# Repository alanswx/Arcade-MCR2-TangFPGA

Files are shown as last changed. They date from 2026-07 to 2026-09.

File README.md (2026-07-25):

# Bally Midway MCR2 Arcade Core for Gowin Tang FPGAs

Standalone port of the Bally Midway MCR arcade families for Sipeed Tang
FPGA boards — no MiSTer/HPS required. **MCR-2** (Tron, Domino Man,
Satan's Hollow, Wacko, Kozmik Kroozr, Two Tigers), **MCR-3/91490**
(Tapper — hardware-verified — plus Timber and Discs of Tron), and
**MCR-1** (Kick, Kickman, Solar Fox; builds, unverified). The flagship
target is the **Tang Console 60K**: each family's games in one bitstream,
selected at runtime from an on-screen menu, ROMs loaded from a single
microSD card shared by every family (pack format v2). The roadmap toward
the full-series multi-core jukebox is at the top of TODO.md.

| Board | Status |
|---|---|
| **Tang Console 60K** (GW5AT-60) | MCR-2: all six games + OSD menu. MCR-3: Tapper working (SDRAM sprites), Timber/DoT staged. 720p HDMI with audio (DDR3 framebuffer); analog RGB at 31/15 kHz for real cabinets; USB gamepad; SD ROM loading; <10 s watchdog-guarded cold boot |
| Tang Primer 25K (GW5A-25) | Domino Man over HDMI (single game per build, BSRAM-limited) |
| Tang Console 138K (GW5AST-138) | Stale — needs the 60K backport |

New here? Read [handoff_v7_jukebox.md](handoff_v7_jukebox.md) for the
current platform state and runway.

Deeper docs: build gotchas and architecture notes in [CLAUDE.md](CLAUDE.md),
open issues in [TODO.md](TODO.md), bench hookup in
[docs/bench_wiring.md](docs/bench_wiring.md), cabinet shield spec in
[docs/universal_mcr_shield_spec.md](docs/universal_mcr_shield_spec.md),
porting plan for the other MCR generations in
[docs/mcr_core_roadmap.md](docs/mcr_core_roadmap.md).

---

## 1. Generate the ROM hex tables

ROM zips (MAME sets) go in `roms/` — they are **not** in the repo. Then,
from the repo root:

```sh
python3 tools/merge_roms.py tron     # or domino / shollow / wacko / kroozr / twotiger
```

This writes the `rom_*.hex` tables the build bakes into BSRAM and sets the
board's `game_config.vh`. On the 60K the baked game only decides **what
boots with no SD card** — every game is reachable at runtime from the OSD.

## 2. Build

Headless (recommended; macOS paths shown — see CLAUDE.md for why the IDE
flow needs extra care):

```sh
GWLIB=/Applications/GowinIDE.app/Contents/Resources/Gowin_EDA/IDE/lib
GW=/Applications/GowinIDE.app/Contents/Resources/Gowin_EDA/IDE/bin/gw_sh
cd mcr2_console60k
DYLD_LIBRARY_PATH="$GWLIB" DYLD_FRAMEWORK_PATH="$GWLIB" "$GW" build.tcl
```

The bitstream lands at `mcr2_console60k/impl/pnr/mcr2_console60k.fs`.
Prebuilt images for all six games are kept in `bitstreams/`.

IDE builds work too (open `mcr2_console60k/mcr2_console60k.gprj`, Run All)
but several project settings must be exactly right — read the Gotchas
table in CLAUDE.md first; in particular **Place & Route → Place Option
must be 2** or HDMI silently dies.

## 3. Flash the board

With [openFPGALoader](https://github.com/trabucayre/openFPGALoader)
(`brew install openfpgaloader`), board connected over USB-C:

```sh
# quick test - loads SRAM, lost at power-off
openFPGALoader -b tangconsole bitstreams/console60k_tron.fs

# make it the POWER-ON default - writes the SPI flash
openFPGALoader -b tangconsole -f bitstreams/console60k_tron.fs
```

The `-f` form replaces whatever was in flash (e.g. NESTang) — reflash that
the same way if you want it back. The Gowin Programmer GUI works as well
(External Flash Mode → exFlash Erase, Program).

## 4. Make the SD card (all six games, switchable from the menu)

The ROM pack lives in **raw sectors starting at sector 2048** (1 MiB in) —
no filesystem involved, and it coexists with a normally-formatted card
(standard SD formatting starts the first partition at 4 MiB+; existing
files are untouched).

```sh
python3 tools/make_rompack.py                 # builds mcr_rompack.img from roms/
sudo python3 tools/write_rompack.py           # lists candidate cards
sudo python3 tools/write_rompack.py disk4     # writes + verifies (macOS)
```

`write_rompack.py` refuses to touch anything that is not a removable disk,
refuses cards whose partitions would overlap the pack, and verifies the
header after writing. On Linux/Windows use the `dd`/Win32DiskImager recipe
that `make_rompack.py` prints.

Put the card in the **console's** microSD slot. Every game you select in
the OSD is saved to the card (a reserved sector below the pack), and the
next power-on boots straight back into it - so a cabinet owner picks a
game once and it sticks. With no card (or a blank prefs sector) the
baked-in game boots.

## 5. Play

- **USB gamepad** in the left USB-A port: D-pad = joystick, A = Button 1,
  Start = Start 1, Select = Coin 1 (B/X/Y vary per game — see the input
  maps in `mcr2_console60k_top.sv`).
- **Select+Start opens the game-select menu** on every video output:
  Up/Down move, A loads the highlighted game from the SD card, B exits.
  The screen freezing (HDMI) or dropping sync (analog) for ~1 s after
  pressing A is the ROM reload, not a crash.
- Board keys: AA13 = reset, AB13 = Coin 1.
- HDMI is always live at 720p. Analog RGB comes out of the J10 header
  (31 kHz VGA, or jumper J10-37 to GND for native 15 kHz arcade timing) —
  wiring recipes in [docs/bench_wiring.md](docs/bench_wiring.md).
- A UART status beacon prints on the USB-C serial port (115200 8N1) for
  case-closed debugging — field decoding in docs/bench_wiring.md.

## 6. Cabinet integration

The goal is a drop-in board for real MCR cabinets: analog 15 kHz RGB,
original harness connectors, physical DIPs for game options. For anyone
building the PCB: the **frozen 40-pin header sheet is
[docs/shield_j10_pinout.md](docs/shield_j10_pinout.md)** — one header
carries video, audio and all controls (inputs via a 74HC165 chain that
covers every game, outputs via 74HC595). The consolidated electrical spec
is [docs/universal_mcr_shield_spec.md](docs/universal_mcr_shield_spec.md);
per-game harness pinouts are in
[docs/mcr_game_input_matrix.md](docs/mcr_game_input_matrix.md).

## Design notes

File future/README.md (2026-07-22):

# future/ — parked cores (not in any build)

Vendored-and-adapted cores that are **out of scope for the current board
revision** and deliberately excluded from the build/OSD roster. They stay
here, ready, until a board revision that supports what they need.

## mcr3mono.vhd — MCR3Mono (Rampage, Sarge, Max RPM, Power Drive, Star Guards)

**Parked for a future board revision** (2026-07). The core is vendored and
platform-adapted (dprams + hcnt_out; see the git history and
`docs/mcr_core_roadmap.md` Phase E), but the MCR3Mono *board* is a different
target from the SSIO-family shield rev A:

- **Different cabinet connectors.** The mono board routes its SSIO input
  ports to different physical connectors than the SSIO board (mono:
  IP0/IP1→J2, IP2→J3, IP4→J4), so it needs its own connector set — the
  rev-A shield targets the SSIO-family connectors only.
- **3 players.** Rampage is 3-player (P1/P2/P3 sticks + buttons), beyond the
  1–2 player layout the current shield/board is scoped for.
- **Analog controls.** Max RPM uses potentiometer wheels/pedals via an
  ADC0844 — needs the (populate-optional) ADC block, which is itself a
  later shield addition.

To bring it back: move `mcr3mono.vhd` to `src/rtl/`, vendor its sound stack
(`cpu09l_128a.vhd` = Turbo Cheap Squeak's 6809, `turbo_cheap_squeak.vhd`,
`sounds_good.vhd` = FX68K, `pia6821.vhd`, FX68K — all verified Gowin-clean
in `refs/Arcade-MCR3Mono_MiSTer/`), and build the mono board per Phase E.
Once Turbo Cheap Squeak exists, `demoderb` (4-player Demolition Derby) also
becomes reachable on the existing MCR-2 core.

Not parked here: MCR3Scroll (Spy Hunter / Crater / Turbo Tag) stays in the
active roster — it uses the SSIO-family connectors, and Spy Hunter's ADC is
the same populate-optional block.

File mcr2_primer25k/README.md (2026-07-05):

# Midway MCR2 Arcade Core for Sipeed Tang Primer 25K

This repository contains the standalone, hardcoded port of Bally Midway's MCR2 arcade core (supporting games like *Satan's Hollow*, *Tron*, etc.) for the **Sipeed Tang Primer 25K (Gowin GW5A-LV25MG)** development board.

Version 1 hardcodes **Satan's Hollow** directly into the internal block RAM (BSRAM) of the FPGA, allowing it to boot instantly upon power-up without needing external SDRAM or MicroSD configuration.

---

## 1. Project Features
* **Standalone Execution:** Runs entirely on the GW5A-25's internal Block RAM (BSRAM) and Distributed RAM (SSRAM/LUTs).
* **Concurrent Video Output:** Generates upscaled DVI/HDMI (480p @ 60Hz) for desk debugging and raw 15kHz digital RGBS + CSync for mounting inside an original arcade cabinet.
* **PWM Stereo Audio:** Delta-Sigma DACs modulate 16-bit sound samples to 1-bit high-frequency PWM outputs.

---

## 2. Compilation Instructions

1. Launch the **Gowin IDE** on your PC.
2. Select **Open Project** and select `mcr2_primer25k.gprj`.
3. Verify that all source files under `src/` are listed and enabled.
4. Click **Run All** in the IDE tool bar. This executes Synthesis, Mapping, and Place & Route to output `mcr2_primer25k.fs` under the `impl/pnr/` directory.
5. Alternatively, via command line using the Gowin EDA shell (`gw_sh`):
   ```bash
   # Set library path (macOS only)
   export DYLD_LIBRARY_PATH=/Applications/GowinIDE.app/Contents/Resources/Gowin_EDA/IDE/lib
   # Run compile script
   /Applications/GowinIDE.app/Contents/Resources/Gowin_EDA/IDE/bin/gw_sh build.tcl
   ```
6. Open **Gowin Programmer**, connect the board's JTAG, scan, and program the `.fs` bitstream file to the FPGA.

---

## 3. Hardware Wiring Guide

All cabinet interfaces are mapped to the **PMOD 1** header and the **40-pin SDRAM connector** on the Tang Primer 25K Dock baseboard. 

### A. PMOD 1 Header: Cabinet Controls (Buttons/Joystick)
Wired inputs have internal **Pull-Ups enabled** on the FPGA. Wire arcade button switches to bridge these pins directly to the board's **Ground (GND)** when pressed:

| PMOD 1 Pin | FPGA Pin | Signal Name | Cabinet Button Function |
| :--- | :--- | :--- | :--- |
| **Pin 1** | A11 | `btn_shield` | P1 Shield Button / Button 2 |
| **Pin 2** | E11 | `btn_fire` | P1 Fire Button / Button 1 |
| **Pin 3** | K11 | `btn_right` | P1 Joystick Right |
| **Pin 4** | L5 | `btn_left` | P1 Joystick Left |
| **Pin 7** | A10 | `btn_tilt` | Cabinet Tilt Switch |
| **Pin 8** | E10 | `btn_service`| Cabinet Service Switch |
| **Pin 9** | L11 | `btn_coin` | Coin 1 Switch |
| **Pin 10**| K5 | `btn_start` | P1 Start Button |
| **GND** | GND | Ground | Connect to the common chain of all buttons |
| **VCC** | 3.3V | VCC | (Do not connect for button switches) |

---

### B. 40-Pin Header: Cabinet Video (RGBS) & Audio
Raw 15kHz digital video outputs, syncs, and PWM audio are routed to the 40-pin header (which is unused since SDRAM is disabled):

| 40-Pin Header Pin | FPGA Pin | Signal Name | Function |
| :--- | :--- | :--- | :--- |
| **Pin 15** | K2 | `cab_r[0]` | Red Digital LSB (Bit 0) |
| **Pin 16** | K1 | `cab_r[1]` | Red Digital Middle (Bit 1) |
| **Pin 17** | L1 | `cab_r[2]` | Red Digital MSB (Bit 2) |
| **Pin 18** | L2 | `cab_g[0]` | Green Digital LSB (Bit 0) |
| **Pin 19** | K4 | `cab_g[1]` | Green Digital Middle (Bit 1) |
| **Pin 20** | J4 | `cab_g[2]` | Green Digital MSB (Bit 2) |
| **Pin 21** | G1 | `cab_b[0]` | Blue Digital LSB (Bit 0) |
| **Pin 22** | G2 | `cab_b[1]` | Blue Digital Middle (Bit 1) |
| **Pin 23** | E1 | `cab_b[2]` | Blue Digital MSB (Bit 2) |
| **Pin 24** | A1 | `cab_hs` | Horizontal Sync |
| **Pin 25** | F2 | `cab_vs` | Vertical Sync |
| **Pin 26** | F1 | `cab_csync` | Composite Sync (CSync) |
| **Pin 28** | B2 | `audio_l` | Left Audio PWM Output |
| **Pin 29** | C2 | `audio_r` | Right Audio PWM Output |
| **GND** | GND | Ground | Common Ground |

---

## 4. Connecting to an Analog Arcade Monitor

Arcade CRT monitors (like Wells Gardner or Electrohome) expect **analog RGB** signals ($0\text{V} - 0.7\text{V}$) terminated into $75\ \Omega$ load, and composite sync.

### Resistor Ladder DAC (R2R) Diagram
Build three identical weighted-resistor networks (one for Red, one for Green, one for Blue) to scale the digital 3-bit outputs to analog levels:

```text
                 Resistors
FPGA Pin (MSB)   [Bit 2] ---[ 1k Ohm ]---+
FPGA Pin         [Bit 1] ---[ 2k Ohm ]---+----> Analog Color Output (to CRT)
FPGA Pin (LSB)   [Bit 0] ---[ 4k Ohm ]---+
```

*For absolute accuracy, use $1.0\text{k}\ \Omega$, $2.0\text{k}\ \Omega$, and $3.9\text{k}\ \Omega$ (or $4.02\text{k}\ \Omega$) metal film resistors.*

### Composite Sync (CSync) Wiring
Arcade monitors expect a composite sync signal. The core produces digital `cab_csync` (3.3V).
* Route the `cab_csync` pin (Pin 26) through a **$100\ \Omega$ to $330\ \Omega$ resistor** directly to the composite sync pin of your chassis. This limits the current and matches standard TTL sync inputs.

---

## 5. Connecting Audio
The `audio_l` and `audio_r` signals are 1-bit high-frequency PWM outputs. 
* To feed an audio amplifier, connect the pin through a simple low-pass RC filter to extract the analog waveform:

```text
FPGA Audio Pin -----[ 270 Ohm ]---+-----> Analog Out (to Amp)
                                  |
                                 === 100nF Capacitor
                                  |
                                 GND
```

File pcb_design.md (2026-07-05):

# Universal MCR Daughterboard PCB Design Specification

This document details the physical layout, component placement, and schematic netlist for the **Universal Bally Midway MCR Cabinet Interface Shield** designed to host the **Tang Console 60K/138K**. It includes an ASCII floorplan and a **KiCad Python Script** to programmatically generate the board layout.

---

## 1. PCB Floorplan (ASCII Layout Sketch)

The PCB is designed as a compact carrier shield (approx. **95mm x 85mm**) that sits directly underneath the Tang Console board, exposing the original cabinet connectors along the top and bottom edges.

KiCad Layout Render

```text
+-----------------------------------------------------------------------------------+
|  [J2: P1 Ctrl]     [J3: Coin/Start]      [Video Output]       [Power Input +12V]  |
|  (Molex 15-pin)      (Molex 5-pin)        (Molex 9-pin)         (Screw Terminal)  |
|                                                                                   |
|    +---------------------------------------------------------+   +------------+   |
|    |               Tang Console 60K/138K Socket              |   | 5V Buck    |   |
|    |               (Exposes 2x20 Pin Header 1)               |   | Regulator  |   |
|    +---------------------------------------------------------+   +------------+   |
|                                                                                   |
|  [Optocouplers]                                                  [Audio Amp]      |
|  (TLP281-4)                                                      (LM386 + Caps)   |
|                                                                                   |
|    +---------------------------------------------------------+   [Audio Out]      |
|    |               Tang Console 60K/138K Socket              |   (Screw Term)     |
|    |               (Exposes 2x20 Pin Header 2)               |                    |
|    +---------------------------------------------------------+                    |
|                                                                  [DAC Resistors]  |
|                                                                  (R2R Networks)   |
|  [J5: P2 / Trackball]                 [J4: Opt X / Spinner]                       |
|  (Molex 19-pin)                         (Molex 10-pin)                            |
|                                                                                   |
|                     [SW1: Game Sel]      [SW2: Options]                           |
|                     (8-Position DIP)     (8-Position DIP)                         |
+-----------------------------------------------------------------------------------+
```

---

## 2. Schematic Netlist Configuration

The daughterboard connects the Tang Console 2x20 headers directly to the cabinet connectors and onboard modules:

### Power Distribution Nets
*   `+12V_CAB` $\rightarrow$ Screw Terminal Pin 1 $\rightarrow$ Audio Amp VCC, Buck Regulator Input.
*   `GND` $\rightarrow$ Common ground across all connectors, switches, and regulators.
*   `+5V_REG` $\rightarrow$ Buck Regulator Output $\rightarrow$ Tang Console 5V input pins (Header 1).
*   `+3.3V_FPGA` $\rightarrow$ Tang Console 3.3V output pins (Header 2) $\rightarrow$ DIP Switch pull-ups, optocoupler output pull-ups.

### Video DAC Nets
*   `cab_r[2:0]` $\rightarrow$ R2R Resistor Network $\rightarrow$ `MCR_RED` $\rightarrow$ `Video-1`
*   `cab_g[2:0]` $\rightarrow$ R2R Resistor Network $\rightarrow$ `MCR_GREEN` $\rightarrow$ `Video-3`
*   `cab_b[2:0]` $\rightarrow$ R2R Resistor Network $\rightarrow$ `MCR_BLUE` $\rightarrow$ `Video-5`
*   `cab_hs` $\rightarrow$ NPN Transistor Buffer $\rightarrow$ `MCR_HSYNC` $\rightarrow$ `Video-8`
*   `cab_vs` $\rightarrow$ NPN Transistor Buffer $\rightarrow$ `MCR_VSYNC` $\rightarrow$ `Video-9`
*   `Video GND` $\rightarrow$ Connected directly to `GND` $\rightarrow$ `Video-2, Video-4, Video-6`

---

## 3. KiCad PCB Python Generation Script

To programmatically build this board, open KiCad's **PCB Editor**, open the **Scripting Console** (`Tools -> Scripting Console`), copy the Python script below, and run it. It will automatically initialize the board, draw the edge cuts, and place the critical connector headers at their exact coordinates.

```python
import pcbnew
from pcbnew import wxPoint, wxSize, EDA_IU_TO_MM

def generate_mcr_shield():
    # Initialize a new board project
    board = pcbnew.GetBoard()
    if not board:
        board = pcbnew.BOARD()
        pcbnew.SetActiveBoard(board)

    # Clean existing items
    board.DeleteAll()

    # Define board dimensions: 120mm x 100mm (values in micrometers)
    width = 120.0
    height = 100.0
    margin = 5.0

    # Draw PCB Edge Outline on the Edge.Cuts layer
    edge_layer = board.GetLayerID("Edge.Cuts")
    
    # Coordinates in nanometers (1mm = 1,000,000 nm)
    x_min, y_min = int(margin * 1000000), int(margin * 1000000)
    x_max, y_max = int((width + margin) * 1000000), int((height + margin) * 1000000)

    corners = [
        wxPoint(x_min, y_min),
        wxPoint(x_max, y_min),
        wxPoint(x_max, y_max),
        wxPoint(x_min, y_max)
    ]

    for i in range(4):
        p1 = corners[i]
        p2 = corners[(i + 1) % 4]
        seg = pcbnew.PCB_SHAPE(board)
        seg.SetShape(pcbnew.SHAPE_T_SEGMENT)
        seg.SetStart(p1)
        seg.SetEnd(p2)
        seg.SetLayer(edge_layer)
        board.Add(seg)

    print("PCB Edge Outline drawn successfully!")

    # Helper function to place standard connectors/pin headers
    def place_connector(reference, value, footprint_name, x_mm, y_mm, rotation_deg=0):
        # Load standard KiCad connector footprints
        footprint = pcbnew.FootprintLoad(board.GetProject(), footprint_name)
        if not footprint:
            # Fallback to standard library connector if custom not loaded
            footprint = pcbnew.FootprintLoad("", "Connector_PinHeader_2.54mm:PinHeader_1x02_P2.54mm_Vertical")
        
        if footprint:
            footprint.SetReference(reference)
            footprint.SetValue(value)
            
            # Position (convert mm to nanometers)
            pos = wxPoint(int(x_mm * 1000000), int(y_mm * 1000000))
            footprint.SetPosition(pos)
            footprint.SetOrientation(rotation_deg * 10) # KiCad expects 10th of a degree
            
            board.Add(footprint)
            print(f"Placed {reference} ({value}) at X={x_mm}mm, Y={y_mm}mm")

    # --- Place Connectors and Headers ---
    # 1. Tang Console Host Sockets (2x20 Pin Headers spaced 50mm apart)
    place_connector("JP1", "Tang_2x20_H1", "Connector_PinHeader_2.54mm:PinHeader_2x20_P2.54mm_Vertical", 65.0, 45.0)
    place_connector("JP2", "Tang_2x20_H2", "Connector_PinHeader_2.54mm:PinHeader_2x20_P2.54mm_Vertical", 65.0, 65.0)

    # 2. MCR Top Connectors (Controls, Coin, Video, Power)
    place_connector("J2", "MCR_P1_Controls", "Connector_PinHeader_2.54mm:PinHeader_1x15_P2.54mm_Vertical", 20.0, 12.0)
    place_connector("J3", "MCR_System_Coin", "Connector_PinHeader_2.54mm:PinHeader_1x05_P2.54mm_Vertical", 55.0, 12.0)
    place_connector("J_VID", "MCR_Video_Out", "Connector_PinHeader_2.54mm:PinHeader_1x09_P2.54mm_Vertical", 85.0, 12.0)
    place_connector("P_IN", "Power_+12V_GND", "Connector_PinHeader_2.54mm:PinHeader_1x02_P2.54mm_Vertical", 115.0, 12.0)

    # 3. MCR Bottom Connectors (P2 Controls, Spinners, DIP Switches)
    place_connector("J5", "MCR_P2_Controls", "Connector_PinHeader_2.54mm:PinHeader_1x19_P2.54mm_Vertical", 25.0, 93.0)
    place_connector("J4", "MCR_Opt_X_Dial", "Connector_PinHeader_2.54mm:PinHeader_1x10_P2.54mm_Vertical", 75.0, 93.0)
    
    # 4. DIP Switch Blocks
    place_connector("SW1", "Game_Selector", "Button_Switch_THT:SW_DIP_SPSTx08_Slide_9.78x22.5mm_W7.62mm_P2.54mm", 100.0, 93.0)
    place_connector("SW2", "Cabinet_Options", "Button_Switch_THT:SW_DIP_SPSTx08_Slide_9.78x22.5mm_W7.62mm_P2.54mm", 115.0, 93.0)

    # Refresh KiCad canvas view
    pcbnew.Refresh()

# Execute script
generate_mcr_shield()
```

---

## 4. Power Supply & Level-Shifting Specification

Arcade cabinets are electrically noisy environments. Proper power isolation and input level-shifting are critical to ensure that the delicate FPGA logic is not damaged and does not suffer from glitches.

### A. Power Supplies Required
Original MCR cabinets deliver:
1.  **+5V DC (Logic):** Used to power TTL ICs on the original boards.
2.  **+12V DC (Audio):** Used to run the audio power amplifiers.
3.  **-5V DC (Bias):** Used only by legacy dynamic RAMs (4116 DRAM). 
    *   *Our core runs 100% on-chip static BRAM, so **we do not need the -5V rail at all**.*

**How we power the FPGA:**
*   We route the cabinet's **+12V DC rail** to an onboard **step-down Buck Regulator module** (e.g. LM2596 or similar buck converter) on our shield. The regulator outputs a rock-solid, filtered **+5.0V DC** (1.5A rating) which is routed directly to the Tang Console's 5V input pin.
*   This isolates the FPGA from noise on the cabinet's main +5V logic lines and prevents brownouts when solenoids or coin door lights trigger.

### B. Input Level-Shifting (Cabinet Controls)
*   **The Hazard:** Standard arcade cabinet switches can pick up high-voltage static shocks (ESD) or line noise from the CRT monitor. Since the Gowin FPGA GPIOs are **strictly 3.3V tolerant**, connecting long wire loops directly to the pins will eventually destroy the FPGA.
*   **The Solution (Optocouplers):** We place **TLP281-4 (or EL817-4) quad optocouplers** on all cabinet input lines (joysticks, buttons, coins).
    *   The cabinet loop runs at +5V/12V through the optocoupler's input LED.
    *   When a switch is closed, it triggers the internal LED.
    *   The output photo-transistor bridges the FPGA GPIO directly to `GND` (pulled up to `+3.3V` internally).
    *   This provides **100% electrical isolation** between the cabinet and the FPGA.

### C. Output Level-Shifting (Video Sync)
*   **Sync Signals:** Arcade CRT monitors expect **5V TTL composite sync** signals. The FPGA outputs 3.3V. While some monitors may work, it is best practice to place a buffer IC (like a **74LVC244** or **74HCT244**) powered by +5V to step up the 3.3V HSync, VSync, and CSync signals to solid 5V TTL levels before routing them to the video connector.
*   **RGB Colors:** The R2R resistor network naturally performs the level-shifting from 3.3V digital logic to the analog 0.7V peak-to-peak expected by the CRT monitor. **No active buffer or level shifter is needed for RGB signals.**

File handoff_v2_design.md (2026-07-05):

# MCR2 Port V2 Handoff & PCB Design Specification

This document details the architectural path to upgrade the core to **Version 2 (SDRAM support)** and outlines the electrical/physical requirements to design a custom **Universal Bally Midway MCR Cabinet Interface Shield (Option A)** that plugs into the Tang Primer 25K Dock.

---

## 1. SDRAM Integration & Core Changes (V2)

In Version 1, the playfield background tile ROMs were disabled to free up Block RAM (BSRAM) blocks for the active RAM caches and line buffers. In Version 2, we will add the external SDRAM controller to store all ROM assets, freeing up internal BSRAM and enabling playfield graphics and cabinet artwork overlays.

```mermaid
graph TD
    Flash[SPI Flash / SD Card] -->|Boot Loader| SDRAM_Ctrl[SDRAM Controller]
    SDRAM_Ctrl <--> SDRAM[External SDRAM Module]
    Z80_Main[Z80 CPU Main] -->|Instruction Fetch| SDRAM_Ctrl
    Z80_Snd[Z80 CPU Sound] -->|Instruction Fetch| SDRAM_Ctrl
    Gfx_Gen[Graphics Generator] -->|Tile Read| SDRAM_Ctrl
```

### Key Changes Required in RTL
1. **Porting the SDRAM Controller:**
   * Copy the SDRAM controller from the Nestang project ([sdram.sv](file:///Users/alans/Documents/development/TangPrimer-25K-example/nestang_primer-25K/src/rtl/sdram.sv)). The Primer 25K SDRAM module is a standard SDR-SDRAM (typically 64Mbit or 128Mbit with a 16-bit wide data bus).
2. **Boot ROM Loader:**
   * Implement a boot loader state machine in the top wrapper (`mcr2_primer25k_top.sv`). 
   * On reset, this loader reads the game ROM binaries from the SPI Flash (at a offset like `0x100000`) or from a MicroSD card via SPI, and streams them into the SDRAM.
   * Once loading is done, the Z80 reset line is released and the game runs.
3. **Memory Bus Arbitration:**
   * Since the main CPU, sound CPU, sprite generator, and background generator all need to read from SDRAM, you must implement a simple round-robin arbiter inside the controller. The controller runs at **100MHz+**, giving enough bandwidth to multiplex requests from all four subsystems.
4. **Restoring Graphics in `mcr2.vhd`:**
   * Re-enable the instantiations of `bg_graphics_1` and `bg_graphics_2` and change their generic memory type to point to SDRAM read requests instead of internal `dpram` instances.

---

## 2. Universal MCR Cabinet Interface Shield PCB Design

Rather than translating signals to a modern standard like JAMMA, the shield can expose the **original Bally Midway MCR header connectors (J2, J3, J4, J5, and Video)**. 

This creates a **direct drop-in replacement** for the original bulky Bally Midway CPU board. You can unplug the original board from the cabinet, and plug the Tang Primer 25K + Dock + Shield assembly directly into the cabinet's original wire harness.

### Why No DIP Switches Are Needed:
As documented in the `Ultimate MCR Master Pinout Matrix`, the physical connectors and pinout routing are standard across all MCR-1, MCR-2, and MCR-3 games. 
* A physical pin like **J2-1** is routed to standard player controls in all cabinets, but its function changes depending on the game (e.g. Up in *Tron*, Left in *Satan's Hollow*, Machine Gun in *Spy Hunter*).
* Because all J2/J3/J4/J5 pins are routed to static, dedicated FPGA GPIO inputs, **no physical DIP switches or rewiring is needed on the PCB**. The mapping of inputs to gameplay functions is handled **entirely in the SystemVerilog wrapper** of each specific game core!

```
                    +------------------------------------+
                    |        Tang Primer 25K Dock        |
                    +---[PMOD 1]------------[40-Pin]-----+
                              |                |
                       Parallel GPIOs     Parallel GPIOs
                              |                |
                    +------------------------------------+
                    |       Universal MCR Shield PCB     |
                    +--[J2]----[J3]----[J4]----[J5]--[V]-+
```

### A. Power Delivery
The original MCR cabinet harness provides **+12V** (for audio amps) and **+5V** (for logic).
* Place a **5V step-down buck converter** on the shield to feed clean +5V into the Dock's power inputs.
* Route the +12V rail directly to the onboard audio amplifier.

### B. Input Protection & Level Shifting
Arcade cabinet buttons are connected to long wire harnesses that act as antennas for ESD and electromagnetic noise.
* Use **opto-isolators** (e.g., TLP281-4) or logic buffers (e.g., 74LVC244) to isolate cabinet inputs from the FPGA.
* Use external 4.7kΩ pull-up resistors to 5V on the cabinet side of the buffers to keep inputs stable.

```
 Cabinet Switch (GND) ---> [ 4.7k Pull-up to 5V ] ---> [ Optocoupler / Buffer ] ---> FPGA Pin (3.3V)
```

### C. Analog Video DAC (RGB + Sync)
Midway MCR games output video at a 15kHz horizontal sync rate. The daughterboard must convert the 3-bit digital color lines (`cab_r/g/b`) to standard analog $1\text{V}_{\text{p-p}}$ video.
* **Resistor Ladder DAC (R2R):** Use standard 1% resistors to build an R2R ladder DAC for the red, green, and blue outputs.
* **Sync Buffers:** Convert the digital Sync outputs (`cab_hs` and `cab_vs` or `cab_csync`) from 3.3V to 5V TTL levels using a simple NPN transistor driver (like the BC847) before sending them to the original MCR Video connector.

```
 cab_r[2] (MSB) ---> [ 510 Ohm ] ---+
                                    |---> Analog Red (75 Ohm load on monitor)
 cab_r[1]       ---> [  1k Ohm  ] ---+
 cab_r[0] (LSB) ---> [  2k Ohm  ] ---+
```

### D. Audio Circuit
* Route the `audio_l` and `audio_r` pins through a dual-stage RC low-pass filter (cutoff frequency around 15kHz) to smooth the digital PWM into analog audio.
* Feed the analog audio into an audio amplifier chip (e.g., **LM386** or **TDA2003**) powered by the +12V rail, and connect the output to the mono speaker terminals.

---

## 3. Recommended Pinout Mapping (Dock to MCR Connectors)

Below is the pin mapping showing how the FPGA's expansion ports should route to the standard MCR J2, J3, J4, and J5 headers.

### J2 Connector (Player 1 Controls)
| Pin | Standard MCR Function | Dock Pin |
| :--- | :--- | :--- |
| **J2-1** | P1 Up / P1 Left / Weapon 1 | PMOD 1.4 (L5) |
| **J2-2** | P1 Down / P1 Right / Weapon 2 | PMOD 1.10 (K5) |
| **J2-3** | P1 Left / Utility Button | PMOD 1.3 (K11) |
| **J2-4** | P1 Right / Utility Button | PMOD 1.9 (L11) |
| **J2-5** | P1 Button 1 (Fire / Serve / Kick) | PMOD 1.2 (E11) |
| **J2-6** | P1 Button 2 (Shield / Catch / Deflect) | PMOD 1.1 (A11) |
| **J2-13**| Ground | PMOD 1.5 (GND) |

### J3 Connector (System & Coins)
| Pin | Standard MCR Function | Dock Pin |
| :--- | :--- | :--- |
| **J3-1** | Coin 1 | PMOD 1.9 (L11) *shared/dual-mapped* |
| **J3-2** | Coin 2 | PMOD 1.8 (E10) |
| **J3-3** | Start 1 | PMOD 1.10 (K5) *shared/dual-mapped* |
| **J3-4** | Start 2 | PMOD 1.7 (A10) |
| **J3-5** | Tilt Switch | PMOD 1.7 (A10) *shared/dual-mapped* |

### J4 Connector (Opt X / Spinner / Steering Dial)
These pins handle the 8-bit parallel dial/spinner outputs (like Tron's spinner wheel or Spy Hunter's steering):
| Pin | Standard MCR Function | Dock Pin |
| :--- | :--- | :--- |
| **J4-1** | Data Bit 0 (Opt X) | 40-Pin 5 (H4) |
| **J4-2** | Data Bit 1 (Opt X) | 40-Pin 6 (G4) |
| **J4-3** | Data Bit 2 (Opt X) | 40-Pin 7 (J2) |
| **J4-4** | Data Bit 3 (Opt X) | 40-Pin 8 (J8) |
| **J4-5** | Data Bit 4 (Opt X) | 40-Pin 9 (J1) |
| **J4-6** | Data Bit 5 (Opt X) | 40-Pin 10 (D1) |
| **J4-7** | Data Bit 6 (Opt X) | 40-Pin 11 (L9) |
| **J4-9** | Data Bit 7 (Opt X) | 40-Pin 12 (K8) |
| **J4-10**| Ground | 40-Pin 2 (GND) |

### J5 Connector (Opt Y / Trackball / Player 2 Controls)
| Pin | Standard MCR Function | Dock Pin |
| :--- | :--- | :--- |
| **J5-1** to **J5-6** | Player 2 Mux / Trackball Y (D0 - D5) | 40-Pin 13 to 18 |
| **J5-15** | P2 Up / Trackball Y D6 | 40-Pin 19 |
| **J5-16** | P2 Down / Trackball Y D7 | 40-Pin 20 |
| **J5-17** | P2 Left | 40-Pin 21 |
| **J5-18** | P2 Right | 40-Pin 22 |
| **J5-19** | P2 Button 1 | 40-Pin 23 |

### Video Connector (MCR Standard)
| Pin | MCR Video Function | Dock / DAC Signal |
| :--- | :--- | :--- |
| **Video-1** | Red | Analog Red (from DAC on K2, K1, L1) |
| **Video-2** | Video GND | Video Ground |
| **Video-3** | Green | Analog Green (from DAC on L2, K4, J4) |
| **Video-4** | Video GND | Video Ground |
| **Video-5** | Blue | Analog Blue (from DAC on G1, G2, E1) |
| **Video-6** | Video GND | Video Ground |
| **Video-8** | H-Sync (-) | Sync Buffer (from F1 / A1) |
| **Video-9** | V-Sync (-) | Sync Buffer (from F2) |

---

## 4. Pinout Mapping for Tang Console 60K & 138K (2x20 Header Shield)

Because the **Tang Console 60K & 138K** cores fit entirely inside the FPGA's internal BRAM, you have **92 free GPIO pins** on the board's two 2x20-pin expansion headers. This allows for a completely parallel shield design with zero multiplexing or serial converters.

Below is the pin mapping between the original Bally Midway MCR harness and the 2x20 GPIO Header pins as defined in `mcr2_console60k.cst` and `mcr2_console138k.cst`:

### Cabinet Controls (J2 & J3)
| MCR Pin | Signal | 2x20 Header Pin Name | FPGA Pin |
| :--- | :--- | :--- | :--- |
| **J2-1** | P1 Up / Left | `btn_left` | A10 |
| **J2-2** | P1 Down / Right | `btn_right` | A11 |
| **J2-3** | P1 Left / Utility | `btn_fire` | B10 |
| **J2-4** | P1 Right / Utility | `btn_shield` | B11 |
| **J2-5** | P1 Button 1 (Fire) | `btn_start` | C10 |
| **J2-6** | P1 Button 2 (Shield) | `btn_coin` | C11 |
| **J3-1** | Coin 1 | `btn_service` | D10 |
| **J3-3** | Start 1 | `btn_tilt` | D11 |

### Cabinet Video (RGBS) & Audio Outputs
| MCR Pin | Signal | 2x20 Header Pin Name | FPGA Pin |
| :--- | :--- | :--- | :--- |
| **Video-1** | Analog Red | `cab_r[0]` (LSB) | F10 |
| | | `cab_r[1]` | F11 |
| | | `cab_r[2]` (MSB) | G10 |
| **Video-3** | Analog Green | `cab_g[0]` (LSB) | H10 |
| | | `cab_g[1]` | H11 |
| | | `cab_g[2]` (MSB) | J10 |
| **Video-5** | Analog Blue | `cab_b[0]` (LSB) | K10 |
| | | `cab_b[1]` | K11 |
| | | `cab_b[2]` (MSB) | L10 |
| **Video-8** | H-Sync (-) | `cab_hs` | M10 |
| **Video-9** | V-Sync (-) | `cab_vs` | M11 |
| | CSync (-) | `cab_csync` | N10 |
| | Audio Left PWM | `audio_l` | P10 |
| | Audio Right PWM | `audio_r` | P11 |

*Note: You can easily update these constraints in your target project's `.cst` file to match whatever layout you choose for your custom KiCad or Altium PCB Shield.*

---

## 5. DIP-Switch ROM Selection & Game Lists (Multi-Game Cabinet)

Instead of compiling an on-screen game loader, we can place a hardware **DIP Switch Block** on our custom Shield PCB to select which game boots from the MicroSD card. At power-on, the bootloader reads the states of these switches and writes the corresponding ROM assets into BRAM/DRAM, creating an authentic, menu-free arcade experience.

### A. Bally Midway MCR Game Lists

The Bally Midway MCR family is split into five hardware categories:

1. **MCR-1 (3 Games):**
   * *Kick / Kick-Man*
   * *Solar Fox*
2. **MCR-2 (6 Games):**
   * *Satan's Hollow*
   * *Tron*
   * *Kozmik Krooz'r*
   * *Wacko*
   * *Domino Man*
   * *Two Tigers*
3. **MCR-3 (4 Games):**
   * *Tapper*
   * *Discs of Tron*
   * *Journey*
   * *Timber*
4. **MCR-Scroll (3 Games):**
   * *Spy Hunter*
   * *Crater Raider*
   * *Turbo Tag*
5. **MCR-Monoboard (6 Games):**
   * *Demolition Derby*
   * *Rampage*
   * *Sarge*
   * *Power Drive*
   * *Max RPM*
   * *Star Guards*

*   **Total Unified Library:** **22 Games**

---

### B. Bit Requirements for DIP Switch Selection

To select a game from these lists, we need the following number of binary inputs:

*   **MCR-2 Only Multi-Game:** **3 Bits** ($2^3 = 8$ configurations, covers all 6 MCR-2 titles).
*   **MCR-3 Only Multi-Game:** **2 Bits** ($2^2 = 4$ configurations, covers all 4 MCR-3 titles).
*   **Fully Unified MCR Cabinet:** **5 Bits** ($2^5 = 32$ configurations, covers all 22 MCR games in the library).

### C. Recommended Hardware Design

We recommend placing an **8-position DIP Switch Block** on the custom Shield PCB. 
*   **Switch 1–5:** Game Selector (5 bits, representing binary values `0` to `31` for the 22 games).
*   **Switch 6–8:** System Config (e.g. Free Play force, Test Mode force, Cabinet CRT aspect/doubler bypass).

```text
               +5V / +3.3V
                 |
               [ 10k Pull-up Array ]
                 |
  FPGA GPIOs ----+-------+-------+-------+
                 |       |       |       |
               [SW1]   [SW2]   [SW3]   [SW4]  (DIP Switch Block)
                 |       |       |       |
                GND     GND     GND     GND
```
*   **Pins needed:** Since the **Tang Console 60K/138K** has 92 free GPIOs, allocating **8 dedicated pins** directly to these switches is trivial and leaves the board with massive IO capacity.

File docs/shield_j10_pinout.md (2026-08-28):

# Shield ↔ Tang Console 60K: the J10 40-pin header (rev A freeze)

**This is the authoritative pin sheet for the shield PCB.** It supersedes
the draft net plan in `universal_mcr_shield_spec.md` §4b (which spread
video onto the PMOD sockets); the shield now connects to **J10 only** —
video, audio and all controls on one 40-pin header, both PMOD sockets left
free. Electrical details (input-conditioning pads, DAC, buck) stay in the
spec §3; the cabinet-side connectors, pitches and chip wiring are in
**`docs/shield_wiring.md`**.

Ground rules:

- **Interface style (settled): the cabinet harness plugs into the shield.**
  The shield presents the original MCR mating connectors; the operator plugs
  the existing harness in and selects the game in the OSD — the FPGA maps
  every pin to its in-game function, so nothing is rewired. This is NOT a
  mechanical board-swap. **Rev A targets the SSIO-family connectors** (most
  games); MCR3Mono is a later variant. Full rationale + the connector
  target in `universal_mcr_shield_spec.md` §0.
- **Every J10 signal is 3.3 V LVCMOS (banks 6/7/8). Nothing is 5 V
  tolerant.** Cabinet-side 5 V never reaches a header pin: inputs land on
  the shield's **74AHC165s** (5.5 V-tolerant inputs — §2), never on the
  FPGA directly; sync/video leave through buffers/ladders.
- Pins marked **live** are driven by the bitstreams shipping today —
  video/audio works on the board the day it is soldered, with no gateware
  change. Pins marked **reserved** are allocated here and safe to route
  now; the expander RTL that drives them is a small, planned change
  (`TODO.md`). Until then they are high-Z from the FPGA.
- J10 is the 2×20, 2.54 mm header **nearest the PMOD sockets** (the other
  2×20, J9, is the SDRAM slot — the shield must leave it unobstructed).
  Odd/even pins face each other; anchor orientation electrically at
  **pin 11 = +5 V / pin 12 = GND**. Header is net-for-net identical on
  dock rev A (32001A) and rev C (32001C); ball map from the rev C SOM
  sheets (spec §4a/§6.2).

## 1. The 40 pins

| Pin | Ball | Net | Dir (FPGA) | Status | Function |
|---:|---|---|---|---|---|
| 1 | R19 | `AUD_PWM_L2` | out | **as built** | **Prototype board (2026-08-27) puts a second PWM audio pair here** (Discs of Tron Environmental has four independently driven speakers: front L/R on `AUD_PWM_L1/R1`, rear L/R on this pair, all line level to the cabinet's external amplifier PCB). Was `VID_R0`, which the DAC never used. RTL still drives `vga_r[0]` on this ball — harmless into the RC filter, but the bit must be retired and a second audio pair (or silence) driven before it is useful |
| 2 | P19 | `VID_R1` | out | live | red bit 1 → 2 kΩ |
| 3 | U21 | `VID_R2` | out | live | red bit 2 → 1 kΩ |
| 4 | T21 | `VID_R3` | out | live | red bit 3 (MSB) → 510 Ω |
| 5 | R17 | `AUD_PWM_R2` | out | **as built** | second PWM audio pair, right (see pin 1). Was `VID_B0` |
| 6 | P16 | `VID_B1` | out | live | blue bit 1 → 2 kΩ |
| 7 | T18 | `VID_B2` | out | live | blue bit 2 → 1 kΩ |
| 8 | R18 | `VID_B3` | out | live | blue bit 3 (MSB) → 510 Ω |
| 9 | W17 | `SERVICE_N` | in | reserved | cabinet service button (opens the OSD); shield pull-up to 3V3. **Moved here from pin 33 on 2026-08-23** when the prototype board took pin 33 for the '595 SRCLR - see `pcb_review_2026-08-22.md` |
| 10 | V17 | `SPARE1` | — | spare | CSI_B config pin — needs the `-use_sspi_as_gpio` build option (already set) |
| 11 | — | **+5 V** | — | power | **The shield FEEDS the console here** (decided 2026-08-23, `shield_power_decision.md`): shield R-78B5.0 → D4 1N5822 Schottky → pin 11, 1.0 mm trace. Nothing else may back-feed this rail |
| 12 | — | **GND** | — | power | star ground for the shield |
| 13 | W22 | `VID_G0` | out | live | green bit 0 (copy of bit 3) |
| 14 | W21 | `VID_G1` | out | live | green bit 1 → 2 kΩ |
| 15 | P17 | `VID_G2` | out | live | green bit 2 → 1 kΩ |
| 16 | N17 | `VID_G3` | out | live | green bit 3 (MSB) → 510 Ω |
| 17 | N14 | `VID_HS` | out | live | HSync, negative; carries **CSYNC** when strap pin 39 = GND |
| 18 | N13 | `VID_VS` | out | live | VSync, negative |
| 19 | V20 | `ADC_SDA` | inout | as built | ADS7830 I²C data (needs an I²C master in RTL; no pull-up on the board — use the FPGA's) |
| 20 | U20 | `ADC_SCL` | out | as built | ADS7830 I²C clock |
| 21 | Y22 | `LED_CALIB` | out | live | status LED: DDR3 trained (steady on = good) |
| 22 | Y21 | `LED_PIX` | out | live | status LED: pixel-clock heartbeat ~1 Hz |
| 23 | AB22 | `LED_27M` | out | live | status LED: 27 MHz heartbeat ~0.8 Hz |
| 24 | AB21 | `LED_DDR_RST` | out | live | status LED: DDR reset (steady OFF = good) |
| 25 | AA21 | `IN_CLK` | out | reserved | 74HC165 chain shift clock (≤2 MHz) |
| 26 | AA20 | `IN_LOAD_N` | out | reserved | 74HC165 SH/LD̄ — low pulse snapshots all inputs atomically |
| 27 | AB20 | `IN_DATA` | in | reserved | serial data from U7.QH (CSO_B config pin — option already set) |
| 28 | AA19 | `OUT_CLK` | out | reserved | 74HC595 chain shift clock (RDWR_B config pin — option already set) |
| 29 | AA18 | `ADC_A1` | out | as built | ADS7830 address bit 1. Dock caveat retired 2026-08-23: EXID0/1 pulls R30/R32 are DNP on sheet 8, so this is plain I/O |
| 30 | AB18 | `ADC_A0` | out | as built | ADS7830 address bit 0 |
| 31 | Y19 | `OUT_DATA` | out | reserved | serial data to U8.SER |
| 32 | Y18 | `OUT_LATCH` | out | reserved | 74HC595 RCLK — output register update |
| 33 | T20 | `OUT_CLEAR_N` | out | reserved | 74HC595 SRCLR̄ on U8/U9. **As built on the prototype board.** Was `SERVICE_N`; that moved to pin 9. Note this is an FPGA OUTPUT - drive it high in normal operation, and do not leave it floating or the output chain clears |
| 34 | N15 | `OUT_EN_N` | out | reserved | 74HC595 OE̅. **Shield MUST pull up to 3V3** so meters/lamps stay off until the RTL drives it low |
| 35 | U18 | `AUD_PWM_L` | out | live | PWM audio left → 2-stage RC → J3 (`AUD_PWM_L1` on the board) at line level; the cabinet's external dual-amplifier PCB does the rest (Mitch, 2026-08-28) |
| 36 | U17 | `AUD_PWM_R` | out | live | PWM audio right (`AUD_PWM_R1` on the board; mono cabinets: use L only) |
| 37 | R16 | `MODE15_N` | in | live | **strap: GND = native 15 kHz** (cabinet), open = 31 kHz. Internal pull-up; solder-jumper on shield, closed by default |
| 38 | P15 | `SPARE6` | — | spare | |
| 39 | R14 | `SYNC_CSYNC_N` | in | live | strap: GND = composite sync on `VID_HS`; open = separate H/V (**default — real MCR monitors take separate H/V on Video-8/9**) |
| 40 | P14 | `SYNC_VSOFF_N` | in | live | strap: GND = hold VS inactive (single-sync RGBS); open = normal |

Sanity check for layout review: 20 live signals + 3 straps + 8 reserved +
7 spare + 2 power = 40 exactly; every ball above matches spec §4a's
schematic-verified table, and every **live** pin matches what the current
bitstreams already drive (`bench_wiring.md`).

## 2. Power domains and level shifting (read this first)

**All logic on the shield runs at 3.3 V — the 74HC165s, the 74HC595s,
everything that touches a J10 pin. There are no level-shifter ICs
anywhere.** The board has exactly three voltage domains, and every
crossing between them is done by a part that is there for another reason
anyway:

| Domain | What lives in it | Crossing to/from |
|---|---|---|
| **3.3 V logic** (shield LDO from the buck's 5 V — J10 has no 3V3 pin) | shift registers, pull-ups, everything wired to J10 | is the FPGA's native level: direct connection |
| **5 V / cabinet harness** | switch loops (pulled to 5 V via 4.7 kΩ, switched to cabinet GND), monitor sync inputs | **inputs: the 74AHC165s themselves.** AHC inputs are rated to 5.5 V *independent of VCC*, so a 3.3 V-powered '165 legally takes the 5 V harness levels straight in — the shift register IS the level shifter. Each line gets a passive conditioning pad (below), nothing active. **sync out:** 74HCT244 powered at 5 V (its TTL thresholds accept 3.3 V swings — that is why HCT here) or a BC847 stage. **RGB out:** passive R2R ladder, no logic. |
| **12 V loads** | coin meters, lamps | ULN2803 Darlington array (3.3 V logic input is sufficient drive; built-in flyback diodes) |

Part-selection rules that follow:
- Input chain: **74AHC165** (TI SN74AHC165 / Nexperia 74AHC165) at
  VCC = 3.3 V. The load-bearing datasheet line is *"recommended input
  voltage up to 5.5 V regardless of VCC"* — verify it in the exact
  vendor/package chosen at order time. Thresholds at 3.3 V: VIH ≈ 2.3 V
  (5 V idle line: fine), VIL ≈ 1.0 V (closed switch: fine).
- **Plain 74HC165 will NOT work here** (inputs limited to VCC + 0.5 V —
  5 V in on a 3.3 V part is out of spec); 74HCT/74LS are 5 V-supply
  parts. The output '595 sees only 3.3 V signals, so 74HC595 or
  74AHC595 both work.
- The one deliberate HCT part is the 5 V sync buffer, chosen *because*
  of its TTL thresholds. The chain runs at 2 MHz — decades below any of
  these parts' limits.

**Why no optocouplers?** The earlier spec draft used TLP281-4s "for
isolation", but the shield's buck is non-isolated — cabinet ground and
logic ground are already common through the power path, so the optos
never provided galvanic isolation, only over-voltage protection. The
conditioning pad below provides that protection passively. (If a truly
isolated build is ever wanted, it needs an isolated supply first; the
opto variant is preserved in the spec's git history.)

## 3. Input chain — every switch in the cabinet on 3 pins

Seven 74HC165s daisy-chained, read through 3 header pins. `IN_LOAD_N`
snapshots **all 56 bits in the same instant**, which is what makes the
8-bit parallel spinner/trackball buses safe to serialize — no tearing, by
construction. A full scan at 2 MHz takes ~30 µs; the games poll their
inputs once per frame (16.7 ms), so the chain is ~500× faster than
anything the software can observe.

### 3a. Chain control lines ↔ J10 (bussed to all seven '165s)

| Signal | 74HC165 pin(s) | J10 pin | FPGA ball | Direction |
|---|---|---|---|---|
| `IN_CLK` | pin 2 (CP) on U1…U7 | 25 | AA21 | FPGA → chain |
| `IN_LOAD_N` | pin 1 (PL̄) on U1…U7 | 26 | AA20 | FPGA → chain |
| `IN_DATA` | pin 9 (QH) of **U7 only** | 27 | AB20 | chain → FPGA |
| cascade | U1.9 → U2.10, U2.9 → U3.10, … U6.9 → U7.10 | — | — | on-shield |
| tie-offs | pin 15 (CE̅) → GND, pin 10 (SER) of **U1** → GND, pin 7 (Q̄H) n/c, pin 16 → 3V3, pin 8 → GND | — | — | all devices |

Serial arrival order (RTL contract, not a PCB concern): after the load
pulse, bits arrive **U7 first, input H first** — U7.H, U7.G … U7.A, U6.H
… down to U1.A last.

### 3b. '165 inputs ↔ conditioning ↔ MCR harness, device by device

> **This section is the MCR-2 wiring example, and the J-labels below use the
> normalized *cabinet-function* numbering** (J2=P1, J3=coins, J4=Opt X,
> J5=Opt Y) from the master matrix — **not** the physical board connectors.
> The real connectors, their **pitch** (only J1 power is .156"; J2–J6 are
> .100" MTA) and the actual board numbering (J4=IP0+IP1, J5=IP2, J6=IP4) are
> in **`docs/shield_wiring.md`** — use that for footprints. For a board meant
> to run the whole family (3-player Rampage, the mono/scroll connector
> remapping), allocate the chain by SSIO input port — see §6(a). The
> electrical pad and control lines below are unchanged either way.

'165 input pins: A=11, B=12, C=13, D=14, E=3, F=4, G=5, H=6. Each
harness line gets the same passive pad — this is the whole input stage:

    harness pin ──┬── 4.7 kΩ pull-up to +5 V (shield rail)
                  └── 1 kΩ series ──┬── 74AHC165 input
                                    ├── 10 nF to GND (RC ≈ 10 µs — the
                                    │   same line filtering the SSIO had)
                                    └── BAT54S clamp to +5 V / GND
                                        (survives a 12 V miswire: the
                                        fault drops across the 1 kΩ)

Idle = 5 V = high, pressed = low — the same polarity the original SSIO
saw, read by a 3.3 V part with 5.5 V-tolerant inputs. All eight bits of a
dial bus share identical pads, so RC skew between bits is nil and the
atomic '165 load strobe samples a coherent word.

**U1 — player 1 + coins**

| '165 input | pin | MCR harness | Function |
|---|---|---|---|
| A | 11 | J2-1 | P1 Up |
| B | 12 | J2-2 | P1 Down |
| C | 13 | J2-3 | P1 Left |
| D | 14 | J2-4 | P1 Right |
| E | 3 | J2-5 | P1 Button 1 |
| F | 4 | J2-6 | P1 Button 2 |
| G | 5 | J3-1 | Coin 1 |
| H | 6 | J3-2 | Coin 2 |

**U2 — system + P2 switches**

| '165 input | pin | MCR harness | Function |
|---|---|---|---|
| A | 11 | J3-3 | Start 1 |
| B | 12 | J3-4 | Start 2 |
| C | 13 | J3-5 | Tilt |
| D | 14 | J5-17 | P2 Left |
| E | 3 | J5-18 | P2 Right |
| F | 4 | J5-19 | P2 Button 1 (Tron cocktail fire — the FPGA also ORs this with SW1-8, spec §7a; no special wiring) |
| G | 5 | spare pad | tie the '165 input high via its pull-up |
| H | 6 | spare pad | " |

**U3 — Opt X: the 8-bit dial/spinner/trackball-X bus**

| '165 input | pin | MCR harness | Function |
|---|---|---|---|
| A | 11 | J4-1 | Opt X D0 |
| B | 12 | J4-2 | Opt X D1 |
| C | 13 | J4-3 | Opt X D2 |
| D | 14 | J4-4 | Opt X D3 |
| E | 3 | J4-5 | Opt X D4 |
| F | 4 | J4-6 | Opt X D5 |
| G | 5 | J4-7 | Opt X D6 |
| H | 6 | J4-9 | Opt X D7 (J4-8 is the connector key, J4-10 is GND) |

Used by: Tron aim dial, Kick spinner, Kroozr dial, Wacko trackball X,
DoT rotary, Spy Hunter steering (roadmap).

**U4 — Opt Y / P2 stick**

| '165 input | pin | MCR harness | Function |
|---|---|---|---|
| A | 11 | J5-1 | Opt Y D0 |
| B | 12 | J5-2 | Opt Y D1 |
| C | 13 | J5-3 | Opt Y D2 |
| D | 14 | J5-4 | Opt Y D3 |
| E | 3 | J5-5 | Opt Y D4 |
| F | 4 | J5-6 | Opt Y D5 |
| G | 5 | J5-15 | Opt Y D6 / P2 Up |
| H | 6 | J5-16 | Opt Y D7 / P2 Down |

Used by: Wacko trackball Y; P2 stick for Tapper/Timber (roadmap) and
cocktail play.

**U5 — J6 / SSIO IP4 aux port** (J6 pin IDs provisional — the matrix PDF
has no J6 sheet, cross-check a cabinet manual before crimping, `TODO.md`)

| '165 input | pin | MCR harness | Function |
|---|---|---|---|
| A…H | 11,12,13,14,3,4,5,6 | J6-1…J6-8 | IP4 D0…D7: Kroozr stick Y (**needed even upright**), Two Tigers P2 dial, Wacko cocktail aim, DoT aux (roadmap) |

**U6 / U7 — the DIP banks** (on-shield switches: no conditioning pads
needed, and their pull-ups go to 3V3, not 5 V — mixed levels are fine on
5.5 V-tolerant inputs)

| Device | '165 input A…H | Connects to | Function |
|---|---|---|---|
| U6 | pins 11,12,13,14,3,4,5,6 | SW1 positions 1…8, switch→GND, 4.7 kΩ pull-up to 3V3 | game option DIPs = the core's IP3 verbatim (spec §7a); closed = 0 |
| U7 | pins 11,12,13,14,3,4,5,6 | SW2 positions 1…8, same wiring | system DIPs: menu enable, video mode, … (spec §7a) |

## 4. Output chain — meters and lamps (2× 74HC595 = 16 bits)

**Populate two 74HC595s (U8, U9) from the start.** The original single '595
was sized for MCR-2 (2 coin meters + 2 start lamps); vendoring the MCR-3
family showed 8 bits is short: the **MCR3Mono board drives two SSIO output
ports, `output_5` and `output_6` (16 bits)**, and Spy Hunter adds a lamp
panel (`show_lamps`). Two '595s cover it on the same 4 pins (they daisy-
chain, `U8.QH' → U9.SER`); add a third later at zero pin cost. Outputs feed
ULN2803s (cabinet 12 V loads, flyback diodes in the ULN):

| Device.bit | Typical load | Notes |
|---|---|---|
| U8.QA/QB | Coin meter 1 / 2 | all games |
| U8.QC/QD | Start 1 / 2 lamp | |
| U8.QE–QH | player-3 start lamp, game lamps | Rampage is **3-player** |
| U9.QA–QH | `output_6` / Spy Hunter lamp panel | mono + scroll games |

The FPGA maps SSIO `output_4/5/6` (per game) onto these bits; wire the
cabinet's real loads to whichever bits a given game drives.

### Journey cassette / MP3 module &mdash; RESERVE ONE OUTPUT (2026-07-30)

Journey's music came from an **endless-loop cassette** gated by SSIO output
port 4 bit 0 (`set_custom_output(4, 0x01)`; MAME starts the sample looping once
and thereafter only pauses/resumes it, so position is preserved &mdash; see
`docs/mcr_game_input_matrix.md`). The gateware already produces this as
`journey_tape_run` in `mcr123s_console60k_top.sv`; **it is not yet assigned a
physical pin.**

Two ways to spend it, both already provided for:

| Option | Cost | Notes |
|---|---|---|
| **A bit on the output '595 chain** | zero extra header pins | The natural home &mdash; a deck motor relay is exactly the 12 V ULN2803 load this chain exists for. Use a spare U9 bit. |
| **A dedicated J10 pin** | one pin | Needed only if an MP3 module wants **UART** rather than a level. See below. |

**If we drive an MP3 module** (DY-SV5W or similar) the module needs a *serial*
command stream, not a level, because it must be told "loop this one track" and
then play/pause. That is **one dedicated output pin** (UART TX, 9600 8N1) plus
ground; we never read back, so no RX. The DY-SV5W's logic is **3.3 V even
though it runs off 5 V** (its BUSY pin is specified as 3.3 V), so it connects
directly with no level shifter. Frames are fixed byte strings:

```
boot:  AA 13 01 14 D2    volume 20/30
       AA 18 01 01 C4    loop mode 01 = "play the current song all the time"
       AA 07 02 00 01 B4 select 00001.mp3
run:   AA 02 00 AC       Play    (tape bit rises)
stop:  AA 03 00 AD       Pause   (tape bit falls)
```

**Not yet decided which module**, so no pin is committed. Whichever it is,
budget **one output pin** (or one '595 bit if a bare level turns out to be
enough), and keep it away from the config-critical balls.

`OUT_EN_N` (pin 34) **must have a pull-up on the shield**: it holds every
output off from power-on until the gateware takes control — no coin-meter
clicks or lamp flashes during the ~1 s of FPGA configuration.

## 5. Video, audio, straps (live today)

- **DAC:** 3-bit R2R per gun — MSB 510 Ω, 1 kΩ, 2 kΩ (bench-proven values,
  `bench_wiring.md`) summed into the monitor's 75 Ω ≈ 1 Vp-p. Bit 0 of
  each gun is just an MSB copy for 4-bit Pmods — leave it unconnected or
  pad for a future 4th resistor.
- **Sync:** `VID_HS`/`VID_VS` are 3.3 V, negative-going. Buffer to 5 V TTL
  for the cabinet (BC847 stage or 74HCT244 at 5 V, spec §3). Real MCR
  monitors want **separate H and V** (Video conn pins 8/9) — leave the
  pin-39/40 straps open; they exist for OSSC/RetroTink-style RGBS gear.
- **15 kHz:** close the pin-37 solder jumper for a cabinet build. Open =
  31 kHz for bench VGA monitors. HDMI works in both modes regardless.
- **Audio:** PWM out; RC low-pass (~15 kHz corner) → LM386 on the 12 V
  rail → speaker (spec §3). Mono cabinets use `AUD_PWM_L`.
- **Status LEDs (pins 21–24):** route to 4 small LEDs via 1 kΩ. They are
  the case-closed diagnostics: calib steady + pix/27M blinking + ddr_rst
  off = video pipeline healthy.

## 6. Coverage across the WHOLE MCR family (reviewed after vendoring)

The header, pin budget, AHC-direct input stage and (now-16-bit) output
chain all hold up for every MCR family. But vendoring MCR-3/Scroll/Mono
surfaced three things the original MCR-2-era allocation missed — none break
the header, all are allocation/labeling fixes:

**(a) Allocate the input chain by SSIO input PORT, not by MCR-2 function.**
The cores read five bytes `input_0..input_4` (IP0–IP4) and each game maps
its own controls into them. Crucially, **different boards route the same IP
port to different cabinet connectors** — the SSIO board puts IP0/IP1 on J4,
IP2 on J5, IP4 on J6; the MCR3Mono board puts IP0/IP1 on J2, IP2 on J3,
IP4 on J4 (verified in MAME `mcr3.cpp`). So a universal shield should give
each IP port its **own '165 with a clean 8 bits**, wired from whatever
control that cabinet uses, and let the FPGA do the per-game mapping:

| '165 | Byte | Wire from the cabinet's… |
|---|---|---|
| U1 | IP0 | coins, starts, tilt, service, P1 button(s) |
| U2 | IP1 | P1 stick **or** the 8-bit dial/spinner (dial games) |
| U3 | IP2 | P2 stick / trackball-Y / gas pedal (per game) |
| U4 | IP4 | aux: **P3 stick (Rampage)**, P2 dial, Kroozr stick-Y, DoT aux |
| U6/U7 | IP3 | SW1 (game DIPs) / SW2 (system DIPs) |

This is simpler than the old 7-device hybrid (which split P1 across U1 and
coins, and left P2 one bit short) and it covers everything below. The §3b
tables above are the **MCR-2 wiring example**; re-label the screw terminals
by IP port for a universal build.

**(b) 3-player and multi-analog games are real.** Concretely:

| Game(s) | The demand | Covered by |
|---|---|---|
| Domino/Tron/Shollow/Wacko/Kroozr/2Tigers (MCR-2) | 1–2 players, dials, cocktail | U1–U4 (shipping) |
| Kick / Solar Fox (MCR-1) | spinner / stick | U2 |
| Tapper, Timber (MCR-3) | 2 players, 2-way sticks + buttons | U1–U3 |
| **Rampage (Mono)** | **3 players** (3× 8-way + 2 buttons) | IP1/IP2/IP4 = U2/U3/U4 |
| **Spy Hunter (Scroll)** | steering **+** gas (2 analog axes, muxed by an SSIO output bit) + 5 buttons + gear | both on the IP2 byte, alternated by `output_4`; buttons on IP0/IP1; lamps on the '595 chain |
| **Max RPM (Mono)** | **2 wheels + 2 pedals** (4 axes, muxed) | the IP1 byte, alternated by output bits |

The analog axes arrive as **8-bit digital** on their IP byte (the original
MCR control PCB does the pot→ADC conversion; the game time-multiplexes
several axes onto one byte using an SSIO *output* select bit). So the
shield's digital '165 reads them fine **from a cabinet that has that
control PCB**. A bare-potentiometer hookup would need an ADC the shield
does not provide — worth a silkscreen note, but out of scope for a
harness-in build.

**(c) J9 SDRAM is now mandatory, not optional.** Three of the five families
(all of MCR-3/Scroll/Mono) require the Tang SDRAM module in J9 for the
128–256 KB real-time sprite ROM. "Leave J9 clear" (§ ground rules) is a
hard requirement for a board meant to run the whole family, not just
future-proofing.

Bottom line: **the guide still makes sense — the 40-pin header, the
electrical design, and the chain architecture all scale to the full
family.** The updates are: allocate the input chain by IP port (above),
populate 2× '595 (§4), and treat J9 as reserved-mandatory.

## 7. Bring-up order for the board

1. Populate video DAC + sync buffer + audio + straps + LEDs only. Flash
   any current `bitstreams/console60k_*.fs` → full game on the cabinet
   monitor (15 kHz strap closed), sound, LEDs. No new gateware needed.
2. Populate the input-conditioning pads + '165/'595 chains once the
   expander RTL lands (tracked in TODO.md; pins are frozen here, so no
   board spin).
3. USB pad and HDMI work throughout as the reference path.

## 8. Change control

- This table is the contract: `mcr2_console60k.cst`, the expander RTL, and
  `tools/generate_pcb.py` must follow it. If a pin must move, change THIS
  file first, in the same commit.
- Current CST already matches every **live** pin (they are today's bench
  assignments, deliberately). The **reserved** pins appear in the CST only
  when the expander RTL lands.

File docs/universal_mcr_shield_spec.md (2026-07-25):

# Universal MCR Shield — Consolidated Specification

Single source of truth for the cabinet-interface shield that lets a Tang
Console 60K/138K drop into any original Bally Midway MCR-1/2/3 cabinet as a
CPU-board replacement. Consolidates and supersedes the electrical/pinout
content spread across `handoff_v2_design.md` (§2–3, written for the Primer
25K dock) and `pcb_design.md` (floorplan/KiCad, still authoritative for
layout). Game-function reference: `docs/mcr_game_input_matrix.md`.

## 0. Product decisions (2026-07, settled)

- **Interface style: the cabinet harness plugs into the shield** (settled
  2026-07-22). The shield presents the original MCR cabinet connectors as
  headers; the operator plugs the existing harness in and picks the game in
  the OSD — no rewiring, because the FPGA maps every pin to its in-game
  function per the selected game (the '165 chain delivers raw bits; the core
  interprets them). This is explicitly **NOT** a mechanical board-swap
  (the shield does not plug into the cabinet's original PCB-edge socket in
  place of the game board — that would mean replicating each board's edge
  connector and is out of scope). Consequences for the PCB:
  - Route the actual MCR **mating connectors** in the right positions so an
    original harness seats pin-for-pin.
  - **Rev A targets the SSIO-family connectors** (MCR-1/2 + the SSIO MCR-3
    games: Tapper, Timber, Journey, Discs of Tron, Spy Hunter, Crater) —
    the large majority, and the set documented in the master pinout matrix.
  - **MCR3Mono (Rampage, Sarge, Max RPM, Power Drive, Star Guards) is a
    later variant**: those games are absent from the master pinout matrix
    and the mono board routes IP ports to different connectors (IP0/IP1→J2,
    IP2→J3, IP4→J4, 3 players) — verify against the mono board schematic
    before adding its connectors.
  - Special controls (dials/spinners/wheels/pedals) arrive as **8-bit
    digital** on the Opt X/Opt Y connectors; the shield reads them straight
    from a cabinet that still has its MCR control PCB. A bare-pot hookup
    would need an ADC the shield does not provide (silkscreen note).
- **Dual-use, not cabinet-only.** Keep the HDMI path alongside the analog
  cabinet output: it is the primary debug surface, and retrofit-LCD cabinets
  are a real installed base. Consequence: the DDR3 framebuffer stays, so
  **DDR3 is committed to video** and cannot also serve as the ROM store.
- **ROM storage split (as nand2mario/gbatang does on this exact board):**
  DDR3 → framebuffer; **SDRAM module in the J9 slot → game ROMs** for sets
  too big for BRAM; SD card → ROM files and firmware.
- **Configuration by DIP switches, read through a 74HC165 chain** (3 pins
  for 16 switches). Parallel DIPs do not fit: the shield needs 44 of the 54
  I/O available on J10+PMODs, and spending J9 on switches would forfeit the
  SDRAM slot. See §7.
- **Cabinet default is menu-off**: power on straight into the DIP-selected
  game, no OSD reachable by a customer.

## 1. Design principles

1. **Expose the original MCR connectors** so the cabinet harness plugs
   straight in — no JAMMA adaptation. The real board connectors, their
   pin counts and **pitch** (J1 power = .156" MTA; J2 video, J3 audio,
   J4/J5/J6 inputs = .100" MTA) and per-pin functions are in
   **`docs/shield_wiring.md`** / **`docs/MCR Series Pinouts.html`**. (The
   matrix doc uses a normalized *cabinet-function* J-numbering; the
   physical connectors use the real board numbering — see shield_wiring §1.)
2. **No game-specific wiring.** Connector wiring is identical across all
   MCR games; every game-specific *interpretation* lives in the FPGA top.
   One shield serves every core. (DIP switches select which game/core runs
   — they do not rewire anything.)
3. **Serial cabinet I/O — no opto isolation (revised 2026-07).** Cabinet
   inputs run into 74AHC165 shift registers (3 FPGA pins), outputs via a
   74HC595 chain (4 pins); see `shield_wiring.md`. The 74AHC165's 5.5 V-
   tolerant inputs take the 5 V harness directly, so there is no separate
   level shifter. The earlier plan (parallel, opto-isolated) was dropped:
   the shield's buck is non-isolated, so the optos never bought isolation,
   and parallel I/O would forfeit the J9 SDRAM slot (§2).

## 2. FPGA signal budget

**Revised 2026-07-21: the shield connects to J10 ONLY** — one 40-pin
header for video, audio and all controls; both PMOD sockets stay free.
The definitive pin table is **`shield_j10_pinout.md`**; the budget that
makes it fit:

| Group | J10 pins | Direction | Interface |
|---|---:|---|---|
| Video RGB (4:4:4 driven, 3:3:3 significant) | 12 | out | R2R DAC → 1 Vp-p |
| Video sync HS/VS | 2 | out | NPN/74HCT buffer → 5V TTL |
| Audio PWM L/R | 2 | out | RC filter → LM386 |
| Status LEDs | 4 | out | direct |
| Mode/sync straps | 3 | in | solder jumpers |
| **ALL cabinet inputs + both DIP banks** (J2, J3, J4, J5, J6/IP4, SW1, SW2 = 56 bits) | **3** | in | 7× 74AHC165 chain (5 V-tolerant inputs) |

> **⚠ J2 NAMING CONFLICT (found in EE review 2026-07-24, see `EENotes.md` #2):**
> this spec mixes two connector conventions. On the SSIO-family boards the
> master pinout matrix has **J2 = video out** (§ above and
> `docs/mcr_game_input_matrix.md`); the input tables below inherited the
> MCR3-Mono convention where IP0/IP1 land on J2. Until the refdes/renumber
> pass is done together with the EE (one pass, then frozen — the wiring
> docs cite these names), read the input tables' "J2" as "the P1 input
> connector per that cabinet family", and treat `docs/MCR_Master_Pinouts.pdf`
> as the authority for any physical harness question.
| **All outputs** (coin meters, lamps — mono drives output_5+output_6 = 16 bits) | 4 | out | 2× 74HC595 chain + ULN2803 |
| Service button | 1 | in | direct (opens the OSD) |
| Spares | 7 | — | |
| Power (+5 V out, GND) | 2 | | |
| **Total** | **40** | | |

Serializing the inputs is what makes "every game on one header" possible:
30+ harness lines plus the 8-bit IP4/J6 port plus 16 DIPs would need ~60
parallel pins, forfeiting either video or the J9 SDRAM slot (i.e. the big
MCR-3 titles). The '165 parallel-load strobe snapshots all 56 bits
atomically, so the 8-bit spinner/trackball buses cannot tear, and a full
scan (~30 µs) is ~500× faster than the games' own once-per-frame input
polling. HDMI, USB, SD and DDR3 cost zero shield pins (SOM/dock balls).

## 3. Electrical interface (consolidated)

- **Power:** cabinet +12 V → onboard buck (LM2596/MP1584EN, ≥1.5 A) → 5 V to
  the Console's 5 V input. Do not use the cabinet's +5 V rail (noise/brownout)
  or −5 V rail (not needed — no 4116 DRAMs).
- **Inputs (revised 2026-07-21 — no optos):** harness lines go directly
  into the shield's **74AHC165** shift registers, powered at 3.3 V — AHC
  inputs are rated to 5.5 V independent of VCC, so the '165 itself does
  the 5 V → 3.3 V translation. Per line: 4.7 kΩ pull-up to +5 V, 1 kΩ
  series, 10 nF to GND, BAT54S clamp to +5 V/GND (a 12 V miswire drops
  across the series R). Full pad + rationale in `shield_j10_pinout.md`
  §2/§3b. The earlier TLP281-4 opto plan claimed galvanic isolation the
  non-isolated buck never actually allowed (grounds are common through
  the power path); the pads keep the fault protection at a fraction of
  the parts. Plain 74HC165 is NOT a substitute (inputs limited to
  VCC + 0.5 V).
- **Video RGB:** R2R ladder per gun (510 Ω / 1 kΩ / 2 kΩ for bits 2/1/0)
  into the monitor's 75 Ω load ≈ 1 Vp-p. No active buffer needed.
- **Video sync:** 3.3 V FPGA → BC847 NPN stage (or 74HCT244 powered at 5 V)
  → 5 V TTL negative-going HS/VS on Video-8/9. G07/K4600-style monitors at
  15 kHz; the core must be in `tv15Khz_mode=1` for a real MCR cabinet
  monitor.
- **Audio:** PWM → 2-stage RC low-pass (~15 kHz) → LM386 (12 V rail) → mono
  speaker terminals.

## 4. Dock connector plan (from schematic `Tang_Mega_60K_Console_32001C`, rev 1.3)

The dock's two 2×20 headers are **J9 ("SDRAM0 CONN", near PCIe)** and
**J10 ("SDRAM1 CONN", near the PMODs)** — each carries a full 38-signal
SDRAM-pinout GPIO bus. Architecture decision:

- **J9 — reserved for the Tang SDRAM module** (future frame buffer / ROM
  store; nand2mario cores use these exact pins, `cs_n = F21` on this rev).
- **J10 + PMOD0 + PMOD1 — the shield** (38 + 16 = 54 IOs for ~44 nets).
- USB-A ports remain the controller path; HDMI remains for modern displays.

### 4a. J10 header ↔ FPGA ball map (verified: sheets 4, 6, 8 of rev C PDF)

| J10 pin | Net | Ball | J10 pin | Net | Ball |
|---|---|---|---|---|---|
| 1 | D0 | R19 | 2 | D1 | P19 |
| 3 | D2 | U21 | 4 | D3 | T21 |
| 5 | D4 | R17 | 6 | D5 | P16 |
| 7 | D6 | T18 | 8 | D7 | R18 |
| 9 | D15 | W17 | 10 | D14 | V17 |
| 11 | **+5V** | — | 12 | **GND** | — |
| 13 | D13 | W22 | 14 | D12 | W21 |
| 15 | D11 | P17 | 16 | D10 | N17 |
| 17 | D9 | N14 | 18 | D8 | N13 |
| 19 | A12 | V20 | 20 | CLK | U20 |
| 21 | A9 | Y22 | 22 | A11 | Y21 |
| 23 | A7 | AB22 | 24 | A8 | AB21 |
| 25 | A5 | AA21 | 26 | A6 | AA20 |
| 27 | WE | AB20 | 28 | A4 | AA19 |
| 29 | EXIO0 (=DM0 via 0Ω) | AA18 | 30 | EXIO1 (=DM1 via 0Ω) | AB18 |
| 31 | CAS | Y19 | 32 | RAS | Y18 |
| 33 | CS | T20 | 34 | BA0 | N15 |
| 35 | BA1 | U18 | 36 | A10 | U17 |
| 37 | A0 | R16 | 38 | A1 | P15 |
| 39 | A2 | R14 | 40 | A3 | P14 |

Caveats: **V17 = CSI_B, AB20 = CSO_B/DOUT, AA19 = RDWR_B** are config
dual-purpose pins — synthesis needs the matching `-use_sspi_as_gpio`-family
options (the 25K build.tcl shows the pattern). U20/V20 are GCLK-capable
(bonus, not required). All J10 banks (6/7/8) are 3.3 V.

### 4b. Cabinet pin → J10/PMOD assignment — SUPERSEDED

> **This section is superseded by `shield_j10_pinout.md`** (2026-07-21),
> which puts everything on J10 via input/output shift-register chains and
> keeps the PMODs free. It is retained only as the record of the earlier
> parallel-input plan; do not route from it.

Inputs (all opto-isolated, active low, internal pull-ups):

| Cabinet pin | Function | J10 pin | Ball |
|---|---|---|---|
| J4-1..7,9 | Opt X D0–D7 (dial bus) | 1,2,3,4,5,6,7,8 | R19,P19,U21,T21,R17,P16,T18,R18 |
| J5-1..6 | Opt Y D0–D5 | 18,17,16,15,14,13 | N13,N14,N17,P17,W21,W22 |
| J5-15 | Opt Y D6 / P2 Up | 10 | V17 |
| J5-16 | Opt Y D7 / P2 Down | 9 | W17 |
| J5-17 | P2 Left | 36 | U17 |
| J5-18 | P2 Right | 22 | Y21 |
| J5-19 | P2 Button 1 | 19 | V20 |
| J2-1..6 | P1 Up,Down,Left,Right,B1,B2 | 37,38,39,40,28,25 | R16,P15,R14,P14,AA19,AA21 |
| J3-1..5 | Coin1,Coin2,Start1,Start2,Tilt | 26,23,24,21,34 | AA20,AB22,AB21,Y22,N15 |
| reserved (outputs: coin meters / lamps / J6) | — | 20,27,31,32,33,35,29,30 | U20,AB20,Y19,Y18,T20,U18,AA18,AB18 |

Video/audio on the PMODs (shield covers both sockets):

| Signal | PMOD | Ball |
|---|---|---|
| VID_R[2:0] (R2R) | PMOD0 | V18, V19, G21 |
| VID_G[2:0] (R2R) | PMOD0 | G22, F18, E18 |
| VID_B[2:1] (R2R) | PMOD0 | C22, B22 |
| VID_B[0] (R2R) | PMOD1 | W19 |
| VID_HS / VS / CSYNC (5V TTL buf) | PMOD1 | W20, F19, F20 |
| AUD_PWM_L / R | PMOD1 | E22, D22 |
| spare | PMOD1 | E21, D21 |

**Note:** the current `mcr2_console60k.cst` desk-test assignments (buttons
on PMOD1, provisional cab video) intentionally differ; re-pin to this table
when shield rev A is finalized — cabinet inputs then arrive via the J10
74AHC165 chain and the USB pad, so PMOD desk buttons retire.

+12 V from the cabinet enters the shield at a screw terminal → buck → 5 V.

## 5. RTL requirements per game core

- `tv15Khz_mode = 1` for cabinet use (native 15 kHz RGBS); HDMI path stays
  active concurrently for bring-up.
- Input mapping from nets above into `input_0..input_4` per game, bit
  positions verified against MAME (`mcr.cpp`) — see examples in
  `mcr_game_input_matrix.md`.
- Spinner/trackball (J4/J5 8-bit buses) feed the core's `spinner.sv` /
  analog paths — only needed for dial games (Tron, Kick, Kozmik, Wacko,
  DoT, Spy Hunter).

## 6. Open items

(Also tracked in the repo-root `TODO.md`, alongside the gateware gaps.)

1. **5 V delivery route** — shield buck → console. Preferred: into the
   dock's USB-C power input (goes through the dock's OR-ing/OVP, sheet 3).
   J10 pin 11 exposes a +5 V rail, but whether back-feeding it powers the
   SOM cleanly (it sits behind the OR-ing/OVP/bead chain) is unverified —
   do not use it as an input until traced.
2. **Board revision** — ✅ checked: J10's header pinout is net-for-net
   identical in rev A (32001A, 1.22) and rev C (32001C, 1.3); only the
   footprint differs (TH vs SMD 2×20). Ball map in §4a is from rev C's SOM
   sheets; if a board is identified as rev A, spot-check sheets 4/6 (the
   only known dock-level reroute is SDRAM0_CS: F19 on the old NEO dock →
   F21 now — J9 side, doesn't affect the shield).
3. **J6 / SSIO IP4** and **lamp/coin-meter outputs** — ✅ resolved by the
   chain architecture in `shield_j10_pinout.md`: IP4/J6 is '165 device U5
   (8 bits, zero extra pins) and outputs are a 74HC595+ULN2803 chain,
   extensible per game with no pin cost. J6's *cabinet-side* connector
   wiring still wants a manual cross-check before the harness is crimped.
4. **Board outline/mounting** — `pcb_design.md` + `tools/generate_pcb.py`
   own the physical layout; sync them to §4b (they currently assume generic
   2×20 headers, and J9 must be left clear for the SDRAM module).
5. **138K variant** — same dock; header nets are dock-level, but the
   net→ball map on sheets 4–6 is SOM-specific. Re-extract from the 138K
   SOM schematic before targeting it.

---

## 7. Configuration & game selection (DIP switches)

Two 8-position DIP banks, matching the SW1/SW2 placement already in
`pcb_design.md`. **Revised 2026-07-20:** game *selection* moves to the OSD
(see 7c/7d); the physical DIPs are for what operators have always used DIPs
for — the game's own option switches.

### 7a. Switch map

| Bank | Positions | Function |
|---|---|---|
| SW1 | 1–8 | **GAME DIPS — wired verbatim as the core's IP3 byte** (the original board's B3 bank). Meanings are per game, exactly as the 1982 operator manuals document them: coinage, music, difficulty, cabinet type, coin meters… Ship a printed reference card per game, as operators always had. |
| SW2 | 1 | Menu enable (see 7c) |
| SW2 | 2 | Video: 15 kHz cabinet CRT / 31 kHz |
| SW2 | 3 | 15 kHz sync format: separate H/V (default, = MCR cabinet) / composite |
| SW2 | 4 | Free play (where the game's own DIPs lack it) |
| SW2 | 5 | Service / test |
| SW2 | 6–8 | Reserved |

SW1 = IP3 removes the per-game hardcoded `input_3` constants from the top —
the operator sets the real switches. Two caveats survive from the analysis
below: the cocktail bit lives at a different IP3 position per game (that is
now simply the operator's problem to set per the game's card, as it was in
1982), and **IP3 is not purely DIPs for every game** — Tron's bit 7 is the
cocktail player's fire button. The original hardware wired that harness
line in parallel with DIP position 8 on the same active-low input, and the
manual said "leave SW1-8 OFF". We replicate it exactly: the FPGA ORs the
switch bit with the harness line, no per-game masking — same behaviour,
same operator convention, including the same failure mode if the switch is
left on.

**Cocktail pin impact:** unchanged — cocktail P2 controls for Tron/Domino
arrive on SSIO IP2 = J5 1-8, already allocated in §4b. The outstanding item
is **IP4 / J6**, which §4b does not pin: it carries Wacko's cocktail
joystick, Two Tigers' P2 dial, and Kroozr's analogue-stick Y axis (the last
needed even upright). Allocate from the 8 reserved pins once J6's cabinet
wiring is established.

### 7b. Reading them (74AHC165)

The two DIP banks are simply devices **U6 (SW1) and U7 (SW2) on the
unified input chain** defined in `shield_j10_pinout.md` §3 (IN_CLK /
IN_LOAD_N / IN_DATA on J10 pins 25/26/27) — the same chain that carries
every harness input, so the DIPs cost zero additional pins. Switch to GND
with pull-ups to +3V3; a closed switch reads 0. Because the chain is
scanned continuously, DIP changes could be live — but the cores latch IP3
meaningfully only at boot, so keep the **silkscreen "power-cycle after
changing DIPs"** next to the banks.

### 7c. OSD (game selection & system settings)

Game selection is on-screen, opened with the **cabinet's existing service
button** (present in every MCR harness) or the bench board key. Selection
and system prefs persist to a reserved SD sector; the chosen game reloads
via the existing rom_loader path, no reflash.

**The OSD must be visible on BOTH video outputs.** It composites into the
core's native RGB stream *before* the analog/HDMI split (clk_sys domain, on
the native raster), so the cabinet CRT — the only display in a cabinet —
shows it identically to HDMI. Consequences the implementation must honour:
- **per-game rotation**: vertical games (Tron, Satan's Hollow, Kick…) run
  on physically rotated monitors, so OSD text must render ROT90 for them;
- works on the **15 kHz raster** (240-line fields), not just 31 kHz;
- native resolution and the game palette's 3:3:3 colour — which is
  authentic-looking, not a limitation.

Menu semantics:
- **Menu off (SW2-1, cabinet default):** customers cannot reach the OSD;
  the service button still opens it (operator path, as MCR test switches
  always worked).
- **Menu on:** OSD reachable from the pad (bench/home use).

### 7d. Multiboot layout

Per-core bitstream payload is **2.5 MB** (`impl/pnr/*.bin`; the 20 MB `.fs`
is ASCII, not the flash footprint), so all three family cores fit in <8 MB.
A small selector image boots first, reads the prefs sector from SD (last
selected family/game), and reconfigures to that image's flash address.
`-multi_boot 1` is already set in `build.tcl`. No switches involved.

### 7e. Fallback behaviour (required for shipping)

If the selected family/game has no ROMs available (missing SD card, missing
file, bad checksum): **do not sit on a black screen.** Flash a status code
on an LED and fall back to the menu (or to a built-in test pattern when the
menu is disabled), so a field failure is diagnosable without a laptop.

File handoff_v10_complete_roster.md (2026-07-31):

# Handoff v10 — the complete roster, and what is still missing (2026-07-30)

Start here. Supersedes `handoff_v9_merged_core.md`, which predates MCR-1, the
15-game merge and all hardware verification.

This document exists because "what is left?" had no single answer: `TODO.md` is
136 KB with cocktail mode at line 1819, the per-board READMEs are board-scoped,
and some gaps — Discs of Tron's **speech** most obviously — were not written
down anywhere at all.

---

## Where the platform is

**One bitstream holds every MCR game this board can run: 16 titles, four
families.** `mcr123s_console60k` is flashed as the power-on default.

| Family | OSD idx | Games |
|---|---|---|
| MCR-3 (2) | 0–3 | Tapper, Timber, Discs of Tron, Journey |
| MCR-2 (1) | 4–9 | Satan's Hollow, Tron, Wacko, Kozmik Kroozr, Two Tigers, Domino Man |
| MCR3Scroll (3) | 10–12 | Crater Raider, Spy Hunter, Turbo Tag |
| MCR-1 (0) | 13–15 | Kick, Solar Fox, Kickman |

Budget: **116/118 BSRAM, 75% logic, 0 timing violations**, clk_sys Fmax 43.0 vs
40.0 MHz required. No ROM data in the bitstream — everything streams from the
SD card (licensing).

**Verified on hardware: 7 of 15** — Wacko, Kick, Kickman, Solar Fox, Spy Hunter,
Turbo Tag, Crater Raider. That is all of MCR-1 and all of MCR3Scroll.

Every *mechanism* the merge depends on is proven:

| Mechanism | Blocks it saved | Proven by |
|---|---|---|
| Sprite ROM shared MCR-1 ↔ MCR-2 | 16 | Kick + Wacko |
| CSD 68000 ROM in SDRAM (`cpu2`) | 16 | Spy Hunter sound |
| Sound ROM in SDRAM (`cpu3`) | 8 | Kick, Kickman (SSIO-only) |
| Scratch RAM shared ×4 | 4 | all seven |
| CPU ROM trimmed to 0xE000 | 4 | all seven |
| bg pair shared, MCR-1's 4 KB planes | 4 | Kick |

All three audio configurations work: SSIO-alone, SSIO+CSD, and CSD-alone.

---

## 1. Still to VERIFY (not missing — just unplayed)

**Regression pass on the eight remaining MCR-2/MCR-3 games**: Tapper, Timber,
Discs of Tron, Satan's Hollow, Tron, Kozmik Kroozr, Two Tigers, Domino Man.
They were verified in `mcr23_console60k`, before the shared scratch RAM, the
trimmed CPU ROM and the SDRAM sound ROM existed.

Do it by **switching between families repeatedly**, not by playing each in
isolation: the shared scratch RAM is the only mechanism that can corrupt a
*running* game, and family switching is how you would provoke it.
`SCRATCH_EXTERNAL(0)` on all four cores is the isolation switch (costs 4 blocks
the build does not have, so it is a diagnostic, not a fallback).

---

## 2. MISSING FEATURES — the actual answer to "what is left?"

### 2a. Sound and speech

| Gap | Status |
|---|---|
| **Discs of Tron SPEECH** | **Absent.** DoT's Squawk & Talk board (6809 + TMS5200) was never implemented in the upstream MiSTer core, so there is nothing to port. DoT plays and sounds correct otherwise. Implementing it means writing the board from scratch. |
| **Journey tape music** | **Journey IS in the roster (added 2026-07-30) but plays WITHOUT music.** Its endless-loop cassette is gated by SSIO output 4 bit 0; the gateware exposes `journey_tape_run` but **no pin is assigned** and no player is built. Two ways to finish it, and they are not exclusive: an external MP3 module / real deck driven from that signal (needs one pin — `docs/shield_j10_pinout.md`), or the internal 22.05 kHz WAV in SDRAM (needs `DL_AW` 19→24, the loader watchdog fixed, a wave pack entry, and ~6.5 s of load). |
| Everything else | Working. SSIO, Cheap Squeak Deluxe/FX68K, and the SSIO+CSD mix are all verified. |

### 2b. Games not in the roster

| Game | What it needs | Same board? |
|---|---|---|
| **Demolition Derby** | Turbo Cheap Squeak (6809) vendored; then it drops into the existing MCR-2 core. But it is **4-player**, so it may hit the same connector limit as Rampage. | Probably not |
| **MCR3Mono** (Rampage, Sarge, Max RPM, Power Drive, Star Guards) | A **different board rev** — its IP ports route to different cabinet connectors, plus 3-player wiring and an ADC. Core is vendored and parked in `future/`. | **No** |

### 2c. Cabinet features (all gated on the shield PCB, which is not built)

| Gap | Detail |
|---|---|
| **Cocktail mode** | Unaddressed across every game (`TODO.md` "Cocktail mode"). Four separate problems: no operator control over the upright/cocktail DIP; player-2 inputs tied off; Wacko needs a core port addition for the trackball mux; and screen flip is unverified. |
| **Spy Hunter lamp panel** | `show_lamps` tied to 0. Needs the shield's second 74HC595 — zero extra header pins. |
| **Real wheel / pedal** | Spy Hunter and Turbo Tag use `steering_control.vhd` driven from the d-pad as a stand-in. A real analogue wheel needs the shield's ADC. |
| **Service menu / coin door** | Groundwork only: holding the coin key ~3 s to open a menu is designed, not built. The real cabinet group is Coin 1 + Service/Test, which arrives via the 74HC165 chain. |
| **NVRAM / high scores** | `cmos_ram.vhd` exists and the cores have `dl_nvram` ports, but the merged top ties them **off** — nothing persists but the selected game. |

### 2d. Video

**Seven of the fifteen games are ROT90 cabinets** — Satan's Hollow, Tron, Spy
Hunter, Turbo Tag and all three MCR-1 titles — so on a normal landscape monitor
they render sideways. That is *correct* for a real cabinet and wrong for
everything else, and it is the single biggest product gap.

The fix is scaler rotation: the frame is already in DDR3, so it is a read-address
transform rather than new storage (cost: address arithmetic plus a deeper
prefetch, because transposed reads destroy burst locality — read 8×8 tiles
rather than lines). No scaler here has it yet. See `docs/scaler_options.md`.

Also wanted, in rough value order: interpolation (nearest → sharp-bilinear),
scanlines, integer/pixel-perfect scaling, and aspect/overscan control.

**The scaler decision is now a real trade**: at 116/118 BSRAM there is no room
for `ascal_v`'s +10 blocks. It is 15 games on `ddr3_framebuffer`, or 12 games
with the better scaler — unless `N_DW` is narrowed to 64, which is where the +10
comes from.

### 2e. Known open bugs

| Bug | Status |
|---|---|
| **HDMI dropouts** | Long-standing. The PLL VCO fix (2026-07-28) removed the main cause; the residual is recoverable by re-running DDR3 calibration, so a managed/periodic recalibration is the candidate gateware fix. **Not re-measured on this core.** Measuring needs discipline — record time since configuration and soak for tens of minutes, because a fresh flash hides the entire fault class. |
| **Timber boot-load** | Renders correctly from the OSD but fails when loaded at BOOT (the `use_prefs` path). Instrumented but never read. Not re-checked since the merge. |

---

## 3. Polish / debt

- **Retire the bring-up diagnostics** (owed since v9): the sprite-word audit,
  the liveness counters in beacon E0/E1, the disabled `if (1'b0)` sweeps, the
  SDRAM dump. Keep the stored-ROM audit. Frees logic (75% now) and buys back
  timing margin. Do it *after* the roster is verified — they are the instrument.
- **Control and DIP tuning**: Kick's spinner sensitivity and MCR-1's `input_3`
  are placeholders; MCR3Scroll DIPs are the MRA defaults, not cross-checked
  against MAME per game.
- **Apply the new build options to the other boards.** Every board except
  `mcr123s_console60k` still builds at DEFAULT routing effort — see the build
  options section in CLAUDE.md. They may all have margin sitting unclaimed.
- **`impl/` for the two new boards is not committed** (315 MB). The repo
  convention is to commit it; this was left out deliberately.

---

## 4. What I would do next, in order

1. The eight-game regression pass (§1) — the only thing that could still be a
   real bug rather than a missing feature.
2. HDMI soak on this core (§2e) — wait a good while after any flash first.
3. Retire the diagnostics (§3), reclaiming logic and timing margin.
4. Then pick a direction: **scaler rotation** is the highest-value feature for
   anyone not building a real cabinet; the **shield PCB** is the highest-value
   for anyone who is.

---

## 5. Lessons from this session that outlive it

- **Check the toolchain before blaming the design.** `build.tcl` had only ever
  set `place_option 2`; enabling `route_option 2`, `retiming`, `timing_driven`
  and `correct_hold_violation` took clk_sys TNS from −6.342 ns over 25
  endpoints to −0.059 ns over 1 with **no RTL change**. Two days of RTL surgery
  bought less than four `set_option` lines.
- **LUT RAM is not a free substitute for BSRAM.** Fine for 256-byte line
  buffers; doing it to the 512-byte sprite staging RAMs cost the entire clk_sys
  domain (−536 ns), because a distributed-RAM read is a combinational walk fed
  by a mux, closing on the opposite clock edge.
- **Never budget one BSRAM block per array.** PnR already packs small ones:
  folding four 512-byte RAMs into one returned 2 blocks, not 4. Every estimate
  this project made was optimistic; only PnR is authoritative.
- **Mux depth matters on half-cycle paths.** `a ? : b ? : c ? :` is three
  dependent LUT levels; an array indexed by `run_family[1:0]` is one 4:1 mux.
  Keep `FAM_*` numbered 0..3 so the family code stays usable as an index.
- **Identical structure across cores is the cheapest saving there is.** The
  sprite ROM, bg pair and scratch RAMs were byte-identical in all four cores,
  and only one core runs at a time. Sharing them cost nothing and saved 28
  blocks — more than every clever trick combined.

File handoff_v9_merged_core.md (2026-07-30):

# Handoff v9 — merged MCR-2 + MCR-3 core (2026-07-28)

Start here. Supersedes `handoff_v8_sprite_shift.md` (whose subject is RESOLVED —
see its header). `TODO.md` items 1, 2, 3 and 4a–4c carry the detail; this is the
orientation.

## Where the platform is

**`mcr23_console60k` is the product: nine games in ONE bitstream, flashed as the
power-on default.** All nine verified on hardware. Game selection is from the OSD
and persists across power cycles *and across families*.

| Family | Games (roster index) |
|---|---|
| MCR-3 (fam 2) | Tapper 0, Timber 1, Discs of Tron 2 |
| MCR-2 (fam 1) | Satan's Hollow 3, Tron 4, Wacko 5, Kozmik Kroozr 6, Two Tigers 7, Domino Man 8 |

**No 60K bitstream contains ROM data** — everything streams from the SD card
(licensing). A missing card shows an INSERT CARD screen and hot-inserting one
recovers within seconds with no power cycle.

Budget: **114/118 BSRAM**, ~20k of 60k LUT, TNS 0.000. Four blocks spare — check
the BSRAM count on *every* change.

**`mcr23s_console60k` (2026-07-30) extends this to 12 games / three families —
MCR3Scroll's Crater Raider 9, Spy Hunter 10, Turbo Tag 11 — and BUILDS at
117/118, TNS 0.000.** Untested on hardware; see item 3 below and that board's
README. `mcr23_console60k` remains the product and is untouched.

Single-family boards (`mcr1/mcr2/mcr3_console60k`) all still build and work; the
merged board is additive. The 25K stays deliberately baked (fixed-function).

## What this session did

- **MCR-3 sprite "detached handle" SOLVED** (`2fc948e`). Address came from the
  2-deep sync registers while data was taken live, so byte j landed at byte j−1:
  the whole sprite array stored as `mem[i] = blob[i+1]`. Introduced by `500c74a`.
  Never instance-dependent — handoff v8's premise was wrong.
- **All three MCR-3 titles working**: Timber needed the gfx1 plane order (it is
  PER-CORE, not per-game); Discs of Tron needed sprite BITPLANE padding (its
  64 KB set left two of four planes empty).
- **Everything-from-SD** across all three families, plus the INSERT CARD screen.
- **OSD widened** to 20 scrolling slots (8 visible), sized for the whole series
  incl. MCR3Scroll. Pinned by `sim/osd/tb_osd.sv`.
- **The merge itself**, plus a **stored-ROM audit** instrument (below).
- **HDMI dropouts**: found a gateware lever (below).

## Open issues, in the order I would take them

### 1. Timber boot-load bug — instrument is loaded, answer NOT yet read
Timber renders correctly when chosen from the OSD but fails when loaded at BOOT
(the `use_prefs` path). **This is the immediate next action** and it is one
command; the board is sitting on a frozen Timber right now:

    cd <scratchpad> && timeout 45 python3 lg.py tim.log 40
    # then compare E5/E4/E6/E7 against:
    python3 tools/ckstore.py timber      # cpu=0261 snd=CB8C bg1=773D bg2=5B14

- **any mismatch** → names the corrupted region; it is a storage bug like the
  other three this session
- **all four match** → the ROM data is provably correct and the fault is in the
  core's *use* of it, which retires a whole class of theory

Already ruled out with evidence (do not re-litigate, see TODO item 3): the SD
card, the pack layout, any 2026-07-27 RTL change, the sprite path, and the wedge
watchdog (`kick_n=0`, `hwin=0xFF` — the CPU is alive). It is NOT a crash: the
game animates.

### 2. HDMI dropouts — a gateware fix is now in reach
Measured: 25 min on one configuration → **52% dropout**; reconfiguring WITHOUT
touching thermals → **18%**. A 3× recovery in ~30 s, far too short to cool. So
much of the degradation is recoverable by re-running DDR3 calibration. The old
"board thermal" conclusion was confounded — the overnight-cool-down evidence
also power cycled, which is itself a reconfiguration. Temperature still
contributes (18% ≫ the 0–2% of a cool board). **Next: a managed or periodic DDR3
re-calibration.** A cabinet owner cannot cool the board; gateware can recalibrate.

### 3. Folding in MCR-1, and MCR3Scroll

**DONE for MCR3Scroll, 2026-07-30: `mcr23s_console60k` builds — 12 games,
three families, 117/118 BSRAM, 0 setup/hold violations.** Read
`mcr23s_console60k/README.md`; the measurement trail is `TODO.md` 4a-bis.
Nothing has run on hardware yet. Progression, all PnR:

| Configuration | BSRAM | |
|---|---|---|
| MCR-2+MCR-3 (the shipping core) | 114 | fits |
| + MCR3Scroll, first build | 127 | over by 9 |
| + sprite line buffers → LUT RAM | 125 | over by 7 |
| + sound ROM → SDRAM | **117** | **fits, 1 spare** |

What that revised, from the estimates that used to be in this section:

- **The FX68K costs ZERO BSRAM, not 4.** Two builds differing only in
  `SCROLL_CSD` both land on 127: `uRam`/`nRam` and the 68000 register file map
  to ROM16/SSRAM. The 68000 was never the problem — MCR3Scroll's own
  video/sprite RAMs are.
- **MCR-2 sprites → SDRAM was NOT needed.** The two cheap levers above were
  enough, so the pipeline surgery (MCR-2 has 1 phase of slack, MCR-3 has 8) is
  still un-attempted and still available for MCR-1.
- **Small RAMs do not cost one block each.** Pushing ten 256×8 sprite line
  buffers to LUT RAM gave back **2** blocks, not 10 — PnR already packs them.
  Budget from PnR, never from array counts.
- **Two SDRAM regions are now load-bearing and neither is hardware-verified**:
  the CSD 68000 ROM (32 KB, `cpu2`) and the sound ROM (16 KB, `cpu3`). Both sit
  in the banks 0/1 group, away from the sprite read. The 68000 has a DTACK
  handshake and the sound Z80 runs at 2 MHz — roughly 3× the main Z80's margin,
  which is why item 4c's CPU-ROM-in-SDRAM failed and these are expected to
  work. `SND_IN_SDRAM` reverts the sound one at the cost of 8 blocks.
- `clk_sys` worst-case slack is **0.027 ns** (Fmax 40.086 vs 40.000 MHz) on
  `core_reset_s1 → scroll_core/palette`. It passes, but there is no headroom
  left in that domain — a reset-fanout path, so pipelining `core_reset` into
  each core is the obvious relief if anything else has to go in.
- **Escape hatch, still open**: GW5AST-138 has **298 blocks** vs 118, and 138k
  LUT. All four families fit with ~170 spare, no surgery. `mcr2_console138k/`
  is a stale pre-fix top and CLAUDE.md warns the net→ball map is SOM-specific.
- **MCR-1 is next and now has ~1 block of room**, so it needs real work:
  hoist its bg, and either the CPU-ROM-56K trim (−4) or the MCR-2 sprite move
  (−16). See TODO 4a-bis levers 3 and 4.

### 4. Owed cleanup
TEMPORARY diagnostics are still in the merged core (stored-ROM audit, liveness
counters in beacon E0/E1, the `if (1'b0)`-disabled v6 sweeps). Keep the audit —
retire the rest once Timber closes.

## The instrument that matters: stored-ROM audit

In `mcr23_console60k_top.sv`. After each load it sweeps all four ROM RAMs through
their **port B** (the download port, idle after loading, so the core's port A is
untouched) and checksums what actually LANDED. ~3 ms. Beacon **E5 cpu / E4 snd /
E6 bg1 / E7 bg2**; expected values from `tools/ckstore.py`.

Validated exact on Satan's Hollow (`B23C/BC50/6F34/6030`).

This exists because **three separate bugs this session had the identical shape —
delivered correctly, STORED wrongly** (sprite shift, MCR-2 bg plane 2, Timber
colours) and the older download-*stream* checksums matched through every one of
them. If a game looks wrong, read this audit before theorising.

## Traps that bit repeatedly — read this before editing

1. **Gowin use-before-declaration → silent 1-bit wire.** Cost time ~4 times in
   one session. A multi-bit signal used above its declaration becomes ONE
   floating bit with only a warning. `grep -ci "Undeclared symbol"
   impl/gwsynthesis/*.log` **must be 0** — it is a build-breaker, not a nit.
2. **Stream checksums cannot see storage bugs.** See above.
3. **Resource probes silently prune the thing you are measuring.** A constant
   select (`game_id[3]`, provably 0) deleted a whole core's video path and
   under-reported by 27 blocks; a tied-off `dl_wr` let synthesis prove a
   `LOADABLE` ROM permanently empty and delete 16 more. **Always check the
   probed module's BSRAM against its standalone figure.**
4. **A ROM whose BSRAM count SHRINKS is a disconnected ROM.** The 25K silently
   went 56→51 because bg ports were left unconnected — and the build succeeded.
5. **A power cycle boots SPI FLASH, not what was last JTAG-loaded.** Confused two
   test sessions. Flash lagged 7 commits once and produced "baked Tapper
   graphics" on a card-out test that looked like a bug in new work.
6. **One reading of a time-varying quantity is not evidence.** Dropout rate and
   animate-vs-frozen both fooled me. Use A/B/A. A 20%-vs-2% "regression" in the
   merged core evaporated on the third measurement.
7. **`dpram` modes**: `INIT_FILE` = baked default with a writable port B;
   `LOADABLE(1)` = blank but writable; **neither = port B READ-ONLY**. Dropping a
   bake without adding `LOADABLE` silently kills the download. Pinned by
   `sim/dpram/`.
8. **Connecting `q_b` at all** makes the tool infer write-through and reject with
   `PA2122`. Port B now reads only when not writing.
9. **gfx1 bg plane order is PER-CORE**: MCR-3 wants the ROM MAME loads SECOND,
   MCR-2 the FIRST, **MCR3Scroll the FIRST** (its bg dprams are wired
   uncrossed, unlike `mcr3.vhd`'s — verified by reading the instances, NOT on
   hardware). Verify new games with
   `mame -listxml <game> | grep 'region="gfx1"'`. Wrong order = right shapes,
   wrong colours, bg only.
10. **Mixed-language instantiation on Gowin is case sensitive, and a component
    cannot share a name with its package.** FX68K's upstream binding hits both:
    EX4806 resolves the component to the package `fx68k`, and EX4968 rejects
    `extReset`/`enPhi1`/`iEdb` because VHDL folded them to lower case. The fix
    is a lower-case-port wrapper reached by direct entity instantiation
    (`src/rtl/FX68K/fx68k_lc.sv`) — the same route `mcr2.vhd` already uses for
    `dpram.sv`. Expect this for every future SystemVerilog core.

## Bench state

- Board: merged core in SRAM **with** the stored-ROM audit; **frozen on Timber**
  (prefs select it) — the pending measurement above.
- SPI flash: merged core *without* the audit (`console60k_mcr23_merged.fs`).
  Reflash after any change you want surviving a power cycle.
- SD card: freshly written pack v2, all 12 games, byte-verified. `write_pack_v2.py`
  now verifies the WHOLE image (header-only verification hid a partial write).
- Prefs sector 2047 holds slot + family; both are honoured at boot.

## Things I got wrong, so they are not re-derived

- handoff v8's "instance-dependent" sprite fault: it was deterministic all along.
- "Timber has a stale card" → wrong; I had you rewrite the card twice for nothing.
- "Timber is crashing/frozen" → wrong; it animates. I compared stills without
  checking for motion.
- "The merged core worsens HDMI dropouts" → wrong, A/B/A disproved it.
- "MCR-3+MCR-2 fits with no SDRAM work" → wrong by 8 blocks; the probe caught it.
- "The SDRAM ROM path itself is broken" → wrong; I misattributed Timber's known
  bug. CPU-ROM-in-SDRAM genuinely fails (latency); the sound ROM is unproven.

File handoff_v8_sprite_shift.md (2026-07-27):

# Handoff v8 — MCR-3 Tapper sprite "detached handle" investigation (2026-07-27)

## RESOLVED 2026-07-27 — root cause was a pipeline-depth mismatch in the
## sprite dl→SDRAM write path (`mcr3_console60k_top.sv`), introduced by 500c74a

**The bug was never instance-dependent.** It was present on every load of
every build after 500c74a ("Pack format v2"), including the 2026-07-25
flash build the user saw. The whole "instance dependence" premise below is
wrong; it came from instruments that were structurally blind to the fault
(see "why every check missed it").

**Root cause.** In the port2 sprite write, the address and byte-lane came
from the 2-deep synchronizer (`dl_sp_off_s2`) while the data was taken
LIVE off `dl_data`:

```
if (dl_wr_s1 && !dl_wr_s2 && dl_sp_rng_s2) begin
    p1_a_r  <= {7'b0, dl_sp_off_s2[14:0], dl_sp_off_s2[16]};  // depth 2
    p1_ds_r <= {dl_sp_off_s2[15], ~dl_sp_off_s2[15]};         // depth 2
    p1_d_r  <= {dl_data, dl_data};                            // depth 0  <-- BUG
```

`dl_wr`'s rising edge is detected on the clk_sdram cycle at which `_s2`
still holds the PREVIOUS byte's offset, so byte j's data was written to
byte j−1's address. The entire 128 KB sprite array was stored as
**`mem[i] = blob[i+1]`** — exactly the shape derived from the screen in
"The symptom" below. Before 500c74a (3dbe824, the archived working build)
address AND data both came live off `dl_addr`/`dl_data`, which is why that
archive renders the mug perfectly.

**Fix.** Give `dl_data` the same pipeline depth as the address
(`dl_data_s1/s2`, write `{dl_data_s2, dl_data_s2}`). MCR-1 and MCR-2 are
unaffected — only MCR-3 crosses the dl bus into the SDRAM clock domain.

**Evidence (three independent confirmations of the same +1):**
1. *Hardware histogram.* The audit's nonzero-word counts by `i%4` read
   `{0x1B0A, 0x1AD8, 0x1409, 0x128A}` on 13/13 loads (6 rounds of
   2026-07-26 + a fresh load today). The prediction computed from the ROM
   is `{0x1289, 0x1B0A, 0x1AD8, 0x1409}` — the measured tuple is that one
   **rotated left by one, bit-exact on three of four buckets**. Rotation
   ⇔ `mem[i] = blob[i+1]`. (Item 5 below misreported this as a match; it
   put 0x128A on E0, but the logs have it on E3.)
2. *On screen, live.* A fresh load today shows the artifact plainly —
   detached 8 px slivers beside the patron and the barman, mug interior
   pulling in neighbouring-word pixels (`scratchpad now/f_121.png`,
   zoom `zz_before.png`). No warm board, no power cycle, no OSD reload
   needed.
3. *Simulation.* `scratchpad/dlsync_tb.v` (iverilog) models the loader and
   both wirings: old ⇒ `mem[i] = blob[i+1]` on every byte; new ⇒ clean.

**Why every check in "What is PROVEN" missed it.** Items 1–4 and 6 are all
still true — and all blind to this fault:
- The offline blob decode (1) and MAME (2) examine the *blob*, not the array.
- The RTL sim (3) and the upstream diffs (4) cover the sprite *engine* and
  `sdram_gw`; the fault is upstream of both, in the top's dl plumbing.
- The pattern substitution (6, and the audit's E4 compare) writes its
  synthetic pattern keyed on `dl_sp_off_s2` — the *destination* index. So
  the pattern lands wherever the address says, and reads back perfectly
  aligned no matter how shifted the address is. E4 = 0x0000 was a
  tautology; the per-pixel run-length capture proved word→slot mapping,
  which was never the broken part.
- Only the bucket histogram compares blob content against array position,
  which is why it is the one instrument that caught it. It is kept (now
  E0..E3, all four buckets) as the per-boot canary; the prediction command
  is in the comment at the audit declaration. Tapper expects
  `{0x1266, 0x1B00, 0x1AD1, 0x13E4}` (real ROM, no pattern).

The TEMPORARY pattern substitution and the E4 compare are removed. The
`if (1'b0)`-disabled v6 diagnostics are still in the tree and still owed a
cleanup pass.

Everything below is the pre-resolution investigation, kept for the record.
Its "instance dependence", "leading suspects" and "recommended next steps"
sections are superseded — do not act on them.

---

Start after `handoff_v7_jukebox.md`. This documents the user-reported
"sprites are cut off — look at the beer glass" bug (2026-07-25), what has
been PROVEN, the instruments now in the tree/bitstream, and exactly what
remains. An experiment was still running on the bench when this handoff
was written — see "In flight" at the bottom.

## The symptom, precisely characterized

On the artifact session (flash build of 2026-07-25, bad6bd5-era), sprites
render with their **last-drawn 8px word-slot displaced one slot (8px) to
the right, with a transparent gap where it belongs**:

- sliding empty mug: [glass 16px][8px gap][detached handle 8px]
- patrons: body intact + a detached 8px sliver one slot right of the body
- capture evidence: scratchpad `live_199.png`, zooms `zz_mug199.png`,
  `zz_patron199.png` (scratchpad = the session temp dir; re-derive from
  any capture of an affected boot if lost)

The observable is EXACTLY equivalent to the sprite array reading as
`mem[i] = blob[i+1]` (one 32-bit-word global shift): for the empty-mug
tile (code 23, handle in ROM word 0, drawn UNflipped) a +1 shift renders
[w1 glass][w2 glass][w3 = empty = GAP][next-line w0 = handle]. Same math
reproduces the patron sliver. This artifact is SESSION/INSTANCE-dependent:
every load taken on 2026-07-26/27 is clean (see below).
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

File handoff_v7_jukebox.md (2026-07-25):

# Handoff v7 — the MCR jukebox: MCR-3 working, pack v2, roadmap underway

**Date: 2026-07-25. Supersedes v5/v6 (whose sprite-bug conclusions were
disproved) and updates v4 (platform).** The authoritative work queue is the
ROADMAP at the top of `TODO.md`; this handoff is the narrative state.

## What works, verified on hardware

- **MCR-3 / Tapper on the Tang Console 60K**: full attract + gameplay,
  sprites from the Tang SDRAM module, colors verified against reference
  screenshots (MobyGames) over HDMI capture. In SPI flash as the power-on
  default; archived as
  `bitstreams/console60k_mcr3_tapper_sprites_working.fs`.
- **Cold boot < 10 s** via the HALT wedge-watchdog (the Z80 crashes on
  some cold boots for a still-unidentified power-event-scoped reason
  during its first seconds; the watchdog detects the halted CPU and
  retries the full reset+reload path until the game runs — typically one
  retry).
- **MCR-2 60K** unchanged-working (six games, OSD switching, prefs).

## The two discoveries that unblocked everything

1. **SDRAM pin-clock phase (THE sprite fix).** The Tang SDRAM module
   (Winbond W9825G6KH) is fine. `sdram_gw` forwarded SDRAM_CLK at 0
   degrees; the chip then samples commands at the exact instant they
   change, and that margin drifts with temperature/activity — data
   "decayed" to FF within ~30-100 s of idle no matter what refresh
   scheme ran. Every nand2mario design drives this module's clock pin
   from a ~225-degree-shifted PLL output. Adopting that (one PLLA output,
   `gowin_pll_core80` CLKOUT3 -> `sdram_gw.clk_fwd`) fixed retention
   completely (0 errors at 8+ minutes idle). Retention harnesses to
   re-verify any change: `mcr2_console60k/diag/build_retention.tcl`
   (nand2mario reference controller) and `build_gwret.tcl` (ours).
2. **Tapper bg colors**: the bg ROM planes were swapped in
   `tools/merge_roms.py`. Rule since: **MAME's per-game gfx1 load order
   is the law** (Timber's is opposite Tapper's).
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

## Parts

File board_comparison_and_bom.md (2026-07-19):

# FPGA Board Comparison & Custom Shield BOM

This document provides a cost and feature comparison of the various Sipeed Tang FPGA board options for building the Bally Midway MCR arcade core, followed by a Bill of Materials (BOM) estimate for the custom **Option A Shield** (Universal MCR Cabinet Interface).

---

## 1. FPGA Board & Hardware Setup Comparison

Here is a comparison of the primary hardware architectures we evaluated for running the MCR arcade core, including where the **iCEPi Zero** fits in.

| Specification / Option | Tang Primer 25K (V1 On-Chip) | Tang Primer 25K (V2 SDRAM) | iCEPi Zero (Lattice ECP5) | Tang Console 60K | Tang Console 138K |
| :--- | :--- | :--- | :--- | :--- | :--- |
| **FPGA Chip** | GW5A-LV25 | GW5A-LV25 | Lattice ECP5U-25F | GW5A-LV60 | GW5AST-LV138 |
| **Logic Cells (LUT)** | 23,040 | 23,040 | 24,000 | 60,000 | 138,240 |
| **On-Chip Block RAM** | 126 KB (56 blocks) | 126 KB (56 blocks) | 112 KB | ~320 KB (140+ blocks) | 765 KB (340 blocks) |
| **External Memory** | None | 64Mbit SDRAM Card | **32MB SDRAM** (Onboard) | **512MB DDR3** (On SOM) | **1GB DDR3** (On SOM) |
| **Free GPIO Pins** | **26** (40-Pin) + **8** (PMOD) | **8** (PMOD 1 only) | **28** (40-Pin Header) | **92** (76 GPIO + 16 PMOD) | **92** (76 GPIO + 16 PMOD) |
| **MCR Game Support** | Partial (No Playfield Gfx) | Full MCR-1/2/3 Games | Full MCR-1/2/3 Games | Full MCR-1/2/3 Games | Full MCR-1/2/3 Games |
| **Video & Audio Path** | On-board parallel | HDMI -> VGA/Audio Dongle | GPDI Port / Parallel | Onboard Native HDMI & DAC | Onboard Native HDMI & DAC |
| **Pin Congestion** | Low | High (Pmod sharing) | Low (SDRAM is onboard) | Zero | Zero |
| **Toolchain** | Gowin EDA | Gowin EDA | **Open Source** (yosys/nextpnr) | Gowin EDA | Gowin EDA |
| **Estimated Price (Kit)**| **~$29.00** [1] | **~$39.00** (Kit + SDRAM) [2] | **$79.00** [3] | **$69.00** [4] | **$99.00** [5] |
| **Extra Modules Needed** | PMOD HDMI ($5) | PMOD HDMI ($5) + Dongle ($5) | GPDI-to-HDMI Cable ($5) | None | None |
| **Total Hardware Cost**  | **~$34.00** | **~$49.00** | **$84.00** | **$69.00** | **$99.00** |

### Recommendations:
* **Best Value / Easiest Integration: Tang Console 60K ($69)** [4]
  Because the DDR3 memory is built directly into the System-on-Module (SOM), it does not block the carrier board's pins. With **92 free GPIO pins**, native HDMI, and onboard audio DACs, you do not need shift registers or HDMI converters. It has more than enough on-chip block RAM (320KB) to run any MCR game without memory limits.
* **Cheapest Entry Point: Tang Primer 25K V1 ($34)** [1]
  Great for initial desk testing and cabinet control/audio wiring verification. However, playfield background graphics are disabled to fit the block RAM budget.

---

## 2. Custom Shield Bill of Materials (BOM) Estimate

Below is the estimated Bill of Materials to manufacture and assemble the custom **Option A Interface Shield** (Universal MCR Cabinet Interface).

### Option A.1: Parallel Shield (For Tang Primer 25K V1, or Tang Console 60K/138K)
This PCB is a passive shield that routes video, audio, and inputs in parallel. It is simple, highly reliable, and uses no active serial ICs.

> **Update (2026-07):** the shipping Console 60K design adds **two 74HC165
> shift registers** (~$0.30) for the 16 configuration DIP switches. Cabinet
> I/O stays parallel/opto-isolated; only the DIPs are serial, which keeps the
> J9 SDRAM slot free for the large MCR-3 ROM sets. See
> `docs/universal_mcr_shield_spec.md` §7.

| Item | Component Description | Designator | Qty | Unit Cost | Total Cost | Source Example |
| :--- | :--- | :--- | :--- | :--- | :--- | :--- |
| 1 | **Custom PCB (2-Layer)** | Board | 1 | $2.00 | $2.00 | JLCPCB / PCBWay (qty 5 minimum) |
| 2 | **opto-isolators (4-channel)** | U1, U2, U3 | 3 | $0.40 | $1.20 | TLP281-4 (SMD) |
| 3 | **LM386 Mono Audio Amp** | U4 | 1 | $0.35 | $0.35 | LM386 (DIP or SOIC) |
| 4 | **5V Step-Down Buck Regulator** | VR1 | 1 | $1.20 | $1.20 | LM2596 Module or MP1584EN |
| 5 | **R2R Resistor Arrays (10k/20k)** | RN1, RN2, RN3 | 3 | $0.20 | $0.60 | 9-pin SIP Resistor Network |
| 6 | **Discrete Resistors & Caps** | R1-R20, C1-C10 | 1 | $1.00 | $1.00 | 0805 SMD Resistors/Capacitors |
| 7 | **BC847 NPN Transistor** (Sync) | Q1, Q2 | 2 | $0.05 | $0.10 | BC847 (SOT-23) |
| 8 | **MCR Connector Headers** | J2, J3, J4, J5 | 4 | $0.50 | $2.00 | 2.54mm Pin Headers / Molex KK |
| 9 | **Female Pin Headers (to Dock)** | JP1, JP2 | 2 | $0.40 | $0.80 | 40-Pin and PMOD sockets |
| **Total**| | | | | **~$9.25** | *Excludes shipping (~$15 from China)* |

---

### Option A.2: Serial Shift-Register Shield (For Tang Primer 25K V2 + SDRAM)
If using the SDRAM card on the Tang Primer 25K, you must read the buttons serially due to pin starvation. This shield adds shift registers to read controls over 3 PMOD pins.

| Item | Component Description | Designator | Qty | Unit Cost | Total Cost | Source Example |
| :--- | :--- | :--- | :--- | :--- | :--- | :--- |
| 1 | **Custom PCB (2-Layer)** | Board | 1 | $2.00 | $2.00 | JLCPCB |
| 2 | **74HC165 8-bit Shift Register**| U1, U2 | 2 | $0.15 | $0.30 | 74HC165 (SOIC-16) |
| 3 | **opto-isolators (4-channel)** | U3, U4 | 2 | $0.40 | $0.80 | TLP281-4 |
| 4 | **5V Step-Down Buck Regulator** | VR1 | 1 | $1.20 | $1.20 | MP1584EN Buck Board |
| 5 | **Discrete Resistors & Caps** | R1-R20, C1-C10 | 1 | $1.00 | $1.00 | 0805 SMD |
| 6 | **MCR Connector Headers** | J2, J3, J4, J5 | 4 | $0.50 | $2.00 | 2.54mm Molex KK |
| 7 | **Female Pin Headers (to Dock)** | JP1 | 1 | $0.40 | $0.40 | 12-pin PMOD socket |
| **Total**| | | | | **~$7.70** | *Excludes shipping* |

---

## 3. Reference Pricing & Purchase Links

*   **[1] Tang Primer 25K Dock Kit:** ~$29.00 on the [Sipeed AliExpress Store](https://www.aliexpress.com/item/1005006093452411.html).
*   **[2] Tang SDRAM Expansion Module (64Mbit):** ~$10.00 on the [Sipeed AliExpress Store](https://www.aliexpress.com/item/1005006122648719.html) or Youyeetoo.
*   **[3] iCEPi Zero (Lattice ECP5):** $79.00 retail on [Elecrow Store](https://www.elecrow.com/icepi-zero-fpga-development-board.html) or [Mouser Electronics](https://www.mouser.com/ProductDetail/Crowd-Supply/CS-ICEPIZERO-01). Educational discount price is $65.00 via developer contact on the [iCEPi Zero GitHub Page](https://github.com/cyao7878/icepi-zero).
*   **[4] Tang Console 60K (SOM + Dock Bundle):** ~$69.00 on the [Sipeed AliExpress Store](https://www.aliexpress.com/item/1005007421111111.html).
*   **[5] Tang Console 138K (SOM + Dock Bundle):** ~$99.00 on the [Sipeed AliExpress Store](https://www.aliexpress.com/item/1005007421111111.html).

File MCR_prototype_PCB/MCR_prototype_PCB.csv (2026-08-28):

Id | Designator | Footprint | Quantity | Designation | Supplier and ref
1 | C1, C41, C42, C48, C50, C52, C53, C54, C55, C56, C57, C58, C59, C60, C61, C62, C63, C64, C65 | C_0805_2012Metric | 19 | 0.1 uF
2 | C2, C3, C4, C6, C8, C45, C46, C47 | C_0805_2012Metric | 8 | 0.01 uF
3 | C5, C7 | CP_Radial_D10.0mm_P5.00mm | 2 | 4.7 uF 50V
4 | C9, C10 | CP_Radial_D10.0mm_P5.00mm | 2 | 10 uF 50V
5 | C43, C44 | C_1210_3225Metric | 2 | 22 uF
6 | C49, C51 | CP_Elec_6.3x5.4 | 2 | 100 uF
7 | D1, D2, D3, D35, D36, D37, D38 | LED_0805_2012Metric_Pad1.15x1.40mm_HandSolder | 7 | LED
8 | D4 | D_DO-201AD_P15.24mm_Horizontal | 1 | 1N5822
9 | J0 | PinSocket_2x20_P2.54mm_Vertical | 1 | Conn_02x20_Odd_Even
10 | J1 | PinHeader_1x20_P2.54mm_Horizontal | 1 | Conn_01x20_Pin
11 | J1-VGAOut1 | DSUB-15-HD_Socket_Horizontal_P2.29x1.90mm_EdgePinOffset3.03mm_Housed_MountingHolesOffset4.94mm | 1 | DE15_Socket_HighDensity
12 | J2_RGBS_Out1, J3 | PinHeader_1x09_P2.54mm_Horizontal | 2 | Conn_01x09_Pin
13 | J3_DOT1 | PinHeader_1x10_P2.54mm_Horizontal_mirrored | 1 | Conn_01x10_Pin
14 | J4 | PinHeader_1x19_P2.54mm_Horizontal | 1 | Conn_01x19_Pin
15 | J5 | PinHeader_1x23_P2.54mm_Horizontal | 1 | Conn_01x23_Pin
16 | J6 | PinHeader_1x10_P2.54mm_Horizontal | 1 | Conn_01x10_Pin
17 | JP1 | PinHeader_1x02_P2.54mm_Vertical | 1 | 15 kHz Select
18 | JP2 | PinHeader_1x02_P2.54mm_Vertical | 1 | Composite Sync Select
19 | JP3 | PinHeader_1x02_P2.54mm_Vertical | 1 | Vertical Sync Inactive select
20 | L1, L2 | L_Bourns_SRR1260 | 2 | 3.3 uH
21 | R1, R2, R3, R4, R5, R10, R11, R12, R13, R22, R23, R95, R98, R101 | R_0805_2012Metric | 14 | 1k
22 | R6 | R_0805_2012Metric_Pad1.20x1.40mm_HandSolder | 1 | 2k ohm
23 | R7 | R_0805_2012Metric_Pad1.20x1.40mm_HandSolder | 1 | 510 ohm
24 | R8 | R_0805_2012Metric_Pad1.20x1.40mm_HandSolder | 1 | 220 ohm
25 | R9 | R_0805_2012Metric_Pad1.20x1.40mm_HandSolder | 1 | 1k
26 | R14, R15, R16, R17, R19, R20, R21 | R_0805_2012Metric | 7 | 75
27 | R18 | C_0805_2012Metric | 1 | 75
28 | R92, R93 | R_0805_2012Metric | 2 | 100
29 | R94, R97, R100 | R_0805_2012Metric | 3 | 510
30 | R96, R99, R102 | R_0805_2012Metric | 3 | 2k
31 | R103, R104 | R_0805_2012Metric | 2 | 10k
32 | RN1, RN2, RN3, RN4, RN5, RN6 | R_Array_SIP9 | 6 | 4.7k ohm
33 | RN7, RN8, RN9, RN10, RN11, RN12, RN13, RN14 | R_Array_Convex_4x0603 | 8 | 1K Ohm
34 | SW1, SW2 | SW_DIP_SPSTx08_Slide_9.78x22.5mm_W7.62mm_P2.54mm | 2 | SW_DIP_x08
35 | SW3 | SW_SPST_PTS645Sx43SMTR92 | 1 | Service
36 | TP1 | TestPoint_Loop_D1.80mm_Drill1.0mm_Beaded | 1 | +12V Input
37 | TP2 | TestPoint_Loop_D1.80mm_Drill1.0mm_Beaded | 1 | +3.3V Power
38 | TP3 | TestPoint_Loop_D1.80mm_Drill1.0mm_Beaded | 1 | +5V Power
39 | TP4 | TestPoint_Loop_D1.80mm_Drill1.0mm_Beaded | 1 | Gnd
40 | TP5 | TestPoint_Loop_D1.80mm_Drill1.0mm_Beaded | 1 | In_Clk
41 | TP6 | TestPoint_Loop_D1.80mm_Drill1.0mm_Beaded | 1 | IN_LOAD_N
42 | TP7 | TestPoint_Loop_D1.80mm_Drill1.0mm_Beaded | 1 | VID_HS
43 | TP8 | TestPoint_Loop_D1.80mm_Drill1.0mm_Beaded | 1 | VID_VS
44 | TP9 | TestPoint_Loop_D1.80mm_Drill1.0mm_Beaded | 1 | GND
45 | U1, U2, U3, U4, U6, U7 | SOIC-16_3.9x9.9mm_P1.27mm | 6 | 74AHC165
46 | U5, U15, U16, U17, U18, U19, U22, U23 | SOT-23-6 | 8 | SRV05-4
47 | U8, U9 | SOIC-16_3.9x9.9mm_P1.27mm | 2 | 74HC595
48 | U10, U11 | SOIC-18W_7.5x11.6mm_P1.27mm | 2 | ULN2803CDWR
49 | U12, U13 | TSSOP-14_4.4x5mm_P0.65mm | 2 | THS7374
50 | U14 | TSSOP-16_4.4x5mm_P0.65mm | 1 | ADS7830
51 | U24 | Converter_DCDC_RECOM_R-78B-2.0_THT | 1 | R-78B5.0-2.0
52 | U25 | Converter_DCDC_RECOM_R-78B-2.0_THT | 1 | R-78B3.3-2.0

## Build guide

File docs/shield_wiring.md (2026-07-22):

# MCR shield — connector footprints & chip wiring

Build companion to `shield_j10_pinout.md` (the FPGA-side header) and
`universal_mcr_shield_spec.md` (electrical spec). This is the **cabinet
side**: which physical connectors the harness plugs into, and how the
input/output/analog chips wire between those connectors and the J10 header.

Interface style is settled (spec §0): the **cabinet harness plugs into the
shield**; the FPGA maps every pin per game, so nothing is rewired. Rev A
targets the **SSIO-family connectors** (MCR-1/2 + SSIO MCR-3).

Connector types, pin counts and **pitch** are from **`docs/MCR Series
Pinouts.html`** (John Sanford's archived MCR reference) — the real board
connectors. Per-pin/per-game signal meaning is in that file and
`docs/mcr_game_input_matrix.md`. Still confirm the exact housing/keying
against a physical harness before ordering.

---

## 1. Cabinet connectors (what the harness plugs into)

Authoritative source: **`docs/MCR Series Pinouts.html`** (John Sanford's MCR
pinout reference, archived) — the real board-connector table. **These are
the actual MCR connectors and this is the real J-numbering** (it matches
MAME's `ssio:IP*` J-comments). It supersedes the normalized numbering in the
"Master Pinout Matrix" PDF (whose J2/J3/J4/J5 are *cabinet-function*
labels, not the physical connectors) — for footprints, use THIS table.

**Only the power connector is .156"; every signal connector is .100" MTA:**

| Ref | Board | Pins | Pitch | Carries |
|---|---|---:|---|---|
| **J1** | CPU | 20 | **.156" MTA** | **Power in**: +5 V ×4, GND ×4, +12 V, V.BATT, RESET, audio GND, key |
| **J2** | CPU | 9 | **.100" MTA** | **Video**: Red, G, B (+ Video GND ×3), key, HSync(−), VSync(−) |
| **J3** | — | 9/10 | **.100" MTA** | **Audio** out + a volume-control pot |
| **J4** | SSIO | 19 | **.100" MTA** | **IP0** (Coin1/2, 1P/2P Start, button, Tilt, Service, Test, GND) + **IP1** (D0–D7 game inputs, key) |
| **J5** | SSIO | 23 | **.100" MTA** | **IP2** (P2 controls / trackball-Y / more inputs) |
| **J6** | SSIO | 10 | **.100" MTA** | **IP4** (aux: P3 stick, second dial, etc.) |

**MTA = the AMP/TE MTA series** (MTA-156 for J1, **MTA-100 for J2–J6**).
Classic Bally/Midway friction-lock IDC headers. Match the exact pin count
and keyed position per connector; the per-pin/per-game signal detail is in
the HTML above and `docs/mcr_game_input_matrix.md`.

Consequences for the shield footprints:
- **The input chain feeds off J4 (19-pin), J5 (23-pin), J6 (10-pin)** — all
  **.100"**. J4 alone carries IP0 **and** IP1 (coins/starts/button + the
  8-bit player/dial bus), so it's the busiest connector.
- **J1 is the only .156" part** — and the shield ideally powers from its own
  12 V terminal rather than the cabinet 5 V rail (spec §6.1), so J1 may only
  be needed for V.BATT/RESET/audio-GND references, not the 5 V rail.
- **Video is J2 (.100", 9-pin)** — not a .156 part. The R2R DAC + sync buffer
  drive it.
- **Audio + volume is J3 (.100")** — the original had a panel volume pot on
  J3; keep a pot footprint or fix the level in the PWM/amp stage.
- **Key pins** (J1, J2-7, J4-14) are mechanical keys — leave blank/plugged.
- Grounds (J4-9, Video GNDs, J1 GNDs) tie to the shield star ground.

Note on the dial games: the 8-bit bus on J4/J6 (Tron, Kick, Kroozr, etc.) is
**parallel digital** — the cabinet's *Angle Encoder Board* converts the
knob's quadrature to parallel before the connector (MCR FAQ). So the '165
reads it directly **if that board is present**; a bare encoder would need
quadrature decode in the FPGA (`spinner.sv`).

Pin-by-pin, using the **real board numbering** (from `MCR Series
Pinouts.html`); the FPGA re-interprets the game-specific bits per game:

```
J1 (power): 1-4 +5V  5-8 GND  9 KEY  10 V.BATT  11 RESET  12 +12V  13 audio-GND
J2 (video): 1 Red  2 GND  3 Green  4 GND  5 Blue  6 GND  7 Key
            8 HSync(-)  9 VSync(-)
J3 (audio): speaker out + a 3-terminal volume pot
J4 (SSIO, IP0+IP1):
   IP0  1 Coin1  2 Coin2  3 1P-Start  4 2P-Start  5 Button/Fire
        6 Tilt   7 Service  8 Test    9 GND
   IP1  10-13 = D0..D3   14 Key   15-18 = D4..D7   (D0-7 = the game's
        player stick / dial / buttons, per docs/mcr_game_input_matrix.md)
J5 (SSIO, IP2):  23-pin — P2 controls / trackball-Y / more inputs
J6 (SSIO, IP4):  10-pin — aux (P3 stick, second dial, …)
```

---

## 2. Input chain — harness → 74AHC165 → FPGA

Every switch/data line goes: **cabinet pin → passive pad → 74AHC165
parallel input**. The FPGA clocks the chain out on 3 J10 pins
(`IN_CLK`/`IN_LOAD_N`/`IN_DATA`). Allocate **one '165 per SSIO input port**
(spec/pinout §6a) so 3-player and remapped-connector games all fit.

### 2a. The per-line conditioning pad (identical on every input)

```
   cabinet pin ──┬───[ 4.7kΩ ]─── +5V        (pull-up: idle = high)
                 │
                 └───[ 1kΩ ]──┬────────── 74AHC165 input (A..H)
                              │
                    10nF ═════╪═════ GND      (RC ~10µs debounce/filter)
                              │
                    BAT54S ───┤          (clamp to +5V / GND: a 12V
                     (dual)   │           miswire drops across the 1kΩ)
```

74AHC165 runs at **3.3 V**; its inputs are 5.5 V-tolerant, so they take the
5 V harness levels directly (spec §2). Idle = 5 V = logic 1; a closed
switch pulls to GND = logic 0 — the same polarity the SSIO saw.

### 2b. Chain topology (7 devices, 3 FPGA pins)

```mermaid
flowchart LR
    subgraph FPGA["Tang 60K (J10)"]
      CLK["IN_CLK (pin25)"]
      LD["IN_LOAD_N (pin26)"]
      DAT["IN_DATA (pin27)"]
    end
    U1["U1 74AHC165<br/>IP0: coins/start/tilt/svc/btn"] -->|QH→SER| U2["U2 74AHC165<br/>IP1: P1 stick / dial"]
    U2 -->|QH→SER| U3["U3 74AHC165<br/>IP2: P2 / trackball-Y / gas"]
    U3 -->|QH→SER| U4["U4 74AHC165<br/>IP4: aux / P3 stick"]
    U4 -->|QH→SER| U6["U6 74AHC165<br/>SW1 game DIPs (IP3)"]
    U6 -->|QH→SER| U7["U7 74AHC165<br/>SW2 system DIPs"]
    CLK -->|CP, bussed to all| U1
    LD -->|PL̄, bussed to all| U1
    U7 -->|QH| DAT
```

`IN_LOAD_N` low pulse snapshots **all** '165 inputs at the same instant, so
the 8-bit dial/trackball buses can't tear. Control lines (`CP`, `PL̄`) bus
to every device; only the last device's `QH` returns on `IN_DATA`.

Per-'165 pin map (all devices identical): `CP`=pin2, `PL̄`=pin1,
`QH`=pin9, `SER`(cascade in)=pin10, `CE̅`=pin15→GND, `VCC`=pin16→3V3,
`GND`=pin8. Parallel inputs A..H = pins 11,12,13,14,3,4,5,6.

### 2c. Which harness pins land on which '165

| '165 | SSIO byte | Real connector pins → A..H |
|---|---|---|
| U1 | IP0 | **J4 pins 1-8**: Coin1, Coin2, 1P-Start, 2P-Start, Button, Tilt, Service, Test |
| U2 | IP1 | **J4 pins 10-13,15-18**: D0..D7 (the game's P1 stick / dial / extra buttons) |
| U3 | IP2 | **J5** (23-pin): P2 controls / trackball-Y / more inputs |
| U4 | IP4 | **J6** (10-pin): aux — **P3 stick (Rampage)**, second dial, … |
| U6/U7 | IP3 | on-shield SW1 / SW2 DIP banks (no harness) |

Because it's the real connectors, the mapping is clean — one '165 per SSIO
byte, and J4 alone feeds U1+U2. What the D0–D7 bits on IP1 (and IP2/IP4)
*mean* is per game (stick vs dial vs buttons); the FPGA maps it, so the
wiring is identical across all games.

---

## 3. Output chain — FPGA → 74HC595 → ULN2803 → loads

Two '595s (16 bits) on 4 J10 pins (`OUT_CLK`/`OUT_DATA`/`OUT_LATCH`/
`OUT_EN_N`), then a ULN2803 per '595 for the 12 V coin meters/lamps.

```mermaid
flowchart LR
    subgraph FPGA["Tang 60K (J10)"]
      OCK["OUT_CLK (pin28)"]
      OD["OUT_DATA (pin31)"]
      OL["OUT_LATCH (pin32)"]
      OE["OUT_EN_N (pin34)"]
    end
    OD --> U8["U8 74HC595"]
    U8 -->|QH'→SER| U9["U9 74HC595"]
    OCK -->|SRCLK, bussed| U8
    OL -->|RCLK, bussed| U8
    OE -->|OE̅, bussed + pull-up| U8
    U8 --> UA["ULN2803"] --> L1["Coin meters, Start lamps, P3 lamp"]
    U9 --> UB["ULN2803"] --> L2["output_6 / Spy Hunter lamp panel"]
```

- `OUT_EN_N` **must have a 10 kΩ pull-up to 3V3 on the shield** so all
  outputs stay off through FPGA configuration (no coin-meter clicks).
- ULN2803 has built-in flyback diodes — fine for inductive coin meters.
- Loads run off cabinet 12 V; the ULN sinks to GND.

Per-'595: `SER`=pin14, `SRCLK`=pin11, `RCLK`=pin12, `OE̅`=pin13,
`QH'`(cascade)=pin9, `QA..QH`=pins15,1..7, `VCC`=16→3V3, `GND`=8.

---

## 4. Analog controls — the ADC (Spy Hunter & Max RPM only)

**Which games need it:** exactly two, both later-phase:

| Game | Family | Pots | MAME device |
|---|---|---|---|
| **Spy Hunter** | MCR3Scroll | steering + gas (2, muxed) | on-board ADC0848/0844 |
| **Max RPM** | MCR3Mono | 2 wheels + 2 pedals (4) | ADC0844 |

**Every other MCR control is digital** — buttons/sticks are switches, and
the dials/spinners/trackballs (Tron, Kick, Kroozr, Wacko, Two Tigers, Discs
of Tron) are **optical encoders**, which the FPGA decodes with the existing
`spinner.sv` quadrature logic. No ADC for any of those.

Why an ADC is needed here and nowhere else: on the real hardware the
steering/gas **potentiometers' analog wiper voltage came into the game
board and was digitized by an on-board ADC0844** (MAME instantiates it in
the machine config, e.g. `ADC0844(config, m_maxrpm_adc)` with the pots on
its channels). Our shield replaces that board, so it must carry the ADC to
read the pots. The pot wires arrive on the **Opt X (J4) / Opt Y (J5)**
lines — the same physical pins a dial game would drive digitally.

### 4a. Put it on the board with a switch — yes, and here's how

Because a cabinet is *one* game, and the analog pins overlap the digital
Opt X/Opt Y pins, route those lines to **either** the '165 (digital) **or**
the ADC (analog), selected per cabinet:

```mermaid
flowchart LR
    J4["J4 / J5 data lines<br/>(dial data OR pot wiper)"]
    JMP{"MODE jumper<br/>per channel"}
    P165["→ 74AHC165 pad<br/>(digital dial games)"]
    ADC["ADC (SPI)<br/>pots → 8-bit"]
    J4 --> JMP
    JMP -->|DIGITAL| P165
    JMP -->|ANALOG| ADC
    ADC -->|SPI: SCLK/MOSI/MISO/CS on<br/>3 spare J10 pins + 1| FPGA["Tang 60K"]
    P165 --> FPGA
```

Recommended parts and wiring:
- **ADC: a modern SPI ADC — ADS7830 (8-ch, I²C) or MCP3208 (8-ch, SPI),
  populate-optional.** (You *can* use a real ADC0844 to match, but a modern
  SPI/I²C part is far easier to talk to from the FPGA and needs no special
  timing.) 8 channels covers Max RPM's 4 and Spy Hunter's 2 with room.
- **Analog reference / conditioning:** each pot wiper → RC (series ~1 kΩ,
  100 nF to GND) → ADC channel; pot ends to the shield's clean 5 V and GND.
- **MODE jumpers:** a small 2-pin jumper (or a 2-pole DIP) per analog
  channel selects that harness line to the '165 pad or the ADC input. Set
  once at install ("this cabinet is Spy Hunter → Opt X = ANALOG").
- **FPGA side:** the ADC's SPI/I²C lands on **spare J10 pins** (9, 19, 20,
  29/30, 38 are free) — no impact on the input/output chains. The core reads
  the ADC channels and feeds the digitized value into the analog input port;
  the running game_id tells it whether to use the ADC or the '165 byte.

### 4b. FPGA-driven mode switch (recommended — no jumper)

The manual jumper works, but the FPGA can drive the digital/analog switch
itself, which keeps the "select the game, nothing else" promise for the
analog cabinets too. It's actually cleaner **and reuses hardware already on
the shield**:

```mermaid
flowchart LR
    GID["core game_id<br/>(from OSD)"] --> MB["MODE bit<br/>= analog for<br/>Spy Hunter / Max RPM"]
    MB -->|rides a spare<br/>74HC595 output bit| SW["74HC4053 analog switch<br/>(per analog channel)"]
    J["J4/J5 analog-capable pin"] --> SW
    SW -->|MODE=digital| PAD["4.7k pull-up + '165 pad"]
    SW -->|MODE=analog| ADCIN["ADC channel (clean)"]
```

How it works, step by step:

1. **The FPGA already knows the running game** (`game_id` from the OSD). It
   derives one **MODE** bit — high only for Spy Hunter / Max RPM. MODE is
   static per game (set when the game loads, never changes mid-play).
2. **MODE rides a spare bit of the existing 74HC595 output chain** — no new
   J10 pin. The '595s are already on the board for lamps/meters; one unused
   output bit becomes the mode line.
3. That bit drives a **74HC4053-class analog switch** on each analog-capable
   channel (≈4: Max RPM's worst case). In **digital** mode the pin routes to
   its normal pull-up + '165 pad; in **analog** mode the switch **lifts the
   pull-up** and routes the pin straight to the ADC channel. Lifting the
   pull-up is the whole point — a 4.7 kΩ pull-up to 5 V would offset a pot's
   reading, so it must be out of circuit for analog.
4. In analog mode the '165 still *sees* that pin and clocks in some
   arbitrary 0/1 — **harmless, the FPGA ignores those bits for that game.**

**Bonus you get for free:** the *channel* muxing (steering vs gas; which of
Max RPM's four axes) was **already game-driven on the original hardware** —
the game wrote the ADC0844's channel select and RD/WR strobes through its
SSIO output ports (`mcr3.cpp`: Max RPM latches the mux on `output`, Spy
Hunter toggles the ADC via an output bit). Our core reproduces those output
ports, so if you wire the core's `output_4/5/6` to the ADC's channel-select/
strobe lines, the game sequences the ADC exactly as it did in 1984 — no
extra logic. The only *new* thing is the per-cabinet digital-vs-analog pin
routing (MODE), because a universal shield serves both a dial cabinet and a
pot cabinet on the same pins, whereas the original Spy Hunter board was
always analog.

**Recommendation:** design for the FPGA-driven switch (MODE on a '595 bit +
74HC4053s), and keep a **manual override jumper in parallel** as a
populate-option fallback — cheap insurance while the analog path is
unproven. Cost over the jumper-only build: ~one 74HC4053 (maybe two) and a
few traces; payoff: the analog cabinets are as plug-and-play as the rest.

**One detail to lock down at Phase D:** exactly which harness pins carry the
Spy Hunter / Max RPM pot wipers (the master matrix normalizes them onto the
"Opt X D0–D7" label, but 2 pots ≠ 8 data bits, so the physical wiper pins
need confirming against those games' schematics). Finalize the analog
channel count and pin map when the first analog core (Spy Hunter) is brought
up — until then, route the ADC + switch footprints for the worst case (4
channels) and leave them unpopulated.

---

## 5. Video DAC & sync buffer (live today)

- **RGB:** 3-bit R2R per gun into **J2** (the 9-pin .100" video conn) pins
  1/3/5 — MSB 510 Ω, then 1 kΩ, 2 kΩ,
  summed into the monitor's 75 Ω ≈ 1 Vp-p (bench-proven, `bench_wiring.md`).
  Drive from J10 `VID_R/G/B` (§ pinout). J2 pins 2/4/6 = Video GND.
- **Sync:** J10 `VID_HS`/`VID_VS` (3.3 V, negative) → 74HCT244 at 5 V (TTL
  thresholds accept 3.3 V in) → J2 pins 8/9. Real MCR monitors take separate
  H/V; the pin-39/40 straps offer csync for OSSC/RetroTink gear.
- **15 kHz:** close the J10 pin-37 solder jumper for cabinet timing.

---

## 6. Power

Cabinet **+12 V → screw terminal → buck (5 V, ≥1.5 A) → LDO (3.3 V)**.
5 V feeds the AHC/HC logic rails and the input pull-ups; 3.3 V is the logic
VCC and the FPGA level. Audio amp (LM386) runs off the 12 V rail. Do not
back-feed the cabinet 5 V (spec §6.1).

---

## 7. BOM summary (control interface)

| Qty | Part | Role |
|---:|---|---|
| 7 | 74AHC165 | input chain (5 V-tolerant, 3.3 V VCC) |
| 2 | 74HC595 | output chain |
| 2 | ULN2803 | 12 V coin-meter / lamp drivers |
| 1 | 74HCT244 | 5 V sync buffer |
| 1 | ADS7830 / MCP3208 (opt.) | analog pots (Spy Hunter / Max RPM) |
| 1–2 | 74HC4053 (opt.) | FPGA-driven digital/analog mode switch (§4b); MODE rides a spare '595 bit |
| — | manual MODE jumper (opt., fallback) | override the FPGA switch per cabinet |
| — | R2R resistors (9), sync caps, BAT54S clamps, pull-ups | passives |
| 1 | buck + LDO | 12 V → 5 V → 3.3 V |
| — | MCR MTA connectors: J1 (.156" 20-pin power), J2–J6 (.100" MTA: video/audio/inputs) | harness interface |

Everything except the ADC block is required for every cabinet; the ADC
block is populate-if-analog.

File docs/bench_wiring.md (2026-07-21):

# Bench wiring — Tang Console 60K (current bitstream)

What the **bitstreams in `bitstreams/` actually drive today**. Generated from
`mcr2_console60k/src/mcr2_console60k.cst`; if you change the CST, update this.

> Building the shield PCB? Use **`shield_j10_pinout.md`** — its "live"
> pins are exactly this page's assignments (deliberately, so current
> bitstreams drive the shield unchanged), plus the reserved control-chain
> pins. Spec §4a remains the authority for which FPGA ball a J10 pin
> reaches; this page is which *signal* is on it in today's bitstreams.

## Finding pin 1 on J10

J10 is the 2×20 header **nearest the PMOD sockets** (the other one, J9, is
the SDRAM slot — leave it alone). Odd pins are one row, even the other, so
pins 1/2 face each other, 3/4, and so on.

**Anchor electrically, don't count from the end:** with the board powered,
find the pair reading **+5 V and GND** — that is pins **11 and 12**, the
sixth pair. Count from there. Pin 12 is your ground for everything below.

## Current J10 map

| J10 pin | Signal | Notes |
|---:|---|---|
| 1, 2, 3, 4 | `vga_r[0..3]` | red, LSB→MSB |
| 5, 6, 7, 8 | `vga_b[0..3]` | blue, LSB→MSB |
| 11 | **+5 V** | supply *out*; do not back-feed (see TODO) |
| 12 | **GND** | reference for everything |
| 13, 14, 15, 16 | `vga_g[0..3]` | green, LSB→MSB |
| 17 | `vga_hs` | HSync — carries **CSYNC** in 15 kHz mode |
| 18 | `vga_vs` | VSync |
| 21 | `debug_o[0]` | DDR3 calibration done — steady 3.3 V = trained |
| 22 | `debug_o[1]` | pixel-clock heartbeat — should bounce ~1 Hz |
| 23 | `debug_o[2]` | 27 MHz reference heartbeat — bounces ~0.8 Hz |
| 24 | `debug_o[3]` | DDR reset — steady LOW when healthy |
| 35 | `audio_l` | PWM, needs an RC filter before an amp |
| 36 | `audio_r` | PWM |
| 37 | `mode15_n` | **open = 31 kHz**, jumper to GND = 15 kHz |
| 39 | sync format | 15 kHz: open = separate H/V (default), GND = composite sync on HS |
| 40 | VSync enable | 15 kHz: open = VS driven, GND = VS held inactive |

Everything else on J10 is unassigned in the current bitstream; pins
25-34 are RESERVED for the shield's input/output shift-register chains
(`shield_j10_pinout.md`) — leave them free on bench hookups too.

## Analogue video, option A — DE-15 breakout + 9 resistors

Cheapest and least ambiguous: a screw-terminal VGA breakout, no active
parts, and it doubles as a prototype of the shield's video DAC.

Use only the **top three bits** of each colour (`[3:1]`) — bit 0 is just an
MSB copy for the 4-bit Pmod, so leave `vga_*[0]` unconnected.

| VGA pin | From J10 pins (MSB→LSB) | Through |
|---|---|---|
| 1 (Red) | 4, 3, 2 | 510 Ω, 1 kΩ, 2 kΩ — join at the terminal |
| 2 (Green) | 16, 15, 14 | 510 Ω, 1 kΩ, 2 kΩ |
| 3 (Blue) | 8, 7, 6 | 510 Ω, 1 kΩ, 2 kΩ |
| 13 (HSync) | 17 | direct (or ~100 Ω) |
| 14 (VSync) | 18 | direct |
| 5,6,7,8,10 (GND) | 12 | direct |

560 Ω / 1.1 k / 2.2 k are fine substitutes.

## Analogue video, option B — Digilent PmodVGA

**The Rev C PmodVGA is not passive.** It has two SN74ALVC245 buffers that
must be powered or it outputs nothing:

- **Feed VCC 3.3 V** (J1 pin 6 or 12, and J2 pin 6 or 12).
- **Never 5 V** — the ALVC245's absolute maximum supply is ~4.6 V, so J10
  pin 11 would risk damaging the module. Take 3.3 V from a PMOD socket's
  3V3 pin.

Jumper recipe (J10 → Pmod):

| J10 | PmodVGA |
|---|---|
| 1,2,3,4 | J1 pins 1,2,3,4 (R0–R3) |
| 5,6,7,8 | J1 pins 7,8,9,10 (B0–B3) |
| 13,14,15,16 | J2 pins 1,2,3,4 (G0–G3) |
| 17 | J2 pin 7 (HS) |
| 18 | J2 pin 8 (VS) |
| 12 | J1 pin 5 and J2 pin 5 (GND) |
| 3V3 from a PMOD socket | J1 pin 6 and J2 pin 6 (VCC) |

**Plugging the Pmod straight into the two PMOD sockets is not currently
supported.** Sipeed's socket pin order is not Digilent's, and the two straps
that used to resolve that mapping (J10-39/40) were repurposed for the 15 kHz
sync format, which turned out to matter more. The jumper recipe above works
regardless of socket orientation.

## 15 kHz vs 31 kHz

- **J10-37 open** → 31 kHz progressive, works on any VGA monitor.
- **J10-37 to GND** → native 15 kHz arcade timing (15.77 kHz; displays
  usually report it as "16 kHz", which is correct). Needs an arcade CRT,
  multisync, or an OSSC/RetroTink — an ordinary VGA LCD will not sync, which
  is expected rather than a fault.

### 15 kHz sync format (J10-39 / J10-40)

Displays disagree about what a 15 kHz source should look like, so the format
is strap-selectable rather than baked in:

| J10-39 | J10-40 | Output at 15 kHz |
|---|---|---|
| open | open | **separate H and V sync — default**, and what a real MCR cabinet uses (Video pins 8 and 9) |
| GND | open | composite sync on HS (RGBS) — for an OSSC/RetroTink or SOG-wired monitor |
| GND | GND | composite sync on HS, VS inactive — single-sync RGBS |
| open | GND | separate H sync, VS inactive |

31 kHz always uses separate H/V regardless of these straps.

**If a display drops a whole colour channel at 15 kHz** (green vanishing is
the classic symptom — greys turn magenta, olive turns purple, red and blue
stay correct), it has mis-detected the sync format, not lost a wire: the
FPGA drives all three channels through identical logic and cannot lose one
on its own. Composite sync used to be the default here and provoked exactly
that on a 15 kHz-capable LCD. **Displays latch their format detection**, so
switching format while the signal is live often will *not* re-trigger it —
disturb sync or power-cycle the display between attempts, or the test looks
like it failed when it did not.

HDMI keeps working in both modes (the framebuffer captures whatever the core
emits), so you always have a reference picture.

## No wiring needed

- **HDMI** — onboard connector.
- **USB gamepad** — left USB-A port. **Select+Start opens the game-select
  OSD** (Up/Down move, A loads from the SD pack, B exits). The screen
  freezing (HDMI) or dropping sync (VGA) for ~1 s after pressing A is the
  reload, not a crash.
- **MicroSD** (ROM loading) — onboard slot.
- **Status beacon** — USB-C serial, 115200 8N1: `FB c_ r_ x____ q__ d__ L__`
  (DDR calib, DDR reset, pixel-clock counter, 27 MHz counter,
  d = game_id[2:0] in the high 3 bits + capture delay in the low 5).
  `L` high nibble = {heartbeat, heartbeat, usb_typ[1:0]} — **usb_typ = 3
  means a gamepad is enumerated**, 0 = nothing answered on USB; low nibble
  = {sd_ready, sd_err, loader done, loader error}.

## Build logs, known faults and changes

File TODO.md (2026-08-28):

# TODO / open issues

> **For the consolidated view — current state, what is verified, and what is
> still MISSING (speech, Journey, cocktail mode, NVRAM, lamps, scaler
> rotation) — read `handoff_v10_complete_roster.md` first.** This file is the
> detail behind it, and it is long: cocktail mode is ~1800 lines down.

Single list of known gaps. Detail lives in the linked docs; this is the
index so nothing hides in a §6 somewhere. Roughly ordered by "blocks the
next real milestone" within each section.

## ROADMAP — the MCR jukebox (agreed 2026-07-24, in priority order)

1. **HDMI dropout fix.** MAJOR FIX LANDED 2026-07-25, measured via the
   capture card: the framebuffer's sample clock ran at 48 kHz while
   AUDIO_OUT_RATE declared 32 kHz to the HDMI stack's ACR - a 50% rate
   lie. Making both 32 kHz took content frames from 14% to 41-69%
   (3-5x). The earlier "32k hung the monitor" trial was almost certainly
   a corrupt un-verified flash, not the rate change. A fractional-exact
   divider was tried and made things WORSE (clk_audio is a real clock
   downstream; edge jitter >> ppm offset) - reverted, do not repeat.
   RESIDUAL RESOLVED TO BOARD THERMAL 2026-07-26: udev rule added for the
   capture card (99-mcr-capture.rules, 534d:2109 -> plugdev) enabling
   unprivileged USB reset; a fresh card reset does NOT recover the rate
   (86% -> 71%), but an overnight cool-down took the identical build from
   28% to 86% content. The drift is the BOARD warming - suspects: TMDS
   analog margin, or the DDR3 wr-FIFO holds (+0.001 ns). Ground truth
   still wanted: the user's monitor impression on the consistent-32k
   build (warm vs cold). Cosmetic: /etc/udev/rules.d/99-mcr-capture.rules
   has a stray indented EOF line from the heredoc - harmless, cleanable
   with: sudo cp 99-mcr-capture.rules /etc/udev/rules.d/ (clean copy in
   the repo root).
   **NEW LEAD 2026-07-27/28 — a RECONFIG recovers it, which cooling cannot
   explain.** Measured repeatedly across one long session on the same board:
   | when | dropout | context |
   |---|---|---|
   | cold, post-reconfig | 1% | |
   | after hours on ONE config | 57% | |
   | post-reconfig | 1% | no cooling |
   | after sitting on one config | 20% | |
   | post-reconfig (mcr3) | 2% | minutes later |
   | post-reconfig (merged) | 0% | minutes later |
   EVERY low reading follows a reconfiguration; every high one follows a long
   run on a single configuration. A reconfig does not cool the board, but it
   DOES re-run DDR3 calibration and re-lock the PLLs - so the degradation
   looks like calibration DRIFT that re-calibration fixes, rather than an
   analog TMDS margin that only cooling fixes.
   This also puts a confound in the existing "board thermal" conclusion: the
   overnight-cool-down test that took 28% -> 86% content also POWER CYCLED
   the board, which is itself a reconfiguration. Cooling and recalibration
   were never separated.
   **SOAK RESULT 2026-07-28 — recalibration IS a large lever, measured:**
   after 25 min on one configuration the board sat at **52% dropout**;
   reconfiguring WITHOUT touching thermals took it straight to **18%** - a
   3x recovery in the ~30 s a reconfig takes, over which the board cannot
   meaningfully cool. So the degradation is substantially recoverable in
   GATEWARE. It is not the whole story (18% is still far from the 0-2% seen
   on a cool board, so temperature matters too), but "wait for it to cool"
   is not the only fix, and it is not one a cabinet owner can apply.
   NEXT: a managed/periodic DDR3 re-calibration, or at minimum re-calibrate
   on a trigger. Caveat on the measurement: the reconfig also loaded a
   slightly newer bitstream (same design plus a post-load audit sweep), which
   cannot plausibly account for a 3x change but is worth repeating cleanly.
   ALSO RULED OUT: the merged core is NOT worse than the single-family build.
   An A/B/A (merged 20%, mcr3 2%, merged 0%) shows the spread is time
   variation, not the extra 54% of logic - do not chase clock-gating for this.

   Original notes: Mechanism cornered: audio data islands, 48 kHz
   divider actually emits 48,027 Hz vs ACR constants claiming 48,000 →
   sinks periodically resync. The 32 kHz quick-try killed sync because ONLY
   the divider changed — a correct fix sets rate + ACR N/CTS consistently
   through the hdl-util hdmi instantiation (N=4096 for 32 k / 6144 for 48 k),
   or copies whatever current nestang does here (refs/nestang vendorable).
   Evidence + revert details: commits 2bee7ea/2424e0c, and the two-cause
   entry below (thermal residual is secondary).

2. **All cores load ROMs from the SD card ("everything-from-SD").** NOW A
   LICENSING REQUIREMENT, not just an optimisation: no copyrighted ROM data
   may ship inside a distributed bitstream, so the INIT_FILE bakes have to
   go and the card becomes mandatory.
   **STATUS 2026-07-27 — the mechanism is already built and wired.** Every
   ROM in all three families has a dl write decode driving `dpram` port B:
   MCR-2 `mcr2.vhd` (bg1/bg2/sprite gfx) + top (cpu/snd), same for
   `mcr1.vhd`, and MCR-3 (bg via core dl, sprites via SDRAM). And `dpram`
   in INIT_FILE mode is a TRUE dual-port RAM — the file is only the
   power-on default and port B writes land normally. (CLAUDE.md's "port B
   is inert in the dpram ROM mode", and the same line in mcr2.vhd:768, are
   STALE — they describe an older dpram. Fixed 2026-07-27.)
   **DONE for all three 60K boards 2026-07-27** — no 60K bitstream contains
   ROM data any more:
   - `dpram` gained a `LOADABLE` mode ("writable dual-port, NO init file").
     Needed because the generate picks `ram_mode` when INIT_FILE is empty
     and there port B is READ-ONLY — dropping a bake without it silently
     kills that ROM's download path. All three modes pinned in `sim/dpram/`.
   - mcr3_console60k un-baked and **hardware-verified**: Tapper and Timber
     both render correctly with a completely ROM-free bitstream.
   - mcr1_console60k and mcr2_console60k un-baked, and **BOTH VERIFIED ON
     HARDWARE 2026-07-27** loading entirely from the card with no ROM data
     in the bitstream: MCR-2 booted Wacko (58 distinct frames/90, 1 black)
     and MCR-1 booted Kickman — its first ever hardware run — with colours
     compared against MAME (skyline, pink text, mauve buildings, brown
     ladders, red/yellow balloons all match). MCR-1's picture is rotated on
     a normal monitor, which is CORRECT for its ROT90 cabinet. BSRAM
     unchanged (77/118 and 94/118), TNS 0.000.
     Not yet exercised: MCR-1 Kick and Solar Fox; MCR-2's other five.
   - Bake control is a per-board GENERIC on mcr1.vhd/mcr2.vhd
     (`GFX1_1_INIT`/`GFX1_2_INIT`/`GFX2_INIT`/`GFX_LOADABLE`), defaults
     baking, so mcr2_primer25k and mcr2_console138k are untouched. The 25K
     stays baked on purpose — fixed-function single-game board.
   **"INSERT CARD" screen — DONE and HARDWARE-VERIFIED 2026-07-27.** Booted
   with the card physically out: the message appears (no game, as intended -
   there is no baked fallback any more). Inserting the card while it ran was
   picked up within seconds and booted straight into the saved game with NO
   power cycle, which is the behaviour that matters for a cabinet (no reset
   button). Implementation notes in src/rtl/osd.sv - the core must NOT be
   held in reset while the screen is up (mcr1/2/3.vhd hold hcnt/vcnt at zero
   under reset and the OSD draws in the core raster domain, so resetting
   blanks the message), retries are self-paced off loader_error, and leaving
   the screen pulses core reset so the Z80 restarts cleanly on real ROMs.
   Still owed:
   - `merge_roms` still emits `rom_*.hex` for the 25K/138K, and
     `game_config.vh` is still needed on the 60K for `GAME_DEFAULT` (the
     slot used when the prefs sector has no valid entry).
   Feeds directly into item 4's merge — the shareable ROM RAM is what makes
   one bitstream hold all three cores.

3. **Add MCR titles until the series is complete.** PROGRESS 2026-07-27:
   **NINE GAMES SHIP IN ONE BITSTREAM** (mcr23_console60k, the flashed
   power-on default): all six MCR-2 titles plus all three MCR-3 titles, each
   verified on hardware, switchable from the OSD with the choice persisted
   across power cycles and across families.
   **ALL THREE MCR-3 TITLES NOW WORK ON HARDWARE** - Tapper, Timber and
   Discs of Tron. Timber plays perfectly when chosen from the OSD (only the
   boot-load caveat below is outstanding). Discs of Tron renders correctly
   after the sprite bitplane fix; its screen is mirrored, which is CORRECT
   (the real cabinet uses a mirror). Remaining for DoT: the aim DIAL is not
   wired (aim uses the dedicated IP2 buttons).
   Earlier notes:
   Timber and Discs of Tron added end-to-end (specs from MAME 0.265 source,
   input maps, OSD slots 1/2, pack entries).
   **TIMBER — TWO FAULTS. Colours FIXED; a BOOT-LOAD CRASH is still open.**
   (1) *Wrong bg colours* — FIXED and hardware-verified 2026-07-27. Root
   cause was the gfx1 PLANE ORDER in merge_roms (see the per-core rule
   below). Confirmed against MAME: the TREES LEFT / TIME LEFT boxes are now
   black with an orange border and orange text, bushes green, cabin red.
   (2) *Boot-load renders corrupt bg tiles; OSD load is fine* — OPEN, and
   the ONLY thing outstanding for Timber. Chosen from the menu it plays
   perfectly (owner-confirmed), so this is a boot-path defect, not a
   "Timber does not work" one.
   **Two earlier write-ups of this were WRONG and are corrected here:**
   it is NOT a stale SD card (the pack image was decoded and compared
   byte-for-byte against the ROMs - every region MATCHes, and two rewrites
   changed nothing), and it is NOT a crash/freeze (the game animates: ~39
   distinct non-black frames per 100 captured; an earlier "3 distinct
   frames" reading caught a dropout-heavy window, not a frozen core).
   MEASURED on a FAILING boot load, all with the TEMPORARY instruments now
   in the top:
   - download-stream checksums ALL CORRECT: cpu 8279, snd CB8C, bg1 773D,
     bg2 5B14 - exactly what tools/ck.py predicts from the ROMs. So the
     loader DELIVERS every byte of every region correctly.
   - sprite audit bit-exact ({0E74,1786,17FD,0FE1}) on every boot.
   - CPU is ALIVE: hwin = 0xFF (the code's own "running" signature) and
     kick_n = 0, so the wedge watchdog never fires. Boot sequence normal
     (rr_rises 2, rst_evts 2, boot_kicked 1).
   - Not any 2026-07-27 RTL change: a bitstream built before all of it
     behaves identically. Not Tapper: it boot-loads fine, repeatedly.
   So the bytes are delivered correctly and the CPU runs, yet bg tiles are
   wrong - which means the suspect is what actually LANDS IN the bg dprams,
   not what was sent. That is the exact shape of the sprite bug fixed this
   morning (stream correct, storage corrupted by an address/data pipeline
   mismatch), so it is the obvious place to look.
   NEXT STEP: a read-back audit of the two bg dprams after load, mirroring
   the sprite audit that has worked so well - connect their port-B q_b,
   sweep and checksum, compare against tools/ck.py. That distinguishes
   "stored wrong" from "stored right but rendered wrong" in one boot.
   Still unexplained and worth keeping in mind: why an OSD-commanded reload
   of the same slot produces a correct picture when the boot path does not.
   CAUTION: the board reaches ~57% black frames (thermal HDMI dropout, TODO
   item 1) after hours of running - capture-based measurements get
   unreliable, so prefer beacon counters over screenshots when it is warm.
   **DISCS OF TRON — WORKS. Sprite bitplane padding FIXED and
   HARDWARE-VERIFIED 2026-07-27.** Screen is mirrored, which is CORRECT (the
   real cabinet uses a mirror). Confirmed on the board after a card rewrite:
   sprite audit bucket2 reads 09F7 (the bitplane-padded prediction; the
   broken layout read 126A), and all four download checksums match
   tools/ck.py exactly - cpu 621C, snd 2FE4, bg1 2DF3, bg2 02AF - with
   kick_n=0 / hwin=0xFF showing a healthy CPU.
   Original symptom: ran, but sprites striped / missing interior pixels. Cause: the MCR-3 sprite engine fetches each 32-bit word
   as {Q3[i],Q2[i],Q1[i],Q0[i]} from the FOUR 32 KB QUARTERS of the 128 KB
   region, so every bitplane owns a fixed 32 KB slot. merge_roms simply
   concatenated the gfx2 files and padded at the END, which is only correct
   for a full 128 KB set (tapper/timber: 8 x 16 KB, each pair exactly fills
   a quarter). DoT has 8 x 8 KB = 64 KB, so it landed as Q0=files0-3,
   Q1=files4-7, Q2=ZEROS, Q3=ZEROS - sprites drawn with 2 of 4 bitplanes,
   i.e. missing pixels. Fix: assemble gfx2 BY PLANE, padding each pair to
   its 32 KB slot. tapper/timber are byte-identical afterwards (verified);
   only DoT changes. Gated to family==mcr3: MCR-1/MCR-2 sprites are a FLAT
   32 KB region (one aWidth=15 dpram read 8 bits at a time), and padding
   their planes overflowed the region and shifted every later game in the
   pack - caught before commit. New DoT sprite-audit tuple:
   {0x046E, 0x099B, 0x09F7, 0x04F0}.
   DoT's aim DIAL still not wired (uses the dedicated IP2 buttons). DoT's aim DIAL not wired yet (aim uses its
   dedicated IP2 buttons; spinner.sv WIRED 2026-07-24 - aim buttons rotate the dial; swap minus/plus if inverted on hardware).
   Remaining: Next: Timber, Discs of
   Tron (MCR-3, same core as Tapper); then the MCR3Scroll games (Spy Hunter,
   Crater Raider, Journey) per docs/mcr_core_roadmap.md; MCR3Mono stays
   parked for a board rev (future/README.md). Also: MCR-1 (Kick/Solar Fox)
   is built but never hardware-verified — verify while at it. Remember the
   Tapper lesson: bg ROM plane order bg0->gfx1_1 for EVERY new game.

4. **Core switching (multi-FAMILY). DECISION 2026-07-27: MERGE MCR-1/2/3
   into ONE bitstream; multiboot is deferred to MCR3Scroll/MCR3Mono.**
   Driver: ROMs must stream from the user's SD card for licensing anyway
   (no copyrighted ROM data may ship inside a bitstream), and that is the
   same work that makes a merged core fit. Merged, core switching becomes
   the instant SD reload that game switching already is — no reconfig, no
   flash slot map, no wire. See items 4a/4b below for the budget and the
   multiboot findings (kept: Scroll/Mono will need them).

   **4a. Merge budget — MEASURED, not estimated (2026-07-27).** A throwaway
   two-core probe build (`merge_probe/`, MCR-3's top with an MCR-2 core
   alongside sharing the CPU/sound ROM RAM) was built through PnR to get real
   numbers, because the arithmetic was WRONG. Predicted 114, actual **122 —
   PnR refused it: "ERROR (PA2017) The number(122) of BSRAM exceeds the
   resource limit(118)"**. The gap: shared infrastructure is ~20 blocks, not
   the 12 the synthesis per-module list suggests (PnR packing, plus the SD
   reader / dump / audit RAMs that never show as named modules).
   Logic is a non-issue throughout: the 2-core probe is 18.8k of 60k LUT.
   Real per-board totals and the model they give:
   | Build | BSRAM | = infra + ROMs + core |
   |---|---|---|
   | mcr3 alone | 88 | 20 + 40 + 28 |
   | mcr2 alone | 94 | 20 + 40 + 34 |
   | mcr1 alone | 77 | 20 + 24 + 33 (32K CPU ROM) |
   | **mcr3+mcr2 probe** | **122** | 20 + 40 + 28 + 34 — **OVER by 4** |
   Where that leaves each option:
   | Plan | BSRAM | |
   |---|---|---|
   | 2-way (mcr3+mcr2), bg gfx RAMs shared | **114** | **MEASURED, fits** |
   | 2-way (mcr3+mcr2), MCR-2 sprites -> SDRAM | 106 | fits, but needs sprite surgery |
   | 3-way as-is | 155 | way over |
   | 3-way, BOTH sprite sets -> SDRAM | 123 | still over |
   | 3-way, + bg gfx shared (28 -> 16) | **111** | fits, 7 spare |
   **So the sprite->SDRAM move is required even for a TWO-family merge** -
   the earlier claim that mcr3+mcr2 "fits today with no SDRAM work" was based
   on the bad arithmetic and is retracted. The 3-way additionally needs the bg
   gfx RAMs shared, which means hoisting them out of the vendored cores.
   REVISED ORDER (2026-07-27, after looking at the sprite pipelines):
   (1) DONE - hoist the bg gfx RAMs out of mcr2.vhd/mcr3.vhd and share them.
       Re-probed at **114/118, PnR accepts it**. Chosen over the sprite
       ->SDRAM move because MCR-2 has NO latency slack for SDRAM: MCR-3 has
       8 phases between latching the sprite code and drawing the first pixel
       (which is what absorbs the round trip), MCR-2 has 1. Moving its
       sprites would mean restructuring the sprite pipeline - the same
       surgery that produced the detached-sprite bug.
   (2) DONE - mcr23_console60k merges MCR-2 + MCR-3, 9 games in one
       bitstream, 114/118 BSRAM, flashed as the power-on default.
       **ALL NINE GAMES VERIFIED ON HARDWARE**: Tapper, Timber, Discs of
       Tron, Satan's Hollow, Tron, Wacko, Kozmik Kroozr, Two Tigers,
       Domino Man - including the analogue-control ones (Tron's aim
       spinner, Kroozr's dial + synthesised stick), whose wiring was ported
       wholesale from the standalone MCR-2 top.
       Three bugs found and fixed during bring-up, all worth remembering:
       - MCR-2's bg PLANE 2 landed 8 KB high in the shared 16 KB RAM: its
         region starts at 0x1E000 and the write address sliced [13:0]
         (=0x2000). MCR-3's bg2 is at 0x18000 where that is 0, so it only
         showed on MCR-2 games - as "slightly wrong palette".
       - a SAVE recorded the wrong family: rom_loader's `family` feeds both
         the entry search and prefs byte 9, but the save runs after the menu
         closes, so it wrote boot_family instead of the chosen game's.
       - `ldr_family` was defined in terms of `run_family`, which latches on
         the same edge - so it latched its own stale value and the wrong
         CORE ran while the right DATA was loaded.
       The first is the important one: the download-stream checksums matched
       throughout, because they measure what the loader DELIVERS, not where
       it LANDS. Same blindness that hid the sprite bug. A storage-side
       read-back audit is still the missing instrument.
   (3) MCR-1: hoist its bg too, and take on the sprite->SDRAM surgery with a
       known-good merged reference to compare against.
   (4) Fold MCR-1 in (111/118 with both sprite sets in SDRAM).
   **4a-bis. MCR3Scroll FOLDED IN AND MEASURED (2026-07-30) - board
   `mcr23s_console60k/`, 12 games across three families.** Not a throwaway
   probe this time: a real merge, with the roster, input maps, ROM specs and
   pack layout done (`merge_roms` family `mcr3scroll`, `make_pack_v2` family 3,
   15 games in `mcr_pack_v2.img`). Scaler kept as `ddr3_framebuffer` - the
   cheap one - because BSRAM is the resource in question; `ascal_v` would add
   10 blocks.
   PnR numbers, `ddr3_framebuffer`, CSD ROM already in SDRAM:
   | Configuration | BSRAM | verdict |
   |---|---|---|
   | mcr2+mcr3 (today, shipping) | 114 | fits |
   | + MCR3Scroll, CSD/FX68K IN | **127** | over by 9 |
   | + MCR3Scroll, CSD/FX68K OUT (`SCROLL_CSD=0`, Crater Raider only) | **127** | over by 9 |
   | ...then the two levers below | **fits, PnR places it** | **12 games, one bitstream** |
   Logic is a non-issue: 33.5k of 59.9k (56%), registers 25%.
   **The Cheap Squeak Deluxe / FX68K stack costs ZERO BSRAM blocks** - the two
   builds above differ only in whether it is compiled and land on the same 127.
   Its microcode ROMs (`uRam`/`nRam`) and the 68000 register file
   (`regs68H`/`regs68L`) map to ROM16/SSRAM, not block RAM. So the handoff's
   "+ MCR3Scroll + FX68K ~130" was close on the total but wrong about the
   cause: the 68000 is free, the cost is MCR3Scroll's own video/sprite RAMs.
   What made it fit in the first place, and cost nothing:
   - bg gfx pair HOISTED out of `mcr3scroll.vhd` and shared, as `mcr3.vhd`'s
     was on 2026-07-27 (note it is UNCROSSED there, unlike mcr3.vhd)
   - the 128 KB sprite region in SDRAM shared with MCR-3, write swizzle and
     all: `mcr3scroll.vhd`'s sprite fetch is byte-identical to `mcr3.vhd`'s, so
     `merge_roms` assembles its gfx2 by plane into four 32 KB slots and the
     existing port2 path is reused unchanged
   - the 32 KB CSD 68000 ROM in SDRAM on the idle **port1/cpu2** group (banks
     0,1), which is what upstream MiSTer does too. In BSRAM it would be 16
     blocks. The 68000's DTACK handshake absorbs the latency - unlike the main
     Z80, which is why 4c's CPU-ROM-in-SDRAM failed. UNVERIFIED on hardware.
   Closing the 9-block gap - both levers applied, PnR-measured:
   | Step | BSRAM | |
   |---|---|---|
   | 3-family, as first built | 127 | over by 9 |
   | + sprite line buffers -> LUT RAM | **125** | over by 7 |
   | + sound ROM -> SDRAM | **PnR ACCEPTS - it PLACES** | fits |
   1. **Sprite line buffers -> LUT RAM: -2 blocks, not the 10 hoped for.**
      Ten 256x8 buffers across the three cores (2 mcr2, 4 mcr3, 4 mcr3scroll)
      each burn a whole 18 Kb block for 2 Kb of storage. `gen_ram.sv` gained a
      `RAMSTYLE` parameter and the cores a `SPRLINE_RAMSTYLE` generic (default
      "block_ram", so every existing board is untouched). Gowin DID honour it -
      SSRAM went 98 -> 418 RAM16, synthesis BSRAM 118 -> 116 - but PnR only
      gave back 2 blocks, so it evidently packs most of those small arrays into
      shared blocks already. Cheap (+1.9k logic) and worth keeping, but do not
      budget 1 block per small RAM: **PnR packing, not the array count, decides.**
   2. **Sound ROM 16 KB -> SDRAM: this is what made it fit.** Written through
      port1 at word 0x4000 (above the CSD ROM), read on the idle `cpu3` port,
      byte lane = `snd_addr[0]`. The sound Z80 runs at 2 MHz
      (`mcr_sound_board` divides clk_sys by 20), so its address is stable
      ~500 ns per fetch against sdram_gw's ~7 clk_sys worst case - about 3x the
      main Z80's margin, which is why 4c's CPU-ROM attempt failed and this is
      expected to work. `SND_IN_SDRAM` in the top switches it back.
      **NOT hardware-verified** - 4c left it "not disproven, not verified", and
      that is still true. Side effect: the stored-ROM audit's `snd` leg (beacon
      E4) has no port B to sweep and reads 0 by design.
   **4a-ter. MCR-1 FOLDED IN AND MEASURED (2026-07-30) - `mcr123s_console60k`,
   15 games, four families. 127/118 - OVER BY 9.**
   MCR-1 costs **+10 blocks** (117 -> 127) and that is AFTER the big win:
   - **The 32 KB sprite ROM is now SHARED between MCR-1 and MCR-2.** Their
     `sprite_graphics` instances are structurally identical (dpram 8 x 32K,
     port A read on clock_vidn at `sp_code_line_mux`), and only one core is
     ever out of reset, so one RAM serves both - hoisted to the top exactly
     like the bg pair. **16 blocks, zero timing risk, no SDRAM migration.**
     This retires lever 4 below for MCR-1's half of the problem.
     Behind `SP_EXTERNAL` (mcr1+mcr2) and `BG_EXTERNAL` (mcr1) generics,
     default 0, so mcr2_primer25k / mcr2_console138k / mcr2_console60k /
     mcr1_console60k are untouched.
     TRAP: MCR-2 writes its sprite ROM through `{~dl_addr[14], dl_addr[13:0]}`
     - bit 14 INVERTED - while MCR-1 writes a plain address. That twist used
     to live inside mcr2.vhd; the top now reproduces it per loading family.
   - CPU ROM (32 KB program), sound ROM (in SDRAM) and the bg pair (4 KB
     planes at the bottom of the shared 16 KB) all shared as well.
   So the remaining +10 is MCR-1's own SCRATCH RAM: wram 2K, video_ram 1K,
   sprite_ram 512, cache 512. Logic went 60% -> 74%, registers 25% -> 28%.
   **Levers for the last 9 blocks, cheapest first:**
   1. **CPU ROM 64 KB -> 56 KB: -4, low risk.** MEASURED: the largest real
      program in the roster is 57344 bytes = 0xE000 exactly (tapper, timber,
      dotron, crater, spyhunt; turbotag's 0x10000 is 56 KB of ROM plus 8 KB of
      MRA zero padding). Every core's `cpu_rom_addr` stays below 0xE000 in
      normal operation - mcr3scroll's xor-twist maxes at 0xDFFF, and
      mcr2/mcr3 pass cpu_addr straight through but the Z80 map above 0xDFFF
      is RAM/IO, never ROM. Needs a depth parameter on `dpram` plus
      `main_pad_to=0xE000` for the scroll family.
   2. **Share the per-core SCRATCH RAMs: -9 or so, invasive.** All four cores
      have `wram` (2K), `sprite_ram` (512) and `sprites_ram_cache` (512) of
      identical shape, and only one core runs at a time - the same argument
      that just worked for the sprite ROM. Twelve more port moves across four
      vendored cores, and these have CPU WRITE ports, so it is more than the
      read-only hoists done so far.
   3. **GW5AST-138 (298 blocks): ends the whole problem**, plus 138k LUT with
      logic already at 74%. `mcr2_console138k/` is a stale pre-fix top and
      CLAUDE.md warns the net->ball map is SOM-specific.
   **BOTH LEVERS APPLIED 2026-07-30** (user-approved, "I have validated the
   cores well enough"):
   - `dpram` gained a `DEPTH` parameter and the shared CPU ROM is now 0xE000
     rather than 64 KB. The download write is gated on the same bound, because
     Turbo Tag's payload carries 8 KB of zero padding above 0xDFFF that would
     otherwise write past the end of the array. The stored-ROM audit's CPU
     sweep is bounded to match, so `tools/ckstore.py` must checksum only the
     first 0xE000 bytes to compare against beacon E5.
   - `wram` (2 KB) + `sprite_ram` (512) + `sprites_ram_cache` (512) hoisted out
     of ALL FOUR cores behind `SCRATCH_EXTERNAL` (default 0). They are
     byte-identical in every core, so one set replaces four.
     **The top muxes we/addr/d by the RUNNING family, and that is load-bearing:
     a core held in reset still presents a combinational write-enable off its
     static CPU decode, so an un-muxed OR would let an idle core corrupt the
     live game's work RAM.** This is the only change in the whole merge that
     can break a RUNNING game rather than fail to build - suspect it first if
     games show sporadic corruption.
   MEASURED, and the estimates were optimistic AGAIN - PnR, not arithmetic:
   | Step | BSRAM | |
   |---|---|---|
   | MCR-1 added, sprite ROM already shared | 127 | over by 9 |
   | + CPU ROM 64K -> 56K (predicted -4) | | |
   | + scratch RAM shared x4 (predicted -9) | 119 | over by 1 |
   | + the two shared 512x8 staging RAMs -> LUT RAM | **PnR ACCEPTS** | **15 games fit** |
   Both together gave **-8, not the -13 predicted**. Same lesson as the sprite
   line buffers: PnR already packs small arrays, so hoisting four 512-byte RAMs
   into one does NOT return four blocks. **Never budget a block per array.**
   **AND IT CLOSES TIMING - 15 GAMES, ONE BITSTREAM, ON THE 60K.**
   BSRAM 116/118, Logic 75%, **0 setup and 0 hold violations, TNS 0.000 on
   every clock**, clk_sys Fmax 43.008 vs 40.000 MHz required (+7.5%),
   clk_sdram 95.3 vs 80.0. **No larger FPGA needed.** Never run on hardware.
   Timing did NOT close by RTL work - it closed by BUILD OPTIONS:
   | Step | clk_sys setup TNS |
   |---|---|
   | shared scratch RAM, muxes as 4:1 chains | -6.342 ns / 25 eps |
   | **+ route_option 2, retiming, timing_driven, correct_hold_violation** | **-0.059 / 1** |
   | + registered mod_crater/turbo, inputs, per-core reset | **0.000 / 0** |
   `build.tcl` had only ever set `place_option 2`; the design was routed at
   DEFAULT effort for the life of the project. See the new build-options
   section in CLAUDE.md - **check those before doing RTL surgery for timing.**
   The three RTL fixes that finished it cost nothing: `ms_mod_crater`/
   `ms_mod_turbo`, `input_0..4` and a per-core `core_reset` copy, all
   registered (each only matters at game-load or switch-sample rates).
   Two lessons that cost a build each:
   - **LUT RAM is NOT a free substitute for BSRAM.** It worked for the 256-byte
     sprite line buffers; doing it to the 512-byte sprite STAGING RAMs sent
     clk_sys TNS to **-536 ns over 459 endpoints**, because a distributed-RAM
     read is a combinational walk through the LUT array fed by a 4-way family
     mux, closing on the OPPOSITE clock edge. One block bought, the whole
     clk_sys domain paid.
   - **Mux DEPTH matters on half-cycle paths.** Rewriting
     `run_is_a ? : run_is_b ? : run_is_c ? :` chains as an array indexed by
     `run_family[1:0]` - one true 4:1 mux instead of three dependent LUT
     levels - recovered ~1.75 ns of TNS for free. Keep FAM_* numbered 0..3 so
     the family code stays usable as the index.
   Every lever is a switch with a behaviour-preserving default; the table and
   the git rollback points are in `mcr123s_console60k/README.md`.

   Levers NOT needed yet, kept for MCR-1:
   3. CPU ROM 64 KB -> 56 KB (-4). Every MCR-2/3/Scroll program ROM ends at
      0xDFFF; above that the Z80 map is RAM/IO. Needs a depth parameter on
      `dpram` and a check that no core mirrors ROM above 0xE000.
   4. MCR-2 sprites 32 KB -> SDRAM (-16). The known-hard one: MCR-2 has 1
      phase of slack between latching the sprite code and drawing, MCR-3 has
      8. Pipeline surgery, not a port change.
   5. GW5AST-138 (298 blocks) - no surgery at all.
   Also fixed in the new top, still open in `mcr23_console60k`: an
   unconditional `input_4 = 8'hFF;` AFTER the input-mux `endcase` overrides
   every per-game IP4 the case sets - Wacko's aim stick, Kozmik Kroozr's
   synthesised Y axis and Two Tigers' player-2 dial all read 0xFF.
   `mcr2_console60k` does not have the line; it came in with the merge.
   Gowin trap found here: **FX68K cannot be bound the upstream way.**
   `use work.fx68k.all` + a COMPONENT in a package also named `fx68k` gives
   EX4806 ("primary unit of binding component is not an entity" - it resolves
   to the package), and mixed-language port matching is CASE SENSITIVE, so
   `extReset`/`enPhi1`/`iEdb` all fail with EX4968. Fix:
   `src/rtl/FX68K/fx68k_lc.sv`, a lower-case-port wrapper reached by direct
   entity instantiation.

   PROBE GOTCHA worth remembering: the first probe reported a comfortable 95
   because the family-select signal was `game_id[3]`, which synthesis proved
   constant 0 (the OSD only assigns loaded_slot[2:0]) - it killed MCR-2's
   video path and pruned 27 of its 34 blocks. Any future probe must select on
   something provably non-constant (a physical input).

   **4c. CPU/sound ROM in SDRAM — TRIED 2026-07-27, PARTIAL RESULT.**
   The two biggest BSRAM consumers are the shared 64 KB CPU ROM (32 blocks)
   and 16 KB sound ROM (8). `sdram_gw` already has three CPU READ ports
   (cpu1/cpu2/cpu3) on banks 0,1 - a different bank group from the sprite
   port on banks 2,3, so no contention - and every top had them tied to
   zero. Upstream MiSTer's Arcade-MCR3 runs CPU+sound from SDRAM this way.
   Wiring it up took 114 -> **74 blocks**, i.e. 44 spare, which would fit
   MCR3Scroll (~16 incl. FX68K) and MCR-1 (~13) with room over.
   RESULT:
   - **CPU ROM in SDRAM FAILS.** Colour bars, no game - the Z80 is running
     on stale data. Matches the timing sum: the controller needs ~7 clk_sys
     worst case (up to a 7-cycle clk_sdram round to launch plus 7 to commit,
     and clk_sdram is 2x clk_sys), and the main Z80 has cpu_ena every 8
     clk_sys, ~16 across a T1->T3 read. Too little margin, and the port1
     group round-robins between port1/cpu1/cpu2/cpu3 so a port can wait
     extra rounds.
   - **Sound ROM in SDRAM: VERIFIED ON HARDWARE 2026-07-30.** Kick and
     Kickman are SSIO-ONLY (no Cheap Squeak Deluxe) and both have sound in
     the merged 15-game core, so the shared 16 KB sound ROM read from SDRAM
     on the `cpu3` port works. Its Z80 runs at 2 MHz (mcr_sound_board divides
     clk_sys by 20), ~3x the main CPU's margin, which is why this succeeds
     where the CPU-ROM move failed. **Worth 8 blocks, and those 8 blocks are
     what made the 15-game merge fit.** `SND_IN_SDRAM` stays 1.
     (The earlier inconclusive attempt compared against TIMBER, which has its
     own boot-load bug - that comparison proved nothing either way.)
   Experiment reverted; it lives in git history (both moves were behind
   independent `CPU_ROM_IN_SDRAM` / `SND_ROM_IN_SDRAM` switches so either
   can be re-enabled). If the CPU ROM is ever wanted in SDRAM it needs real
   latency hiding - a prefetch or a small cache - not just wiring.
   NOTE: this experiment also confirmed **Timber's boot-load corruption is
   still present in the MERGED core** - the merge did not fix it.

   **4b. Multiboot mechanics — DECODED and partly VERIFIED on this
   toolchain (keep for Scroll/Mono).** The 2026-07-24 investigation's notes
   were never actually committed (1b25a33 staged only RTL), so they are
   recorded here properly:
   - `//MultiBootMode: Single` in the .fs header is the SPI **bus width**
     (Single/Fast/Dual/Quad), NOT a "multiboot off" flag. The old worry
     about it was a red herring.
   - The jump pointer is `set_option -multiboot_spi_flash_address <hex>`
     (plus `-multiboot_address_width 24`). **VERIFIED 2026-07-27**: 300000
     vs 600000 produce DIFFERENT bitstream bodies, so the address really is
     encoded. Pass the value WITHOUT a `0x` prefix — `0x300000` yields a
     cosmetic `//MultiBootSPIAddr: 0x0x300000` (same bits, ugly header).
     `-mspi_jump` / `-mspijump_spi_flash_address` are the sibling options.
   - GW5A (Arora V) has **no fabric GOCONFIG/HOTBOOT primitive**; reload is
     triggered by the dedicated **RECONFIG_N** pin.
   - **RECONFIG_N routing — ANSWERED 2026-07-27** (was the open hardware
     question): dock schematic sheet 19/17 (`FPGA_CFG`, rev A and rev C) —
     `RECONFIG_N` is SOM connector J0 pin 61 = SOM ball **N12**
     (`BANK3_N12_IOR9B`), pulled up on the SOM, and grounded by **SW2**
     (`RECFG_KEY`, a 6x6 mm tact switch on the dock) through C9 10 nF with
     D1 for ESD. So the net exists and a spare GPIO can be jumpered to it;
     the FPGA cannot drive it directly because it is a dedicated config pin.
   - Cost that killed it for this product: each hop is a FULL
     reconfiguration — 2.51 MB at the default 2.5 MHz single-lane SPI is
     ~8 s, and the device always starts at flash address 0, so a ring walk
     happens on EVERY cold boot, not just when switching (a cabinet set to
     the 3rd core pays ~24 s per power-on). `-multiboot_mode Quad` might cut
     that ~4x (untested). `-loading_rate` rejected every value tried
     (100/50/30/20/10.0/5.0) on GW5AT-60 — accepted set unknown.
   - Flash budget: 16 MB (JEDEC 0B 40 18), 2.51 MB per .bin -> five 3 MB
     slots. Design in docs/sd_card_layout_v2.md ("cores in flash, ROMs on
     SD" — option 1).

5. **Persist the chosen core across power cycles.** GROUNDWORK IN
   2026-07-24: prefs sector byte 9 now records the running FAMILY on every
   save, and the loader reads it back (pref_core) - wired and building,
   unused until item 4 provides the jump mechanism. Remaining: Extend the existing
   MCRPREF sector (2047 — today it stores the last game slot within a
   family) with a CORE/family id. Every core checks the pref early at boot:
   if it isn't the saved core, multiboot-jump to the right flash slot; else
   boot normally into the saved game. Cabinet comes up exactly where the
   owner left it.

6. **Cabinet-button core/game switching, consistent across ALL games.**
   GROUNDWORK IN 2026-07-24: hold the physical coin key (AB13) ~3 s to open
   the OSD - implemented identically in all three family tops + osd.sv
   (btn_menu_hold). On the shield this signal moves to the 74HC165 Service
   line (no credit side-effect). Untested on hardware. Remaining:
   USB Select+Start stays, but a real cabinet needs the ORIGINAL controls to
   open the menu. The chord must use inputs that exist on EVERY MCR harness
   regardless of game — per docs/mcr_game_input_matrix.md the safe universal
   set is the coin-door group (Coin 1 + Service/Test switches), NOT player
   panel buttons (those vary per game). Proposal: long-hold Service (or
   Service+Coin1) -> OSD opens; navigation via a fixed pair present
   everywhere (P1 Start / Coin buttons). Wire through the shield's 74HC165
   chain (docs/shield_j10_pinout.md); must behave identically in all six+
   input maps so muscle memory transfers between games.

---

## Scaler plan — docs first, port second (2026-07-28)

Two documents now capture everything, so neither path restarts from zero:
  * `docs/ascal_port_notes.md` - all ascal knowledge: architecture, our
    integration, the exact fault, the ten eliminated hypotheses, the confirmed
    sim-vs-hardware divergences, the four GowinSynthesis defects, and a staged
    Verilog port plan with a TRIPWIRE (port to nearest-neighbour only and test
    on hardware BEFORE writing any interpolator).
  * `docs/scaler_features.md` - the fallback/parallel track: triple buffering,
    burst reads into a ping-pong line buffer, input auto-detect, and
    parameterised output timing, specified against our own working scalers.

`src/video/ascal_v.sv` - hand Verilog port, nearest-neighbour. Interface
matches ascal_gw.vhd so it drops into ascal_test60k and sim/vsynth unchanged.
Key simplification: 16 bpp so 8 pixels fit a 128-bit word exactly and a line
is a whole number of words - which removes ascal's o_off/o_pshift/sSHIFT
burst-offset machinery entirely, and that machinery is where its SECOND,
carry-independent `o_hacpt` increment lives. Triple buffering built in AND
ENABLED (`.triple_buf(1'b1)`).

**TRIPWIRE PASSED 2026-07-28 — it renders a correct picture on hardware,
which ascal itself never did.** Capture-card measured: active window
x=160..1119 (960 px), 8 colour bars of 118-122 px (expect 120), six equal
vertical bands of ~120 lines, all six pattern bands correct. Build is clean:
~4.3k registers, 28/118 BSRAM, no undeclared symbols, no setup/hold
violations, only the accepted `gowin_pll_hdmi` PA1019.
Full bring-up log (six bugs, in the order they bit) in
`docs/ascal_port_notes.md` §6. Two of them are worth repeating here because
they are methodology, not RTL:
  * a weak checker passed a broken design for several iterations - an
    under-run line buffer returns STALE data, and on a repetitive test
    pattern stale data still measures as plausible colour bars.
    `tools/scaler_check.py` now validates a whole frame.
  * the DDR3 sim model was too kind (fixed 12-cycle latency), so the reader
    always won a race it loses on silicon. Stalls added, `STALL` parameter -
    **and even so neither model configuration reproduced the fault.** The old
    design still passes under stalls; cranking the stall to 250 starves the
    WRITE path and the frame just goes black. What settled it was an on-chip
    tap read over UART, exactly as with ascal itself. Simulation guided the
    fix; it did not prove it.

### Is ascal_v ready to replace `ddr3_framebuffer`? Not yet (assessed 2026-07-28)

The trade is NOT "ascal instead of triple buffering" - ascal_v has ALREADY
done the triple buffering, and `ddr3_framebuffer` has no buffering concept at
all (grep finds no buffer/base-address logic; it is single-buffered). So
`scaler_features.md` §1 would be ~50 lines of work thrown away if ascal_v
clears its gate. **HOLD the ddr3_framebuffer triple-buffering work as the
fallback; do not start it.**

Against promoting ascal_v today: hours old, has rendered exactly one test
pattern, never run a game core, audio entirely unproven, three open defects.
`ddr3_framebuffer` is what the merged 9-game core runs on, verified across
the whole roster. For it long-term: triple buffering, input auto-detect,
parameterised output timing, and full-line burst reads instead of the
4-pixel prefetch that §2 already fingers as the likely artifact source.

**Open symptom: HDMI looks more stable than the old path but SHIMMERS, with
a vertical wobble/jump every so many frames.** Ranked suspects:
  1. **Unsynchronised multi-bit CDC on the geometry.** `o_iw`/`o_ih` are
     latched from `i_hdmax`/`i_vdmax` (input clock domain) by one `o_clk`
     edge at `ocx==0 && ocy==0`, no handshake. `line_words` is derived from
     `o_iw`, so a glitched sample corrupts the stride for that frame. How
     often depends on the beat between the clocks - "every so many frames".
     NOTE the probability argument cuts against this: if i_hdmax only
     updates once per source frame, the coincidence window is ~1e-6/frame,
     i.e. hours, not seconds. **Verify what actually drives i_hdmax before
     believing this.**
  2. **60.09 Hz source vs 60.00 Hz output** - a ~0.09 Hz beat repeats or
     drops a frame every ~11 s. Triple buffering removes the TEAR but cannot
     remove this judder; only genlocking output to source can.
  3. **Nearest-neighbour at 1.5x** - 480->720 maps lines 1,2,1,2..., so any
     motion crawls. Inherent; this is what bilinear/polyphase exists to fix
     and it is the part NOT ported.

### Promotion gate - do in order

  * **A1. DONE 2026-07-28 - both CDC suspects ELIMINATED by measurement.**
    Three sticky saturating counters added to `ascal_v` (`dbg_cdc`) and read
    over UART for 95 s (~5700 frames), build marker D:
    | counter | reading | meaning |
    |---|---|---|
    | `cdc_fly` | **0** | buffer index never sampled mid-change |
    | `cdc_bad` | **0** | never an invalid index (>2) |
    | `cdc_geo` | **2**, not growing | exactly the power-on transient |
    Suspect 1 was doubly wrong. First, `i_hdmax`/`i_vdmax` are written the
    SAME value every vsync (511/479) with a stable source, so those registers
    never transition and the crossing is inert - `cdc_geo`'s 2 counts are just
    `o_iw` initialising 512 -> 1 -> 512 at power-on.
    Second, the replacement theory - incoherent multi-bit sampling of
    `latest` (which rotates 0->1->2, and 1->2 flips BOTH bits, so a 2FF sync
    stops metastability per bit but not incoherence across bits) - is real but
    far too RARE. The beat phase advances ~2475 cycles per frame while the
    hazard window is ONE cycle out of 1.65M, so it steps over the hazard
    almost every time: expect ~1 hit per 8 minutes, not one per few seconds.
    **Still worth fixing for robustness** (cross a single-bit toggle and
    capture the stable data on the synced edge); the same flaw exists in the
    OTHER direction on `rd_buf` -> `rdbuf_a2`, where an incoherent sample
    makes `free_buf` wrong and the writer could pick the buffer being read.
    But it is NOT the wobble. Retitled as A2b below.
  * **A2. Wobble suspects, revised after A1.** Leading candidate is now
    **frame-start write alignment**: `wr_ptr` resets at `a_frame_start`, and
    any words still in the write FIFO from the previous frame then land at the
    TOP of the new buffer, shifting the whole image by a sub-line offset that
    varies frame to frame - which would read as exactly "shimmer plus a
    vertical wobble every so many frames". The counting argument says leftover
    should be 0 (30720 words/frame, bursts of 8, 64 words/line), so this needs
    MEASURING not assuming: add a per-frame written-word counter and flag any
    frame != 30720. Then re-test suspects 2 (60.09 vs 60.00 beat) and 3
    (nearest-neighbour 1.5x line crawl), which remain live and are inherent
    rather than bugs.
  * **A2 UPDATE 2026-07-28 - shimmer QUANTIFIED, two theories killed.**
    90 raw (yuyv, not mjpeg) frames captured off the card and compared:
    | measurement | result |
    |---|---|
    | band-boundary y over 90 frames | **121 / 122 / 123** - moves 1-2 px |
    | left-border x over 90 frames | **160 in every good frame** - stable |
    | consecutive pixel-identical pairs | 6/89 (~8% of pixels change) |
    | highest-variance rows | 252, 297 (h-stripe band), 495-531 (checker) |
    The shimmer is **purely VERTICAL**. Horizontal never moves, and the bands
    that flicker are exactly the vertical-shift-sensitive ones (h-stripes,
    checkerboard) while the VERTICAL-stripe band is steady. A sub-line offset
    would smear horizontally too; a whole-line offset moves only vertically.
    This KILLS suspects 2 and 3 as the cause: nearest-neighbour mapping is
    deterministic per frame (the vertical Bresenham resets at ocy==VTOTAL-1),
    and repeating/dropping a frame of a STATIC pattern changes nothing.
    **The write-alignment fix (deferred buffer switch + short end-of-frame
    burst, `frame_pend`/`drain_cnt`) made NO measurable difference** - the
    distribution is unchanged. Kept anyway (it is correct, lint/sim clean, and
    removes a real residue path) but it is NOT the cause.
    **NEW LEADING THEORY: three buffers <-> three discrete vertical positions.**
    Each triple-buffer slot appears to hold the image at a slightly different
    vertical offset, so the picture jumps as `rd_buf` rotates 0->1->2.
    **Experiment RUN (marker F, `.triple_buf(1'b0)`) - PARTIALLY confirms:**
    | config | band-edge positions | spread |
    |---|---|---|
    | triple (E) | 121x60, 122x20, **123x3** | 2 px |
    | single (F) | 121x64, 122x19 | **1 px** |
    The THIRD position disappears with one buffer, so the triple-buffer slots
    ARE misaligned relative to each other - a real bug, worth fixing (suspect
    the per-buffer base address or a per-buffer write-start offset). But the
    dominant 121/122 jitter SURVIVES single-buffering, so that part is not
    buffer-related. Note single-buffering also introduces tearing, so the two
    configs are not perfectly comparable.
    **CONTROL RUN 2026-07-28 - the instrument is FINE and the fault is OURS:**
    | build | band-edge | spread | med changed px/pair |
    |---|---|---|---|
    | ascal_v triple (E) | 121x60, 122x20, 123x3 | 2 px | 72298 |
    | ascal_v single (F) | 121x64, 122x19 | 1 px | 53233 |
    | **ddr3_framebuffer (DD)** | **120x83** | **0 px** | **22091** |
    The capture card resolves vertical position EXACTLY on the known-good
    path, so the 7/90 detection failures are a benign capture artifact and
    the jitter is real. ascal_v also churns 2.4-3.3x more pixels per pair.

    **IT IS NOT A SHIFT.** Diffing a y=121 frame against a y=122 frame:
    shifting by +-1 row makes them match WORSE (15.0% / 17.7% differing) than
    shift 0 (9.3%), and only **70 of 720 rows differ**, scattered as isolated
    single/double rows clustered in the high-detail bands. The picture does
    not move - **individual output LINES are sporadically wrong.**

    **`dbg_underrun` was TRUTHFUL; dismissing it as "a lying instrument" was
    wrong.** It reads F (saturated, >=15/frame) because lines really do
    starve. Making the swap unconditional (to break the A2 deadlock) turned a
    late prefetch from a hang into a wrong line.

    **ROOT CAUSE FOUND: the one-line lookahead was worth ZERO cycles.** The
    lookahead advance and the prefetch issue are in two separate always
    blocks that BOTH fire at `ocx == 0`. With non-blocking assignment the
    prefetch read the PRE-update `sy_a` - the line needed by the line being
    displayed right now, not the next one. So the intended full-line lead
    collapsed back to the 160 px pillarbox: the exact race A2 was supposed to
    have fixed, reintroduced by scheduling rather than by addressing.
    FIX APPLIED: expose the next value as a wire (`sy_a_nxt`, with `vstep_a`
    /`in_vwin`) so both blocks see the same view, and prefetch on that.
    Lints clean, sim still passes (79 good bar rows, 0 bad), builds clean.
    **VERIFIED ON HARDWARE (marker 7) - THE LOOKAHEAD FIX DID NOT WORK.**
    It corrected the band edge to 120 (matching the control, so it did fix the
    A3 off-by-one as a side effect) but the corruption is unchanged: 59
    differing rows/pair vs 55 before, and underruns still read F.

    **BEST METRIC FOUND - adjacent-row duplication in the 1px h-stripe band.**
    Clean 480->720 nearest-neighbour must give ~0.333; excess duplication is
    lines repeating because their prefetch never landed:
    | build | duplicate rate |
    |---|---|
    | ddr3_framebuffer control | **0.385** (near-ideal) |
    | ascal_v before (E) | 0.551 |
    | ascal_v after lookahead fix (7) | 0.586 |
    ~17% of lines are EXTRA duplicates. **Starvation is real and quantified.**
    Use this metric, not band-edge position - the "vertical wobble" reading was
    an artifact of a starved line landing on the band boundary. The picture
    never moves: diffing two frames, shift 0 matches best (9.3%) and +-1 row
    matches WORSE (15.0%/17.7%).

    **The bridge is NOT the bottleneck.** `ascal_avl_ddr3.sv` issues read
    commands back-to-back (`rd_go = state==ST_READ && app_rdy`, one per
    cycle), so 64 words should land in ~80 cycles of the 1650 available.
    So the deadline is met on paper yet missed in practice - the next step is
    to MEASURE the actual fetch latency on chip (a cycle counter from rq_tog
    to rd_done, max-latched onto the beacon) rather than reason about it.

    **ROOT CAUSE FOUND AND FIXED IN SIM 2026-07-28 - it was the FETCH GATE.**

    First, the test bench was testing the wrong design: `sim/vsynth/av_top.v`
    ran a **640x480** output with `vmax=479`, i.e. **1:1 vertical scaling**,
    while hardware is 720p with `vmax=719`, i.e. **1.5x**. The line-repeat
    path, the 1650-cycle line timing and the 960-wide window were NEVER
    simulated. That is why the sim passed a design that starved on hardware.
    Fixed: av_top now uses HTOTAL=1650/VTOTAL=750/HDISP=1280/VDISP=720,
    hmin=160 hmax=1119 vmax=719, and DUMP_LINES=720 (DUMP_FRAME lowered to 8
    - a 720p frame is 1.24M cycles, 3x the old raster, and 24 frames times
    out). **With that geometry the sim REPRODUCES the fault**: h-stripe
    duplication 0.544 vs hardware 0.586. Iterate here, not on the board.

    **Best diagnostic: run-length histogram of identical adjacent rows** in
    the 1px h-stripe band. At 1.5x every run must be 1 or 2. Observed:
    `[(1,16), (2,26), (4,10), (7,1)]` - runs of **4**, and no 3s. A 4 is two
    2-runs merged: one source line is skipped entirely and its predecessor
    covers both slots. Only 53 of 76 expected source lines appeared.

    **The bug:**
    ```
    if (!swap_req || !rd_busy) begin      // swap_req is the PRE-update value
    ```
    Right after a swap `swap_req` is still 1, so `!swap_req` is 0 and the gate
    collapses to `!rd_busy`. Whenever the previous fetch's completion toggle
    had not cleared, the NEXT line's fetch was never issued - so that source
    line was skipped. ~19% of line transitions. Removing the gate gives
    **duprate 0.333 exactly, runs = only 1s and 2s (39 ones, 38 twos)** -
    better than the ddr3_framebuffer control's 0.385 - with colour bars at
    exactly 120 px and all six bands correct.

    **CONFIRMED ON HARDWARE 2026-07-28 (marker 9) - ascal_v now MATCHES the
    control exactly.**
    | build | dup rate | run lengths | differing rows/pair |
    |---|---|---|---|
    | ddr3_framebuffer control | 0.385 | 1s and 2s only | 0/720 |
    | ascal_v before | 0.551 | 1s, 2s, **804 fours, 23 sevens** | 55/720 |
    | **ascal_v fixed** | **0.385** | **1s and 2s only** | **1/720** |
    Run-length distribution is now identical to the control (3237 ones, 3154
    twos, zero 4s). Beacon confirms the mechanism: **481 fetches/frame**
    (expect 480, was ~390) and **96-cycle worst fetch latency** against the
    1650-cycle line budget - 6% utilisation, so latency was never the issue
    and an unguarded fetch issue is safe by a wide margin.
    (The 0.385-vs-0.333 gap between hardware and sim is the capture path -
    the control reads 0.385 too, so 0.385 is what a perfect result looks
    like through this card.)

    **RESIDUAL AFTER THE GATE FIX (marker 9) - two SEPARATE faults, do not
    conflate them again (I did, for hours):**

    **(i) PLATFORM SYNC LOSS - NOT the scaler.** Black-frame rate is
    IDENTICAL across all three builds: ddr3_framebuffer control **7/90 (8%)**,
    ascal_v before **7/90**, ascal_v after **7/90**. The known-good
    framebuffer drops sync at exactly the same rate, so this lives in the
    HDMI/TMDS path downstream of both scalers. **This is what makes the DDR3
    path unusable, and fixing ascal_v cannot fix it.** It is roadmap item 1
    and deserves its own attack - it matters more than the residual below.

    **(ii) ascal_v line-selection jitter at content transitions.** Excluding
    black frames:
    | build | clean pairs | med wrong rows | band-edge |
    |---|---|---|---|
    | ddr3 control | **82/82** | 0 | 120 always |
    | ascal_v triple | 35/82 | 1 (p90 4) | 120x80, 122x3 |
    | ascal_v single | 25/82 | 2 (p90 5) | 120x81, 122x2 |
    **Single buffering is WORSE, so per-buffer misalignment is NOT the cause**
    - the earlier "3 buffers <-> 3 positions" theory is dead. Keep triple.
    Only **37 distinct rows** ever fail; 21 are within 3 of a band boundary
    (120/240/360/480/600) and account for 92/142 hits, the rest cluster at the
    top border (rows 2-6). Each fails in ~7% of frames. A wrong line is only
    VISIBLE where adjacent source lines differ, so this is an occasional
    off-by-one in WHICH line is displayed at a transition - the h-stripe band
    run-lengths are otherwise perfect (1s and 2s only).
    Beacon is steady through all of it: **x01E1 = 481 fetches/frame**,
    **q0C-0D = 96-104 cycle worst latency** vs a 1650-cycle budget, no spikes.
    So every fetch IS issued and memory IS fast - this is not starvation.
    **Lead suspect: the first output line of each frame.** At `ocy==0` the
    code forces `nsy = 12'hFFF` and fetches `sy_a_nxt` (the line for ocy==1),
    so output line 0 displays whatever was already in the buffer and source
    line 0 is never fetched for it. That is an off-by-one at frame top, and
    it fits the row 2-6 cluster. NEXT: dump 3+ consecutive frames from the
    720p sim (it reproduces now) and check whether the band edge jitters
    there - debug with full internal visibility rather than on the board.

    **SIM NOW REPRODUCES THE RESIDUAL DEFECT - debug here, not on the board.**
    Two changes made it usable: `mcr_testpattern` got a `FREEZE_BAR`
    parameter (default 0, hardware unaffected) because a per-line signature
    comparison is useless when an animated overlay touches every line every
    frame; and the harness now dumps a **per-line FNV-1a hash** for 20 frames
    plus `dbg_sy` (source line displayed) instead of pixels - 24 full frames
    of pixels is ~22M lines of text. Also: the old 200 ms sim-time cap only
    allowed ~12 frames (raised to 700 ms), and ASAN is not needed (the old
    constructor segfault does not occur in this harness) - `-O2` is ~5x faster.

    Findings, all from simulation with a STATIC source:
    * Most frames are **bit-identical**; 12 of 20 frames carry 1-6 wrong
      lines. Deterministic, so a glitch frame can be re-dumped at will.
    * **`dbg_sy` is CORRECT on every glitching line** (`sy == ideal`
      everywhere; the only deviation is row 0, which is the deliberate
      `nsy=12'hFFF` frame-start force). **So the addressing/Bresenham is
      RIGHT and the DATA is stale** - do not go looking at sy again.
    * The stale content is an EARLIER SOURCE LINE, not the previous frame:
      at rows 120/121/123/124 the pixels are all-white (colour-bar band,
      ~line 79) where the vertical-stripe pattern belongs. With a static
      source, previous-frame staleness would be invisible - so this is
      line-level, not frame-level.
    * **Buffer parity is the pattern.** Rows 120,121 (line 80) and 123,124
      (line 82) are stale; row 122 (line 81) is fine. Lines 80 and 82 both
      live in ping-pong half Y, line 81 in half X. **The fetches targeting Y
      did not land; X was always correct.** Same shape at every other
      cluster (360/361/363/364, 240/241/242/245, 3/4/6/7).
    * Note `avl_clk == o_clk` in the sim harness, so this is NOT a CDC race -
      it is deterministic logic.

    **A4 SETTLED: `dbg_underrun` is measuring nothing - DELETE IT.** Measured
    78-410 underruns per frame against ~480 fetches, with ZERO correlation to
    glitches (frame 7: und=410, 0 wrong lines; frame 18: und=78, 1 wrong
    line). The toggle-based `rd_busy` is not a valid completion signal.
    Replace with a word-count completion (count `avl_readdatavalid` against
    `rq_len_l`) before relying on any guard that uses it.

    **ROUND 2 - four integrity checks ALL PASS, so the fault is PHASE, not data:**
    * **Write path clean.** ddr3_model now asserts that with a STATIC source a
      location is never rewritten with a different value: 600k+ writes,
      **0 mismatches**. DDR3 holds correct data at correct addresses.
    * **No short fetches.** Every fetch delivers exactly `rq_len` (64) words
      into its half - counter `short_cnt` = 0 across 20 frames.
    * **No fill/display collisions.** A fill never targets the half currently
      displayed - counter `collide_cnt` = 0.
    * **All fetches issued** (481/frame) and worst latency 96 cycles of 1650.

    **THE ACTUAL MECHANISM: the fetch/display schedule is NOT frame-invariant.**
    Traced with `+define+ASCALV_TRACE` (guarded, off by default):
    ```
    frame A:  issue ocy=116 sy_nxt=77 ... swap ocy=117 sy_have=77
    frame B:  issue ocy=115 sy_nxt=77 ... swap ocy=116 sy_have=77
    ```
    Same source line, but frame B runs the whole schedule ONE OUTPUT LINE
    ahead of frame A. Addresses are right in both (4928 / 136000 / 70464 =
    line 77 at buffer bases 0 / 65536 / 131072, so triple buffering rotates
    correctly). What drifts is the PHASE of the ping-pong relative to the
    raster - which is why a given line is stale in one frame and fine in the
    next, and why glitches cluster by buffer parity.

    **FRAME-START THEORY REFUTED BY EXPERIMENT 2026-07-28.** A deterministic
    frame start WAS implemented (at `ocy==VTOTAL-1`: set `rd_buf<=nrd`,
    `disp_buf<=1`, fetch source line 0 into half 0, `swap_req<=1`,
    `sy_have<=12'hFFF`; the old `ocy==0` forced-`nsy` refetch removed). Proved
    to execute (25 times, once per frame, rd_buf rotating 0->2->1). **The
    glitches are byte-identical: same 12 frames, same rows.** So frame-start
    phase is NOT the cause. The change is KEPT anyway - it is correct, it puts
    source line 0 on output line 0 (it previously landed on line 1), and it
    makes the line-0 fetch use the NEW rd_buf instead of the pre-update one.
    Note `sy` deviations from ideal are now **0** including row 0.

    **Where that leaves it - every per-fetch invariant holds, yet data is
    stale.** Verified simultaneously: DDR3 content correct, address correct,
    fetch issued, exactly 64 words delivered, target half never the displayed
    one, sy == ideal. If all of those are true the displayed half MUST hold
    the right line - so one of the checks is not measuring what it claims, or
    the staleness enters between the fill and the read. Next things to try,
    cheapest first: (a) log the actual 64 words of a fetch for a known glitch
    line and compare against DDR3 contents at that address - this
    distinguishes "wrong data fetched" from "right data, wrong half read";
    (b) check the `linebuf` read pipeline across the swap (`lb_word`/`px_sel`
    are registered, so the half select is sampled a cycle before use);
    (c) widen the ping-pong to 4 slots so a late or misrouted fill cannot
    alias onto the half about to be displayed.

    **Bridge protocol hazard CHECKED and refuted.** `avl_waitrequest` in
    `ascal_avl_ddr3.sv` is `!(wr_go || (rd_go && beat==0))`, i.e. it goes LOW
    on WRITE beats - so a master sitting in its read state could read that as
    "read accepted", drop the request, and leave the half stale. Instrumented
    the bridge (`+define+ASCALV_TRACE`): **read-while-writing = 0**. It cannot
    happen here because ascal_v only enters `A_RD` from `A_IDLE`, and it would
    have been stalled in `A_WR` if the bridge were mid-write. Reads started
    tracks the expected ~481/frame. **Still worth hardening** - the waitrequest
    encoding is a latent trap for any future master that pipelines.

    (superseded) Suspected cause - frame-start state is never reset. At `ocy==0` the
    code forces `nsy = 12'hFFF`, but a fetch for line 0 has usually ALREADY
    been issued at `ocy==VTOTAL-1` (sy_a_nxt=0 vs the last line's sy) and
    swapped in. The forced value makes line 0 fetch a SECOND time,
    redundantly, and that extra fetch flips the ping-pong parity. Whether it
    happens depends on carry-over state - `swap_req`, `disp_buf`, `sy_have`,
    `sy_fill` are NOT reset at frame start - so the phase can differ frame to
    frame. **FIX DIRECTION: reset the whole line-buffer state machine
    deterministically at frame start** (or stop forcing `nsy` and let the
    normal comparison run), so every frame begins from an identical phase.

    (superseded) NEXT: count fetches ISSUED vs read COMPLETIONS in sim, per ping-pong
    half, and assert that a half is fully written before it is displayed.
    Also fix (separately, currently invisible with a static source because
    the buffers hold identical content): at `ocy==0` the fetch uses
    `base_of(rd_buf)` with the PRE-update `rd_buf`, so the first fetch of
    each frame reads the previous frame's buffer.

    **STILL OPEN (A4): `rd_busy` is unreliable.** The gate only misfired
    because the completion toggle was still set 1650 cycles after issue. With
    the gate gone this no longer affects the picture, but `dbg_underrun`
    remains meaningless until it is fixed, and issuing a fetch is now
    UNGUARDED - safe at one fetch per 1650-cycle line against ~80-cycle
    reads, but it should be given a correct guard rather than none.

    (superseded) Structural fix if latency turns out to be jittery: the control has no
    per-line deadline at all - `ddr3_framebuffer` streams with a 32-entry
    prefetch buffer and PREFETCH_DELAY=44. ascal_v's per-line burst gives it a
    hard deadline every line. Deepening to 4 line-buffer slots and prefetching
    2 lines ahead would double the budget and absorb jitter.

    **Wrong theories this session, recorded so they are not retried:**
    geometry CDC (values are constant); triple-buffer index CDC (real but ~1
    hit per 8 min, far too rare); frame-start write alignment (fix made no
    measurable difference); the capture card (control proves it resolves
    position exactly, spread 0px). Also: `dbg_underrun` was TRUTHFUL - calling
    it a lying instrument was wrong, and cost time.

    (superseded) INSTRUMENT SUSPICION: exactly 7 of 90 frames fail detection
    in all captures (before the write fix, after it, and single-buffered) -
    a constant that survives unrelated RTL changes belongs to the measuring
    apparatus, not the design. **NEXT: run the identical 90-frame measurement
    against a `video_test60k/ddr3_top` build as a CONTROL.** If the known-good
    production framebuffer shows the same 121/122 split and the same 7/90,
    the capture card cannot resolve 1 px of vertical position and this whole
    line of measurement needs a different instrument (e.g. photograph the
    monitor, or compare a long-exposure capture). Only if the control is
    CLEAN is the residual jitter real and ours.
  * A2b. Fix both multi-bit CDCs (toggle + stable data), robustness.
  * **A5 SCOPED: MiSTer's audio system is NOT transplantable.** `sys_top.v`
    drives HDMI_TX_D[23:0]+HS/VS/DE/CLK and HDMI_I2S into an **external
    ADV7513 transmitter**; `sys/i2s.v` is a ~40-line serialiser and there is
    NO data-island, ACR, CTS or audio-sample-packet logic anywhere in
    `sys/` - the ADV7513 does all of it in silicon. We generate TMDS
    ourselves via OSER10, so hdl-util/hdmi (already vendored, already
    carrying audio for all nine shipping games) is the only real option.
    Remaining work is the raster-ownership swap: `hdmi.sv` is the timing
    MASTER (cx/cy are outputs), while `ascal_v` generates its own raster, so
    ascal_v needs external-raster inputs driven from cx/cy. Use the INTEGER
    `AUDIO_CLK_DELAY = 74250*1000/AUDIO_RATE/2` divider from
    ddr3_framebuffer - a fractional-exact one made dropouts WORSE (roadmap
    item 1) and a declared-vs-actual mismatch was the original 50% rate lie.
  * A3. Fix the `vmax` off-by-one - the bottom white border is missing
    (top/left/right render). Static, not a wobble source.
  * A4. Fix or remove `dbg_underrun`: it reads F (>=15/frame) while the
    picture is correct, so it is lying. A lying instrument is worse than
    none. Suspect the read-completion toggle, not real starvation.
  * A5. **Add the 1 kHz sine + `tools/audio_dropout_check.py` to the ascal
    rig** (it has HDMI audio clock plumbing but no tone and no measurement).
    Gate: match BRAM's 0 lost cycles in 15 s, or at least DDR3's 1.
  * A6. Run a REAL core (MCR-2 Domino) through it, not a test pattern.
  * A7. Soak-test a FLASHED build - also settles the production-reboot
    question below.
  * Only if promoted: bilinear / sharp-bilinear (suspect 3's real fix, and
    where CK3001 and the DSPs live - this is the risky part of the port).

**Production-reboot question (asked 2026-07-28).** Needing frequent reboots
during this session is most likely a DEVELOPMENT artifact: each
`openFPGALoader` SRAM load restarts five PLLs and the DDR3 controller
mid-flight, dozens of times per session, whereas production configures once
from SPI flash and stays up. The chip is cool to the touch (not thermal) and
the FT2232 re-enumerated mid-session, pointing at USB/reset. **This is a
hypothesis, not a result** - A7 is what would actually settle it. Note it
also lines up with the "a RECONFIG recovers it" lead in roadmap item 1.

## STATUS 2026-07-29 — read this first

### ascal_v IN THE MCR-3 CORE — IT FITS (2026-07-29)
`src/video/ascal_fb.sv` is a **drop-in replacement for `ddr3_framebuffer`**
built on ascal_v: same port list plus two extra inputs (`i_ce`, `i_de`),
because ascal_v needs the pixel tick and the active-video LEVEL separately -
`fb_we` is their AND and drops between pixels, which would look like one line
per pixel to the input capture. Swapping a core is a module-name change plus
two wires (`pixel_tick`, `cap_active` already exist in the MCR tops).

**Builds clean in `mcr3_console60k`** - no errors, PA1019 absent, no
undeclared symbols:
| resource | ddr3_framebuffer | ascal_fb | delta |
|---|---|---|---|
| Logic | 13338 | 13590 | +252 |
| Registers | 8613 | 8688 | +75 |
| CLS | 9893 | 10096 | +203 |
| **BSRAM** | **88/118** | **98/118 (84%)** | **+10** |
| DSP | 1 | 2 | +1 |
**20 BSRAM blocks to spare.** (The merged 9-game core at 114/118 would NOT
fit - 124 needed. Halving `MAX_WIDTH` reclaims nothing: Gowin allocates BSRAM
by WIDTH, and both the line buffer and write FIFO are 128 bits. Narrowing
`N_DW` to 64 is the lever if those blocks are ever needed.)

**RUNNING — TAPPER RENDERS CORRECTLY THROUGH ascal_v (2026-07-29).** Clean
colours, sprites and text, no visible glitches. This is the first time ascal_v
has scaled REAL GAME CONTENT rather than the test pattern.

**Root cause of the calibration failure: ascal_v was not held in reset until
DDR3 finished training.** `ddr3_framebuffer` holds its own state machines in
reset via `ddr_rst`; my wrapper reset ascal_v on `rst_n` alone, so it started
issuing Avalon reads and writes DURING the training sequence and calibration
never completed. Fix:
```
.reset_n(rst_n & init_calib_complete & ~ddr_rst)
```
Measured: **6/6 loads calibrate**, matching the control's 8/8 (before the fix
it was 0/many). **Any future master on this DDR3 controller must stay quiet
until `init_calib_complete`** - the app interface is not tolerant of traffic
during training, and the symptom is silent (builds clean, times clean, video
path perfect, memory simply dead).

**Debugging note worth keeping:** the control and the ascal build share the
same top and therefore the SAME beacon format, so a silent SRAM load failure
is indistinguishable from a real result. Four "c0" readings that looked like
the control failing were actually leftover ascal bitstreams. **When A/B-ing
two builds of the same core, give them distinguishable beacon markers.**

(historical) NOT YET RUNNING: DDR3 does not calibrate (beacon stuck at `c0`, black
screen). The core itself runs - beacon counters advance and the format is
the mcr3 one (`d0D LBA`), so this is bring-up of the wrapper, not the scaler.
Already checked and matched against BOTH references
(`ddr3_framebuffer.v` and `ascalv_top.sv`): DDR3 controller `rst_n` tied to
`1'b1` (feeding the core reset in was wrong and was fixed), `pll_ddr3.reset`,
`pll_mDRP_intf.rst_n(1'b1)`, `syn_keep` on `clk_x1` ONLY (adding it to `hclk`
breaks the merge with the top's `fb_hclk` that the SDC constrains, giving
TA2003/TA2004).
**The VIDEO PATH IS PROVEN GOOD** - user reports HDMI SYNC with **grey
borders and a black window**. Grey is ascal_v's own pillarbox fill (`0x20`),
so its raster, the HDMI stack and the TMDS output are all working; black in
the window is the line buffer returning zeros because DDR3 never calibrates.
**Only the DDR3 link is broken.**

**Ruled out by experiment (do not repeat):**
  * `place_option` - already 2 in mcr3's build.tcl (CLAUDE.md's documented
    "builds clean, DDR3 never trains" cause).
  * DDR3 controller port wiring - diffed against `ddr3_framebuffer.v`
    lines 185-220, equivalent.
  * Controller `rst_n` - was wrongly fed the core reset; now `1'b1` like both
    references. Real bug, fixed, but not the cause.
  * `ddr3_framebuffer.v` left compiled alongside `ascal_fb` (it instantiates
    its own pll_ddr3/gowin_pll_hdmi/DDR3 IP) - removed from `build.tcl`.
    Correct hygiene, not the cause.
  * PLL exhaustion - PLLA reports 5/8.
  * `rw_check_on_ram` (mcr3 uses 1, the working ascal rig uses 0) - tried 0,
    no change; reverted.

**Still to try:** the ascal rig and this core differ mainly in DENSITY
(13.6k logic / 98 BSRAM vs 4.7k / 28), and the Gowin DDR3 IP is known to be
placement-sensitive. Suspect physical placement pressure rather than RTL -
try constraining/floorplanning the DDR3 IP, or build a cut-down mcr3 (one
game, no USB/SDRAM) to see whether calibration returns as density drops.
Also worth diffing `clk50_pll`/`clk27` net properties (global vs local
routing) between the two designs, since `clk_g` feeds calibration.

### SCALER BACKLOG (after the line-glitch fix)
**Cleanups (small, do first):**
  * **DELETE `dbg_underrun`** - it measured 78-410 hits/frame with zero
    correlation to real glitches; a lying instrument is worse than none.
  * Remove the `ASCALV_TRACE` scaffolding and the leftover debug counters
    (`cdc_*`, `short_cnt`, `collide_cnt`, fetch/latency) - they are compiled
    into the current numbers and cost logic.
  * Audio tone reads **982.6 Hz** instead of 1000 (-1.7%). The audio clock is
    right (32004 Hz), so suspect truncation in `sine_gen`'s phase increment.
    Cosmetic for a tone, but a systematic pitch error would carry into games.
**Validation not yet done:**
  * **Run a REAL game core through `ascal_v`** - it has only ever scaled the
    test pattern.
  * Soak-test a FLASHED (not SRAM) build; also settles the production-reboot
    question.
**Features:** see `docs/scaler_options.md` "Modes worth adding" - rotation for
ROT90 cabinets is the highest-value one for this project, then interpolation,
scanlines, integer scaling, aspect/overscan, 240p verification.

### *** ascal_v LINE GLITCH FIXED *** (marker 5)
Root cause was **two bugs in the Avalon handshake, not in the scaler logic**:

1. **`rd_pending` was a ONE-CYCLE PULSE treated as a LEVEL.**
   ```
   always @(posedge avl_clk) begin
       rq_s1 <= rq_tog; rq_s2 <= rq_s1;   // 2FF sync advances rq_s2 EVERY cycle
       ...
       A_RD: rq_s2 <= rq_s1;              // "consume"
   wire rd_pending = (rq_s1 != rq_s2);    // therefore true for ONE cycle only
   ```
   The synchroniser itself advances `rq_s2`, so a request was visible for a
   single cycle. **Any read issued while the FSM was not sitting in A_IDLE was
   silently dropped** - the line never arrived and the raster showed stale
   data. Fixed with a proper request LATCH (`rd_req`), set on the toggle edge
   and cleared on acceptance, with SET taking priority over CLEAR.
2. **`avl_waitrequest` was not transaction-specific.** It was
   `!(wr_go || (rd_go && beat==0))`, so it went low on WRITE beats too; a
   master sitting in its read state could mistake a write acceptance for its
   own read and consume a request the bridge never saw. Now
   `avl_read ? !(rd_go && beat==0) : avl_write ? !wr_go : 1'b1`.

**Measured on hardware, exclusive capture device:**
| metric | before (E) | after (5) |
|---|---|---|
| clean frame pairs | 94/292 | **342/342** |
| wrong rows per pair | median 2, p90 6 | **0** |
| band edge over 120 frames | 120/121/122 | **120 every frame** |
| h-stripe duplicate rate | 0.333 | 0.333 (ideal) |
Colour bars: 8, correct colours, 118-120 px. Picture verified LIVE (0
identical consecutive pairs - always check this, a frozen image also scores
0 wrong rows). **ascal_v now matches the shipping framebuffer's stability
while scaling better than it (0.333 vs 0.385).**

Both fixes are in `src/ascal/ascal_avl_ddr3.sv` and `src/video/ascal_v.sv`.
The 4-slot ring is NOT needed for this and was set aside (WIP at
`scratchpad/ascal_v.ring_wip`); the ping-pong is correct once requests stop
being dropped. Note the ring exposed the bug precisely because it issues reads
back-to-back - a good stress pattern to keep in mind.

### MERGED 9-GAME CORE REBUILT WITH THE PLL FIX — user-verified good
Rebuilt `mcr23_console60k` (PA1019 absent, no negative slack, no undeclared
symbols, 10684 registers / 18%, 114/118 BSRAM as documented) and SRAM-loaded it.
**User played Timber with HDMI audio and reported NO dropouts - "1000% better".**
That is the acceptance signal; take it over any number below.

**METHOD WARNING - `blackdetect` IS INVALID ON GAME CONTENT.** The soak
reported 22 intervals / 5.21% black, but games legitimately go dark (attract
transitions, level changes, dark scenes) and every OSD game switch reloads ROMs
and intentionally drops the raster. The test pattern was a valid subject
precisely because it never goes black. **For game cores, use the user's eyes or
a content-independent signal (e.g. TMDS lock, or a frozen-frame detector), not
black-frame counting.**

One transient seen mid-session: video went black while the core stayed alive
(beacon counters advancing, `c1 r0`), and a reconfiguration brought it back.
Unexplained, seen once, and not reproduced after the clean reload - watch for
it rather than treat it as closed.

### OPEN: picture not centred, on BOTH VGA and HDMI (reported 2026-07-29)
Affects analog VGA as well as HDMI. VGA is driven straight from the core's
raster and never passes through the framebuffer, so **this is in the CORE's
active-window placement, not the scaler**. `ddr3_framebuffer` centres a
`disp_width=960` window at x=160 of 1280 automatically, so the HDMI side is
symmetric by construction. Look at the per-game hstart/vstart / active-window
constants in the core, not at the video path. Cosmetic, separate from the
scaler work.

**Landed and verified:**
  * **HDMI sync loss FIXED across every core** - `gowin_pll_hdmi27.v` VCO was
    1485 MHz, outside the 700-1400 MHz spec, recorded for months as an
    "accepted PA1019 warning". Now `MDIV_SEL=41, MDIV_FRAC_SEL=2,
    ODIV0_SEL=3` (VCO 1113.75 MHz, same 371.25 MHz out). PA1019 is gone from
    the log; soak-verified **30 min / 0.000% black**, confirmed on the monitor.
    The PLL is SHARED - `mcr2_console60k`, `video_test60k`, `merge_probe` and
    the shipping game cores all get this fix. **Re-testing the merged 9-game
    core is the highest-value open item.**
  * **`dvi_tx_ext` -> hdl-util `hdmi`** in `ascal_test60k`: raw DVI measured
    21.7% black, HDMI 0.00%. Brought **working audio** (1 kHz tone, 0
    dropouts) to that rig for the first time.
  * **`ascal_v` scales pixel-exactly** - h-stripe duplicate rate 0.333
    (ideal; the shipping framebuffer is 0.385), colour bars at exactly 120 px,
    all six pattern bands correct. From "ascal cannot be compiled on this
    toolchain" to this in one session.
  * **The simulation is now trustworthy** - deterministic (explicit `ram[]`
    init) and representative (two independent 74.25 MHz clocks). This is the
    single most useful artifact for whoever continues.

**Open:** ~2 wrong rows per frame in `ascal_v` (details below), the 4-slot
ring that should fix it (31-line producer wedge), and the interpolators that
were never ported.

**New doc:** `docs/scaler_options.md` - decision guide comparing all four
scaler paths with measured numbers, plus the measurement discipline. Start
there if you are new to this area.

## ascal_v — forward plan (agreed 2026-07-28)

Four things are outstanding beyond the last rendering defect. Ordered by what
blocks use of the core, not by how interesting they are.

### 1. Sync loss — HIGHEST PRIORITY
**CORRECTION 2026-07-28: the "7/90 black frames on every build" figure was
WRONG and must not be quoted.** Those 7 frames are at indices **0-6 of every
capture** - the capture card's lock-up time at the start of a recording, not
dropouts. A 90-frame grab is only ~1.5 s, far too short to catch a fault the
user sees "every so often". Any future dropout measurement must (a) discard
the first ~10 frames and (b) run for MINUTES. Use
`ffmpeg -vf blackdetect=d=0.02:pix_th=0.08 -f null -`, which reports black
intervals directly, rather than grabbing frames and thresholding.
**MEASURED PROPERLY 2026-07-28 (5 min each, same method, back to back):**
| build | black intervals in 300 s | black time |
|---|---|---|
| ascal_v (marker 9) | **26** | **6.5%** |
| **ddr3_framebuffer control** | **0** | **0.0%** |
**The sync loss is ascal_v's output path, NOT the platform.** The earlier
"identical on every build, therefore downstream of both scalers" conclusion
was wrong - it came from the capture lock-up artifact above.
Corroborating: the user's analog **VGA output never drops**, and VGA is driven
straight from the source raster, bypassing scaler, DDR3 and TMDS. So the core
and its timing are fine. The FPGA also keeps running throughout (643 beacon
lines logged across the control run).

**PRIME SUSPECT: the rig emits raw DVI, not HDMI.**
| | control | ascal rig |
|---|---|---|
| output stage | hdl-util `hdmi`, `DVI_MODE(0)` | `dvi_tx_ext` |
| signalling | HDMI: AVI InfoFrames + data islands | raw DVI, no infoframes |
| 5-min sync | 0% black | 6.5% black |
Many HDMI sinks re-lock periodically without AVI InfoFrames inside a timeout,
which matches the symptom (irregular 0.4-2.4 s blackouts on BOTH the monitor
and the capture card).
**So roadmap items 1 and 2 are ONE job:** swapping `dvi_tx_ext` -> hdl-util
`hdmi` should fix the sync loss AND deliver audio, with a module already
proven on this silicon across nine shipping games. Do that next.
**HDMI SWAP DONE AND MEASURED (marker C).** `dvi_tx_ext` replaced with
hdl-util `hdmi` (VIDEO_ID_CODE 4, DVI_OUTPUT 0, AUDIO_RATE 32000) + the 1 kHz
`sine_gen` tone + the INTEGER `AUDIO_CLK_DELAY` divider. `ascal_v` gained
`ext_rast`/`ext_cx`/`ext_cy` so the hdmi module is the timing MASTER and the
scaler follows its cx/cy (hmin/hmax shifted 2 px to absorb the scaler's
2-cycle pixel pipeline). Build clean: 4968 registers (was 4284), 28/118 BSRAM,
no undeclared symbols. **Audio now exists in this rig for the first time.**
Result, one consistent parser over all three 5-minute logs:
| build | intervals | black time |
|---|---|---|
| ascal_v + raw DVI | 31 | **21.7%** |
| ascal_v + hdl-util HDMI | 32 | **7.8%** |
| ddr3_framebuffer control | **0** | **0.0%** |
**A real ~3x improvement, but NOT a fix.** (Note: an earlier hand parse of the
DVI log gave 6.5%; that parse was faulty - always use the same extractor for
both sides of a comparison.)

**SYNC LOSS IS FIXED 2026-07-28 - and the residual was MY MEASUREMENT.**
Exclusive-device 3-minute blackdetect on the HDMI build: **0 intervals,
0.00% black.** The user independently confirmed on the monitor that it no
longer cuts out. The earlier "7.8% residual" was self-inflicted: a SECOND
ffmpeg was grabbing a frame from `/dev/video4` 25 s into that run, and two
processes contending for one v4l2 device produce exactly that signature.
**Measurement discipline for this rig, learned twice now:**
  * nothing else may touch `/dev/video4` during a dropout measurement -
    `pgrep -f ffmpeg` first, and never grab a preview frame mid-run;
  * discard events starting at t<0.5 s (capture card lock-up);
  * use ONE parser for both sides of any comparison.
So: `dvi_tx_ext` -> hdl-util `hdmi` took ascal_v from 21.7% black to **0.00%**,
matching the ddr3_framebuffer control. Raw DVI without AVI InfoFrames was the
whole cause.

**AUDIO NOW EXISTS in the rig, and the first measurement found a real bug.**
Captured off the MiraBox (`arecord -D hw:3,0`, MS2109): tone present but at
**7852 Hz instead of 1000**, with 628k waveform glitches. Cause: `sine_gen`'s
`sample_en` is a ONE-CYCLE ENABLE but was fed `clk_audio`, which is a real
50%-duty CLOCK for the hdmi module - so the phase accumulator advanced ~1160
times per sample period. Fixed by deriving a single-cycle tick from
`clk_audio`'s rising edge. **Keep the two signals distinct: hdmi needs the
clock, sine_gen needs the pulse.**

**2026-07-28 LATE — THE REAL FAULT IS TIME-DEPENDENT AND LOOKS LIKE DDR3.**
Sequence observed with the user watching: the ddr3_framebuffer CONTROL build
(marker DD - the framebuffer all nine shipping games use) looked **perfect
immediately after flashing**, then began **flashing/dropping a few minutes
later on the same configuration**. That is exactly the "degrades on one
config, a RECONFIG recovers it" pattern in roadmap item 1.
**This invalidates the freshness of every dropout number measured so far** -
including "control = 0.00% black over 5 min", which was taken right after a
flash, i.e. precisely when the fault is absent. **Any future dropout
measurement must record TIME SINCE CONFIGURATION and run long enough to cross
the degradation point.**

Correlation that points at the cause:
| path | uses DDR3? | behaviour |
|---|---|---|
| analog VGA (straight off the source raster) | **no** | **never drops** |
| ascal_v -> HDMI | yes | degrades |
| ddr3_framebuffer -> HDMI | yes | degrades |
Everything that touches DDR3 degrades and recovers on reconfig; the one path
that bypasses it is flawless. A reconfig re-runs DDR3 calibration, which is
the obvious thing that would heal on reload and drift while sitting. The
beacon still reports `c1 r0` (calib complete, no reset) while degraded, so the
controller does NOT know it has a problem - do not trust that flag alone.
**Also note a monitor-compatibility layer on top of this:** one HDMI monitor
would not lock at all while a second monitor and the capture card were both
perfect on the same bitstream. Keep that separate from the DDR3 drift.

**PRIME SUSPECT FOUND: the HDMI PLL VCO IS OUT OF SPEC.**
Captured the board WHILE DEGRADED (40 s, control build): 51 black frames and
44 frozen frames - but the colour bars in a surviving frame are **perfect**
(8 bars, 118-120 px, exactly correct RGB). **So DDR3 data is fine; the LINK
drops.** That redirects suspicion from memory to clocking.
`src/ddr3fb/gowin_pll_hdmi27.v` runs `MDIV_SEL=55, ODIV0_SEL=4` from 27 MHz:
**VCO = 1485 MHz, outside the GW5A PLLA spec range of 700-1400 MHz.** This is
the PA1019 warning `CLAUDE.md` records as the single ACCEPTED exception
("NESTang's standard config, confirmed working"). **That acceptance now looks
wrong** - an out-of-spec VCO is exactly what works cold and goes marginal with
time/temperature.
It explains every observation: analog VGA never drops (different PLL,
`gowin_pll_mcr2`); both scalers degrade identically (both share this chain);
recovers on reconfig (PLL relocks cold); degrades while sitting; and the
picture content is intact whenever there IS a picture.
**FIXED AND SOAK-VERIFIED 2026-07-28.** `MDIV_SEL=41, MDIV_FRAC_SEL=2,
ODIV0_SEL=3` applied to `src/ddr3fb/gowin_pll_hdmi27.v`. **PA1019 is now
ABSENT from the build log**, and a 30-minute soak with NO reconfiguration
gave **0 black intervals / 0.000% black**, independently confirmed on the
monitor. The old PLL degraded within a few minutes of every configuration.
Build otherwise unchanged (4969 registers, 28/118 BSRAM).
`CLAUDE.md` updated: the "accepted PA1019 exception" is deleted and PA1019 is
a build-breaker again with no exceptions. The PLL is shared, so this should
fix HDMI dropout on `mcr2_console60k`, `video_test60k`, `merge_probe` and the
shipping game cores too - **worth re-testing the merged 9-game core next.**

(historical) FIX - same 371.25 MHz with an in-spec VCO:
| MDIV | ODIV0 | VCO | out | |
|---|---|---|---|---|
| 55 + 0/8 | 4 | **1485.00** | 371.25 | out of spec (current) |
| **41 + 2/8** | **3** | **1113.75** | 371.25 | **in spec - use this** |
| 27 + 4/8 | 2 | 742.50 | 371.25 | in spec (fallback) |
Set `MDIV_SEL=41, MDIV_FRAC_SEL=2, ODIV0_SEL=3`. **Verify PA1019 disappears
from the build log** (that warning becomes a real pass/fail signal again), then
soak-test for >30 min WITHOUT reconfiguring. If it holds, update `CLAUDE.md` -
the "accepted PA1019 exception" section is then actively harmful advice, and
the same PLL is used by the shipping game cores, so this would fix them too.

**IF THE PLL FIX DOES NOT HOLD:** `src/ascal/avl_ddr3_memtest.sv` already exists and
drives the same bridge with an address-derived payload (a wrong ADDRESS fails
as loudly as wrong DATA); it previously ran zero mismatches over thousands of
passes. **Run it for tens of minutes without reconfiguring** and watch for
errors appearing over time. If they do, this is DDR3 calibration drift and the
fix belongs in the controller (periodic recalibration / read-leveling), not in
any scaler. If it stays clean while HDMI still degrades, the drift is in the
HDMI/TMDS clocking instead.

**AUDIO MEASURED GOOD after the tick fix** (build marker E), captured off the
MiraBox MS2109 at 48 kHz for 20 s:
| metric | before tick fix | after |
|---|---|---|
| tone | 7852 Hz | **982.6 Hz** (expect 1000) |
| waveform glitches | 628160 (31408/s) | **87** (4.35/s) |
| real dropouts | - | **0** |
The one "dropout" the checker reports sits at **t=0.003 s** and is the
`arecord` lock-up at capture start - the exact analogue of the video capture
artifact. After t=1 s the stream is continuous (the 4.2% "silence" is just the
sine's zero crossings). **So: HDMI video holds sync 100%, and audio runs clean
with no dropouts.** Both A5 gates met.

**Minor open item:** the tone reads 982.6 Hz rather than 1000 (-1.7%). The
audio clock itself is right (`AUDIO_CLK_DELAY`=1160 -> 32004 Hz, +0.013%), so
this is most likely truncation in `sine_gen`'s phase increment, or the capture
card's 32->48 kHz resampling. Cosmetic for a test tone; worth checking before
real game audio goes through, since a systematic pitch error would carry. **This is what makes the platform
unusable** - it is why the DDR3 path was rejected, and no amount of scaler
work touches it. Ties directly into roadmap item 1 (HDMI dropout) and the
"a RECONFIG recovers it" lead. Attack this before polishing the scaler.

### 2. HDMI instead of DVI + AUDIO (one job, not two)
`ascal_test60k` uses `dvi_tx_ext`, which is **DVI-only - there is no audio
path at all** (see the note at the top of `ascalv_top.sv`). Both items are the
same piece of work: bring in hdl-util `hdmi.sv`.
  * **MiSTer's audio is NOT transplantable** - `sys_top.v` drives an external
    **ADV7513** over parallel RGB + I2S, and `sys/i2s.v` is a ~40-line
    serialiser. There is NO data-island/ACR/CTS/audio-packet logic anywhere in
    MiSTer's `sys/` because the ADV7513 does it in silicon. We generate TMDS
    ourselves via OSER10, so hdl-util (already vendored, already carrying
    audio for all nine shipping games) is the only real option.
  * **The work is raster ownership.** `hdmi.sv` is the timing MASTER (`cx`/`cy`
    are outputs); `ascal_v` generates its own raster. Give ascal_v external
    raster inputs driven from `cx`/`cy` - both are 720p/1650x750 on the same
    74.25 MHz clock, so everything downstream is unchanged (costs a 2-pixel
    horizontal offset from the pixel pipeline, correctable).
  * **Use the INTEGER divider** `AUDIO_CLK_DELAY = 74250*1000/AUDIO_RATE/2`
    copied from `ddr3_framebuffer.v`. A fractional-exact divider made dropouts
    WORSE (roadmap item 1) and a declared-vs-actual rate mismatch was the
    original 50% rate lie. Then add the 1 kHz sine +
    `tools/audio_dropout_check.py`; gate on BRAM's 0 lost cycles in 15 s.

### 3. Interpolation — the feature we deliberately removed
The port is **nearest-neighbour only**. At 1.5x that maps 480->720 as
1,2,1,2..., so anything in motion crawls - this is inherent, not a bug, and it
is a real part of the "shimmer". ascal's answer is bilinear / sharp-bilinear /
bicubic / polyphase (`mode[2:0]`, with `MASK` deciding which are BUILT).
Restore cheapest-first: **nearest -> bilinear -> sharp-bilinear**, leaving
bicubic/polyphase last. **Risk to plan for:** that is where all the DSPs go and
the likely `CK3001` trigger (see the four GowinSynthesis defects above), and it
is the reason the port was scoped to nearest in the first place. Sharp-bilinear
is the accepted sweet spot for arcade content, so stopping there is a
legitimate end state.

### 4. Cleanups carried by the current code
  * **DELETE `dbg_underrun`** - measured 78-410 hits/frame with ZERO
    correlation to real glitches. The toggle-based `rd_busy` is not a valid
    completion signal; replace with a word count if a guard is ever needed.
  * Remove the `+define+ASCALV_TRACE` scaffolding once the last defect is
    closed (it is `ifdef`-guarded, so it costs nothing meanwhile).
  * `sim/vsynth/obj_dir/` build artifacts are tracked in git - add a
    `.gitignore` entry.
  * `mcr_testpattern` gained a `FREEZE_BAR` parameter (default 0, hardware
    unaffected); keep it, the multi-frame signature comparison needs it.

## Video dropout A/B rig — `video_test60k/` (2026-07-28)

Matched pair, same test pattern + same 1 kHz sine + same hdl-util HDMI stack,
differing ONLY in framebuffer architecture. Build with
`gw_sh build_bram.tcl` / `gw_sh build_ddr3.tcl` from `video_test60k/`.

  * `bram_top.sv` - nestang architecture ported from nes2hdmi.sv:
    dual-port BRAM, writer frame-stateless, 1-cycle read, ONE output clock
    domain. New `src/video/bram_scaler.sv`.
  * `ddr3_top.sv` - the same test through gbatang `ddr3_framebuffer`.

RESULTS (capture card video + `arecord` from the MS2109, analysed with
`tools/audio_dropout_check.py`):

| | BRAM | DDR3 |
|---|---|---|
| Logic | 1788 (3%) | ~4500 (8%) |
| BSRAM | 90/118 | ~9 |
| hclk Fmax | **106.6 MHz** | 82-83 MHz |
| picture | correct | correct |
| audio, 15 s | **0 lost cycles** | **1 lost cycle** |

Both scale CORRECTLY (unlike ascal). The BRAM build has ~24 MHz more hclk
margin and measurably cleaner audio - one lost cycle in 15 s on DDR3 matches
the "slight clicks" heard on hardware. BRAM cost is 90/118 BSRAM at
512x480x6 (RGB222); a palette index would cut that as it does for nestang.
Both show a slowly drifting TEAR LINE - expected and benign: single-buffered
and free-running, exactly like nestang, so a 60.09 vs 60.00 Hz mismatch
tears rather than dropping frames.

NOT reproduced: "raining white pixels" at the left edge seen on a real
monitor does not appear through the capture card (MJPEG likely smooths
single-pixel noise). Frame-to-frame instability measures the same on both.

NOTE the test rig is reportedly much cleaner than the PRODUCTION core, which
shares this same DDR3 framebuffer. That points at something the rig does not
have - the core's own audio path, SDRAM contention, OSD, or ROM loader -
rather than at the framebuffer itself. Worth bisecting there next.
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

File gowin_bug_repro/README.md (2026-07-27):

# GowinSynthesis defect reproducer — ascal on GW5AT-60

Self-contained. Nothing outside this directory is referenced.

Full analysis: **[BUG_REPORT.md](BUG_REPORT.md)**

## Quickest look — no board needed

```sh
gw_sh build_defect2_PA2122.tcl
```

Synthesis succeeds, then PnR fails:

```
ERROR (PA2122) : Not support 'o_h_poly_phase_a.t1_...'(SPX9)
                 WRITE_MODE = 2'b10, please change write mode
                 WRITE_MODE = 2'b00 or 2'b01.
```

GowinSynthesis packs plain register pipelines into block-RAM shift registers
and then asks for a write mode its own placer rejects.

## The important one — silent wrong hardware

```sh
gw_sh build_defect1_miscompile.tcl
```

Builds **clean**: 0 errors, 0 setup violations, 0 hold violations, `hclk`
~83 MHz actual against 74.25 MHz required. The resulting bitstream scales a
512x480 test pattern into a 720p window. **Vertical scaling is pixel-perfect;
horizontal scaling is exactly 4x too fast**, so the image occupies a quarter
of the window and then repeats.

The same VHDL is correct under GHDL behavioural simulation *and* under GHDL's
own synthesis engine simulated gate-level (see `sim/`).

## Hardware setup (for defect 1)

Sipeed Tang Console 60K. HDMI out shows the scaled pattern; a UART beacon on
the USB-C serial port (115200 8N1) reports internal scaler state.
Analog RGB on the J10 header carries the same source at its native timing.

## Contents

| Path | What |
|---|---|
| `src/ascal_upstream.vhd` | Temlib's ascal, **unmodified**. md5 `1b17376e8bf19b5c3c96c42d8d588ae6` |
| `src/ascal_gowin.vhd` | + `syn_srlstyle` workaround for PA2122, + debug taps |
| `src/ascal_gw.vhd` | thin wrapper: fixes generics, exposes debug taps |
| `src/mcr_testpattern.sv` | 512x480 colour-bar source, 31 kHz arcade timing |
| `src/ascal_avl_ddr3.sv` | Avalon-MM burst master -> Gowin DDR3 app interface |
| `src/ddr3_memory_interface.v` | Gowin DDR3 controller IP (your own) |
| `src/dvi_tx_ext.sv`, `src/tmds_channel.sv` | DVI output |
| `sim/` | GHDL + verilator harnesses proving the RTL is correct |

## Licensing

`ascal.vhd` is by Temlib. Its header states *"This code can be freely
distributed and used for any purpose"*, so it may be used freely as a test
case. Upstream:
<https://github.com/MiSTer-devel/Template_MiSTer/blob/master/sys/ascal.vhd>

`tmds_channel.sv` is from hdl-util/hdmi (MIT). The PLL and DDR3 interface
sources were produced by Gowin's own IP generator.

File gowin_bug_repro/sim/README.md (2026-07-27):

# Simulation evidence

Both of these render the test pattern **correctly**, from the same VHDL that
misbehaves on Gowin hardware.

## 1. Behavioural (GHDL)

```sh
python3 mk_ascal_sim.py          # guards 3 `natural` underflows GHDL rejects
ghdl -a --std=08 ascal_sim.vhd ../src/ascal_gw.vhd tb_ascal.vhd
ghdl -r --std=08 tb_ascal --stop-time=90ms
python3 ascal_sim_check.py ascal_out.txt
```

Expected: one full-width image, `[(160, 1119, 960)]`, colour bars 120 px each.

## 2. GHDL's own synthesis engine, simulated gate-level (verilator)

This is the check Gowin's encrypted `.vg` netlist makes impossible.

```sh
ghdl synth --std=08 --out=verilog ascal_gw > ascal_gw_synth.v
verilator --cc --exe --build -O3 -Wno-fatal --top-module synth_top \
    -o vsynth_sim vsynth_top.v vsynth_ddr3_model.v ascal_gw_synth.v \
    ../src/mcr_testpattern.sv ../src/ascal_avl_ddr3.sv vsynth_main.cpp
./obj_dir/vsynth_sim
```

Runs in ~2 seconds. Expected, for a 640-wide window (bars should be 80 px):

```
bars at 81-158, 161-238, 241-318, 321-398, 401-478, 481-558, 561-638
```

Note the output raster free-runs faster than the 60 Hz source here, so the
harness dumps a late frame; dumping an early one shows black because the
framebuffer has not been filled yet.

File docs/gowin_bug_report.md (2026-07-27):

# GowinSynthesis defect report — GW5AT-60, Gowin EDA V1.9.11.03

Five independent issues found in GowinSynthesis while porting a
well-established open-source VHDL video scaler to a GW5AT-60:

| # | Issue | Severity |
|---|---|---|
| 0 | **GowinSynthesis crashes** (SIGFPE, core dumped) during "Running inference" — V1.9.12.03 only; V1.9.11.03 builds the same sources cleanly | **Critical (regression)** |
| 1 | **Silent functional miscompile** of a Bresenham accumulator — builds clean, meets timing, wrong hardware | High |
| 2 | `PA2122` — the tool infers a block-RAM shift register and gives it a `WRITE_MODE` its own placer rejects | Medium (blocks PnR, workaround exists) |
| 3 | `CK3001` — invalid DSP cascade (`CASI`) configuration | Medium (blocks PnR, no workaround found) |
| 4 | Synthesis attributes silently ignored (`ramstyle`, `syn_ramstyle`, `syn_multstyle`) | Low, but directly causes #2 and makes #1 far harder to diagnose |

Defect 1 is the important one: **the design builds with no errors and no
warnings, meets timing with margin, and produces wrong hardware behaviour.**

All are reproducible with a single freely-redistributable source file.

---

## 1. Environment

| Item | Value |
|---|---|
| Tool A | Gowin EDA **V1.9.11.03 Education**, Linux tarball — defects 1-4 |
| Tool B | Gowin EDA **V1.9.12.03 Commercial** (node-locked licence), Linux tarball — **defect 0** |
| Flow | headless `gw_sh build.tcl` (GowinSynthesis, not Synplify) |
| Device | `GW5AT-LV60PG484AC1/I0`, `-device_version B` (GW5AT-60) |
| Board | Sipeed Tang Console 60K |
| Host | Ubuntu 24.04 x86-64 |

Relevant synthesis options:

```tcl
set_device GW5AT-LV60PG484AC1/I0 -device_version B
set_option -synthesis_tool gowinsynthesis
set_option -verilog_std sysv2017
set_option -vhdl_std vhd2008
set_option -place_option 2
set_option -rw_check_on_ram 0        # also reproduces with 1
```

## 2. Device under test

`ascal.vhd` — the "Avalon Scaler" by Temlib, the video scaler used by every
MiSTer FPGA core. ~3000 lines of portable VHDL, no vendor primitives.

* Upstream: <https://github.com/MiSTer-devel/Template_MiSTer/blob/master/sys/ascal.vhd>
* Version tested: `md5 1b17376e8bf19b5c3c96c42d8d588ae6`, 3033 lines
* **Licence:** its own header states *"This code can be freely distributed and
  used for any purpose"* — so it may be attached to this report and used as a
  test case without restriction.

Line numbers below refer to that **upstream, unmodified** file.

This code is a good regression test: it is known-good silicon on Intel Cyclone V
across hundreds of designs, it is pure portable VHDL, and it exercises inferred
memories, deep register pipelines, FSMs and integer arithmetic heavily.

---

## 3. Defect 0 — GowinSynthesis crashes (SIGFPE) in V1.9.12.03

**Severity: critical. This is a regression — V1.9.11.03 builds the identical
sources cleanly.** V1.9.12.03 cannot build this design at all.

```
Running device independent optimization ...
[10%] Optimizing Phase 0 completed
[15%] Optimizing Phase 1 completed
[25%] Optimizing Phase 2 completed
Running inference ...
Floating point exception (core dumped)          <-- exit status 136
```

The crash is always at the same stage ("Running inference"), with no error
message and no log entry.

### Reproduced with

| Input | V1.9.11.03 | V1.9.12.03 |
|---|---|---|
| upstream `ascal.vhd` + minimal wrapper (`build_defect2_PA2122.tcl`) | `ERROR (PA2122)` at PnR | **SIGFPE** |
| patched `ascal.vhd`, full design (`build_defect1_miscompile.tcl`) | builds clean, 0 violations | **SIGFPE** |
| same, with `MASK=0x07` (bicubic + polyphase removed) | builds clean | **SIGFPE** |

So it is not specific to the polyphase filters, not specific to our patches,
and not specific to the full design.

### Control — the environment is sound

A trivial design (a 12-deep 8-bit register pipeline) synthesises successfully
under V1.9.12.03 in the **identical** shell environment, same device, same
options:

```
GowinSynthesis finish        rc=0
```

Both versions require `LD_PRELOAD` of the system libfreetype on Ubuntu 24.04
(otherwise `gw_sh` aborts with `undefined symbol: FT_Done_MM_Var` before
printing anything); that is the only environment adjustment, and it is applied
identically to the passing control and the crashing runs.

### Note

Defect 3 (`CK3001`) reproduces on **both** versions, at a different instance
name (`u_ascal/u_ascal/n5541_o_0_s0` under V1.9.12.03).

---

## 4. Defect 1 — silent functional miscompile of the horizontal scaler

**Severity: high.** No error, no warning, timing met, wrong hardware.

### Symptom

The scaler upscales a 512×480 source into a 960×720 output window.
**Vertical scaling is pixel-perfect. Horizontal scaling is exactly 4× too
fast**, so the source is consumed in a quarter of the output width and the
image then repeats.

Measured on the real HDMI output with a capture card, one line of an
8-colour-bar test pattern (bar width should be 960/8 = 120 px):

```
window hmin=160 hmax=1119  (960 px)
  content 160..399  (240 px, bars 30 px)   then black    then a REPEAT at 672..911
window hmin=0    hmax=1279 (1280 px)
  content 0..319   (320 px, bars 40 px)   then black    then repeats at 512, 1024
```

Content width is always `512 × window / 4`.

### The logic that miscompiles

The horizontal position advance is a Bresenham accumulator in state `sCOPY`
(upstream **line 2234**):

```vhdl
WHEN sCOPY =>
   IF o_dshi=0 THEN
      dif_v:=(o_hacc_next - 2*o_hsize + (8*OHRESH)) MOD (8*OHRESH);
      IF dif_v>=4*OHRESH THEN
         o_hacc<=o_hacc_next;
         o_hacc_next<=o_hacc_next + 2*o_ihsize;
         hcarry_v:=false;
      ELSE
         o_hacc<=dif_v;
         o_hacc_next<=(dif_v + 2*o_ihsize + (4*OHRESH)) MOD (4*OHRESH);
         hcarry_v:=true;
      END IF;
      o_dcpt_inc <= '1';
   ELSE ...
```

with (upstream lines 320, 521, 1870):

```vhdl
CONSTANT OHRESH : natural := ohres_h(OHRES);          -- 4096 for OHRES=2304
SIGNAL   o_hacc,o_hacc_next,... : natural RANGE 0 TO 4*OHRESH-1;
VARIABLE dif_v                  : natural RANGE 0 TO 8*OHRESH-1;
```

`hcarry_v` decides whether to consume a source pixel. It should be true
`2*o_ihsize / 2*o_hsize` = 1024/1920 ≈ 53 % of cycles. On hardware it asserts
roughly 4× too often.

Note the **vertical** twin of this code is structurally
identical (upstream **line 2070**) but uses hardcoded moduli:

```vhdl
dif_v :=(o_vacc_next - 2*o_vsize + 16384) MOD 16384;
IF dif_v>=8192 THEN
```

**The vertical path works correctly on the same device, in the same build.**

### Evidence that the RTL and everything around it are correct

Two independent simulations of the *same source* render the pattern
pixel-exact — 8 bars of exactly the right width spanning the full window:

1. **GHDL behavioural simulation** (`ghdl -r`), identical source, identical
   output window, ideal Avalon memory: correct.
2. **GHDL's own synthesis engine, simulated gate-level** — a genuinely
   independent inference engine doing memory inference, FSM extraction and
   register mapping:

   ```sh
   ghdl synth --std=08 --out=verilog ascal_gw > ascal_gw_synth.v
   verilator --cc --exe --build -O3 --top-module synth_top ...
   ```

   Result (640-wide window, bars should be 640/8 = 80 px):

   ```
   bars at 81-158, 161-238, 241-318, 321-398, 401-478, 481-558, 561-638
   78-80 px each, spanning the full window        -> CORRECT
   ```

So the identical logic is correct under two independent synthesis paths and
wrong only under GowinSynthesis.

### Evidence that the inputs to this logic are correct on the Gowin hardware

Debug outputs were added to observe internal state on the running device and
read out over UART. **Every input to the failing decision matches simulation
exactly**; only the result differs:

| signal (sampled at the same output raster position) | GHDL sim | Gowin hardware |
|---|---|---|
| `i_himax` (detected input width − 1) | 511 | 511 ✔ |
| `i_hsize` (input window) | 512 | 512 ✔ |
| `o_ihsize` (input width, output domain) | 512 | 512 ✔ |
| `o_hsize` (output window) | 960 | 960 ✔ |
| `o_hmax` | 1119 | 1119 ✔ |
| `i_hdown` (downscale select) | 0 | 0 ✔ |
| `o_hburst` (bursts per line) | 1 | 1 ✔ |
| `{o_copylev, o_hbcpt}` (copy queue) | 0x04 | 0x04 ✔ |
| **`o_dcpt` (destination counter)** | **241** | **124 ✘** |

The external memory path was also verified independently on hardware: a
memtest driving the identical Avalon master and the same DDR3 controller with
an address-derived payload (so a wrong *address* fails as loudly as wrong
*data*) reports **zero mismatches over thousands of full write/verify passes**.

### Ruled out by experiment (each rebuilt and re-measured on hardware)

| Changed | Result |
|---|---|
| `OHRES` 2048 vs 2304 | no change |
| `FRAC` 4 vs 8 | no change |
| `N_BURST` 256 vs 2048 (changes RAM line stride 1536→2048 B) | no change |
| Interpolator mode 0 (nearest) vs 2 (sharp bilinear) | no change |
| Input auto-detect vs hard-coded input window (`iauto=0`) | no change |
| `dif_v` expression rewritten with explicit wide `unsigned` + mask | no change |
| `o_hacc*` **signals** converted to explicit `unsigned`, MOD → wraparound | no change |
| Forcing every pipeline out of RAM (see Defect 2) | no change |
| Avalon clock phase (0° vs 90° relative to output clock) | no change (sim) |

Timing is clean in every one of those builds: **0 setup violations, 0 hold
violations**, `hclk` ~83 MHz actual against 74.25 MHz required
(82.6-83.4 MHz depending on placement).

### What we would like

An explanation or fix for why this arithmetic/FSM produces different hardware
behaviour under GowinSynthesis than under two other synthesis engines.

Gate-level simulation of the Gowin netlist would have localised this in
minutes, but `impl/gwsynthesis/*.vg` is emitted `pragma protect` **encrypted**,
so it cannot be simulated or inspected. **Please consider providing an
unencrypted post-synthesis netlist option** — that alone would have avoided
most of this investigation.

---

## 5. Defect 2 — PA2122: inferred BSRAM shift register uses an unsupported WRITE_MODE

**Severity: medium.** Hard error, blocks PnR. Workaround exists.

Synthesis completes with no error; PnR then fails:

```
ERROR (PA2122) : Not support 'o_h_poly_phase_a.t1_o_h_poly_phase_a.t1_0_0_s'(SPX9)
                 WRITE_MODE = 2'b10, please change write mode
                 WRITE_MODE = 2'b00 or 2'b01.
```

GowinSynthesis packs plain register pipelines into SPX9/SP block-RAM shift
registers and then requests a write mode those primitives reject. **The tool
generates a configuration its own placer refuses.**

Triggering code — a 5-deep pipeline of a 40-bit record, upstream line 1027:

```vhdl
SIGNAL o_h_poly_phase_a, o_h_poly_phase_a2, o_h_poly_phase_a3,
       o_h_poly_phase_a4, o_h_poly_phase_a5 : poly_phase_t;
...
o_h_poly_phase_a2<=o_h_poly_phase_a;
o_h_poly_phase_a3<=o_h_poly_phase_a2;   -- etc.
```

The same error also appears for `o_hpixq` (upstream line 543), a 7-deep queue
of 4 pixels whose taps 6 and 8 are **read simultaneously** (upstream lines 2649, 2659) — something a
single-read-port RAM cannot provide:

```
ERROR (PA2122) : Not support 'o_hpixq[2][0].b_o_hpixq[2][0].b_0_0_s'(SP)
                 WRITE_MODE = 2'b10 ...
```

Note that restructuring `o_hpixq` into seven *discrete* signals made the tool
infer **block RAM** instead of distributed RAM — i.e. it infers memory from
plain register arrays quite aggressively.

**Workaround:** `ATTRIBUTE syn_srlstyle OF <signal> : SIGNAL IS "registers";`

---

## 6. Defect 3 — CK3001: incorrect DSP CASI configuration

**Severity: medium.** Hard error, blocks PnR. No workaround found.

Feeding GowinSynthesis a **Verilog** netlist of the same design (generated by
`ghdl synth --out=verilog`, and verified correct under verilator) fails with:

```
ERROR (CK3001) : The CASI configuration of 'u_ascal/u_ascal/mult_122505_s3' is incorrect
```

The tool maps the netlist's multipliers into cascaded DSP blocks and produces
an invalid cascade configuration. `(* syn_multstyle = "logic" *)` on the
module does not change the result (see Defect 4).

---

## 7. Defect 4 — synthesis attributes silently ignored

Not a crash, but it makes the other defects far harder to work around, and
costs users a great deal of time because failures are silent.

| Attribute | Honoured by GowinSynthesis V1.9.11.03? |
|---|---|
| `ramstyle` (Quartus spelling) | **No** — silently ignored |
| `syn_ramstyle` (Synplify spelling) | **No** — silently ignored |
| `syn_multstyle` | **No** — silently ignored |
| `syn_srlstyle` | Yes |
| `syn_keep`, `syn_preserve` | Yes |

"Silently ignored" is measured, not assumed: adding `syn_ramstyle
"registers"` to the affected signals changed **neither** the SSRAM count (21)
**nor** the register count (6483), byte for byte, in the resource report.

This matters because upstream guards these exact signals with
`ramstyle "logic"` (upstream lines 519, 544, 552) *specifically* to keep them
out of RAM:

```vhdl
ATTRIBUTE ramstyle OF o_hfrac : SIGNAL IS "logic"; -- avoid blockram shift register
ATTRIBUTE ramstyle OF o_hpixq : SIGNAL IS "logic"; -- avoid blockram shift register
ATTRIBUTE ramstyle OF o_div, o_dir : SIGNAL IS "logic"; -- avoid blockram shift register
```

Every one of those guards is inert on GowinSynthesis, which is what leads
directly to Defect 2.

**Request:** either honour `ramstyle`/`syn_ramstyle`, or emit a warning when
an unrecognised synthesis attribute is encountered. GHDL, by contrast, prints
`warning: unhandled attribute "syn_srlstyle"` — that one line would have saved
hours here.

---

## 8. Reproduction

Minimal case for Defects 2 and 4 — no board required, fails at PnR:

1. Take upstream `ascal.vhd` (md5 `1b17376e8bf19b5c3c96c42d8d588ae6`).
2. Instantiate it from any top with `OHRES=2304, IHRES=1024, N_DW=128,
   N_AW=25, N_BURST=2048, FRAC=8`.
3. Build for `GW5AT-LV60PG484AC1/I0 -device_version B` with the options in §1.
4. Observe `ERROR (PA2122)`.
5. Add `syn_srlstyle "registers"` to `o_hfrac`, `o_hpixq`, `o_div`, `o_dir`
   and the `o_[hv]_poly_phase_a*` pipelines; the build then completes.

**Defect 0 (V1.9.12.03 crash)** needs only steps 1-3 above: the same minimal
case that gives PA2122 on V1.9.11.03 crashes with SIGFPE on V1.9.12.03.

Defect 1 additionally needs the scaler driven with real video (512×480 in,
720p out) to observe the wrong picture; the internal-state table in §3 can be
reproduced by exporting `o_hacc` / `o_dcpt` to spare pins or a UART.

## 9. Contact / attachments available on request

* Complete buildable project (top level, constraints, `build.tcl`)
* The GHDL-synthesised Verilog netlist that behaves correctly
* Verilator harness reproducing the correct behaviour in ~2 seconds
* Capture-card images of the incorrect hardware output

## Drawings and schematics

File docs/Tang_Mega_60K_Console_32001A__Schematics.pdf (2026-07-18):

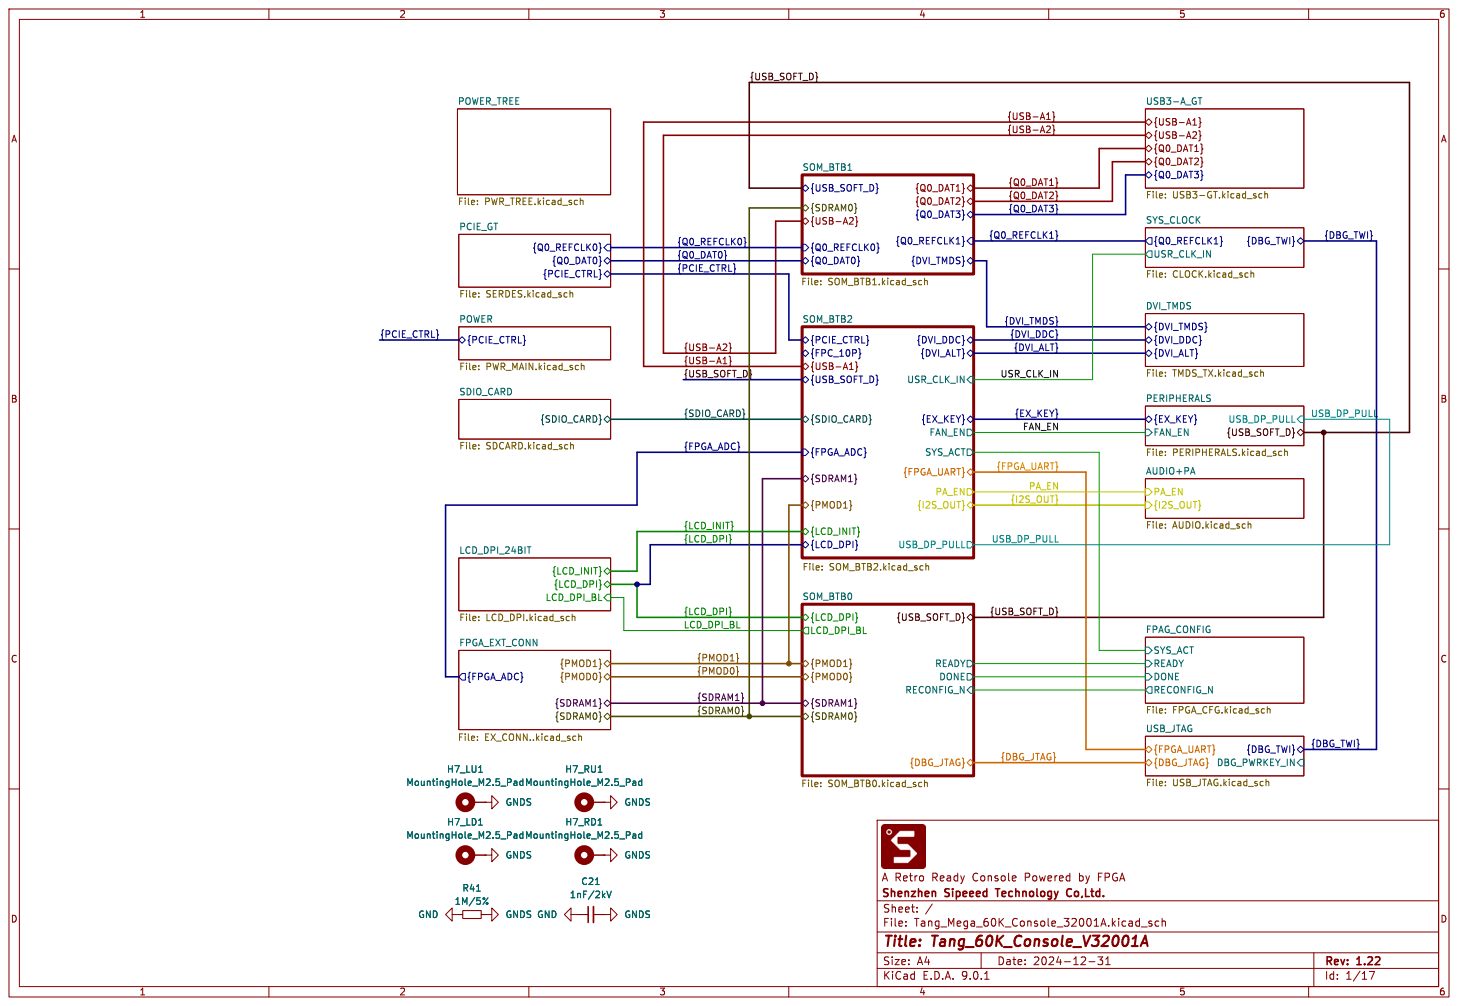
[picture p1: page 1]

File: PERIPHERALS.kicad_sch READY DONE RECONFIG_N
{I2S_OUT} AUDIO+PA

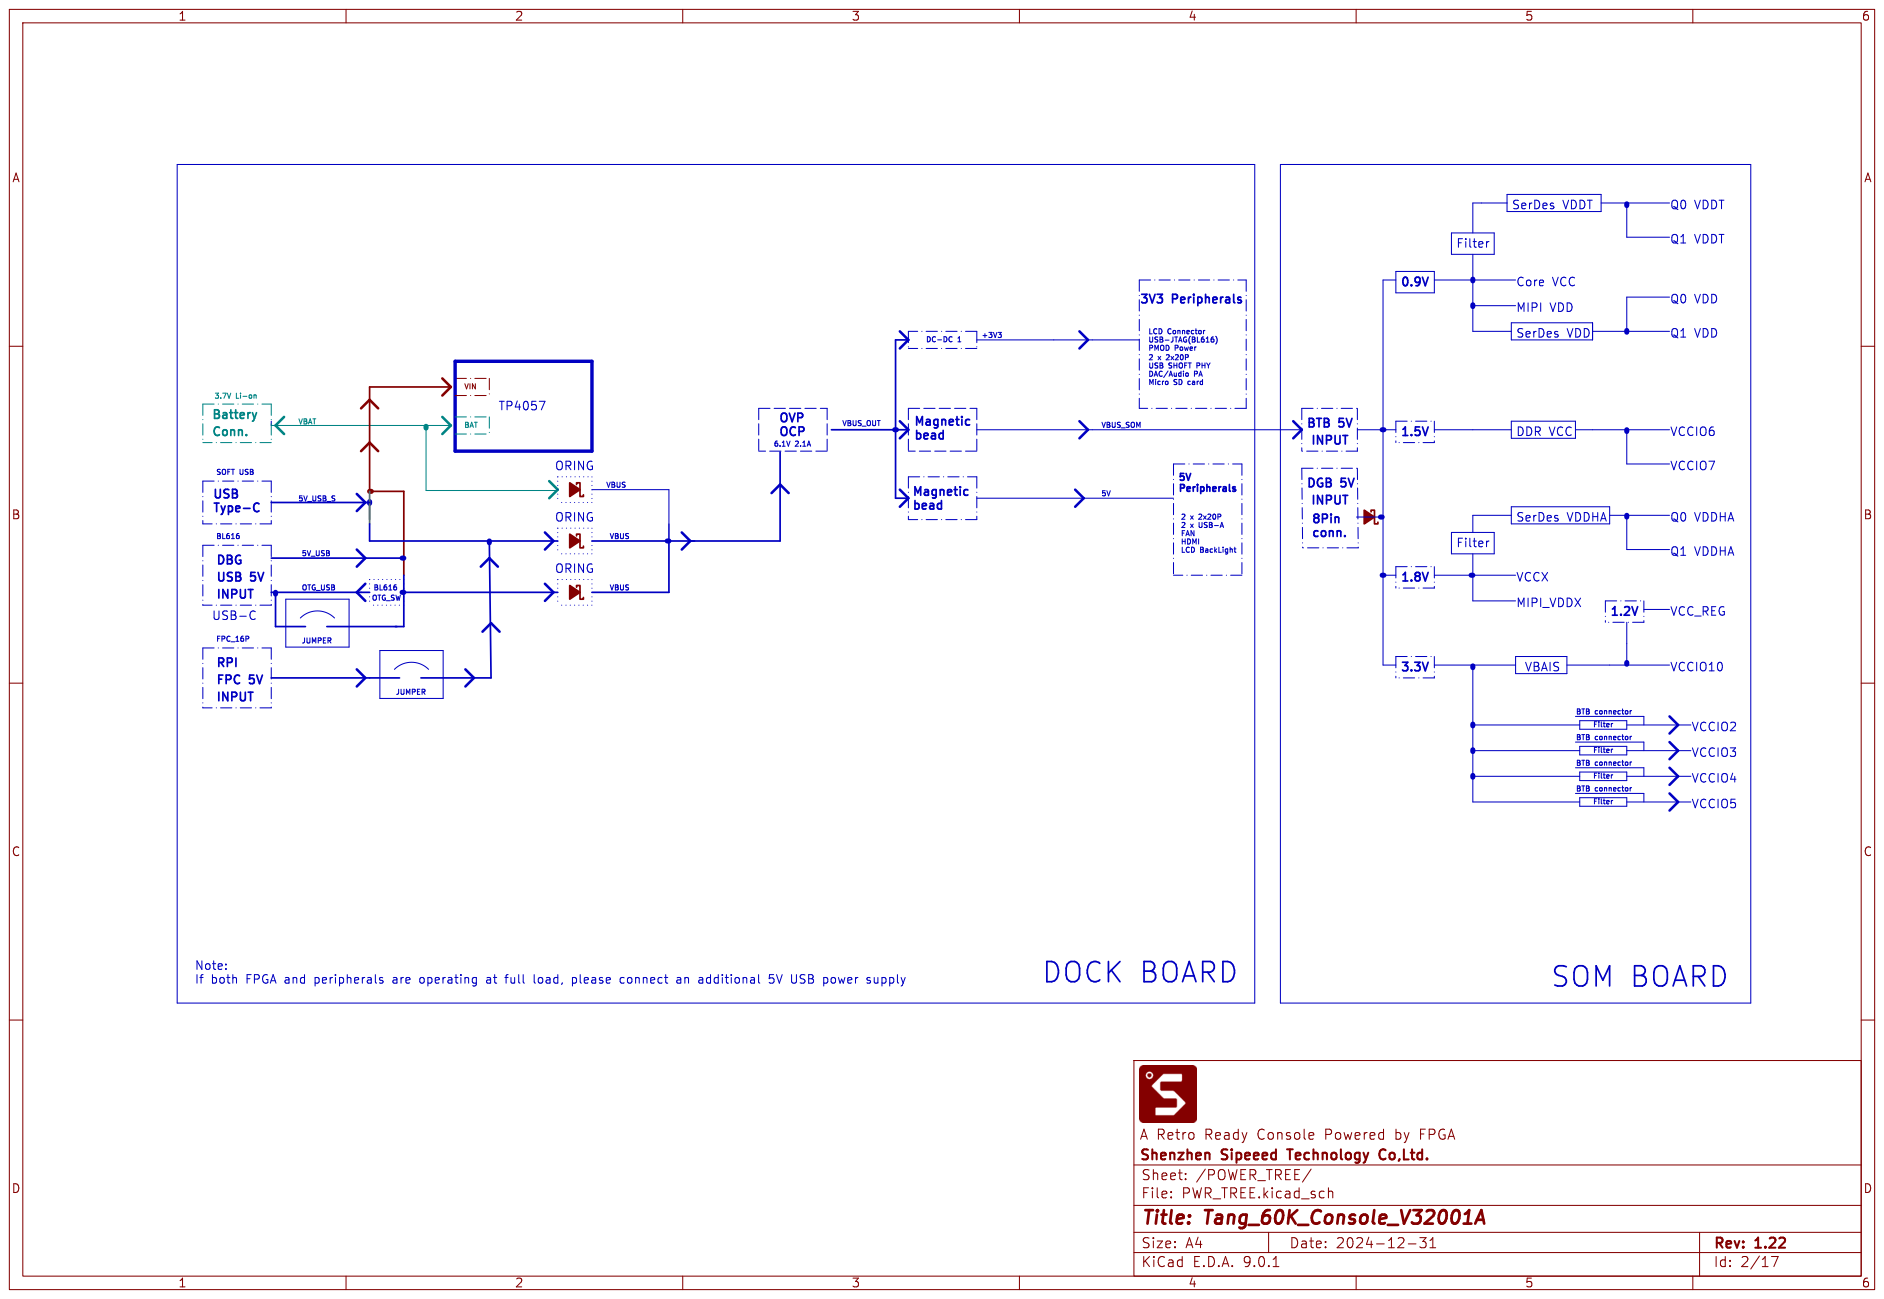
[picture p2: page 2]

LCD Connector USB-JTAG(BL616) PMOD Power 3V3 Peripherals Note:

BTB connector BTB connector SerDes VDDHA
VCCIO5 VCCIO4 VCCIO3 Q1 VDDHA

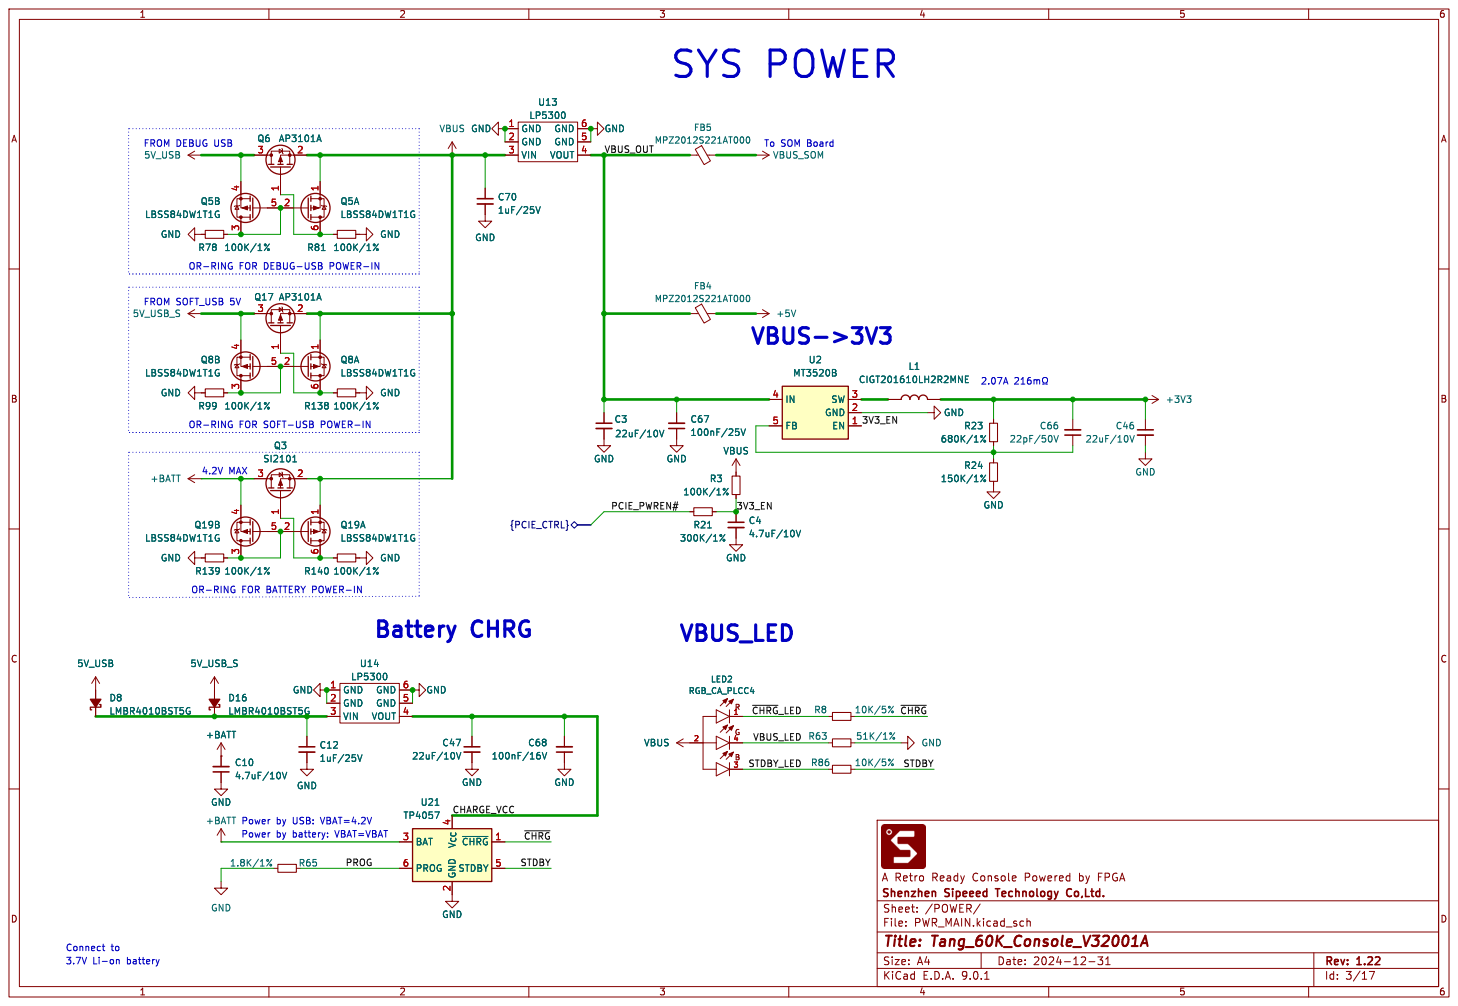
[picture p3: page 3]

OR-RING FOR DEBUG-USB POWER-IN

GND GND GND
OR-RING FOR SOFT-USB POWER-IN

OR-RING FOR BATTERY POWER-IN

2 BAT 3 PROG 6 GND GND

CHARGE_VCC
~{CHRG}1 STDBY 5 V_{CC} 4 GND

Power by battery: VBAT=VBAT Power by USB: VBAT=4.2V

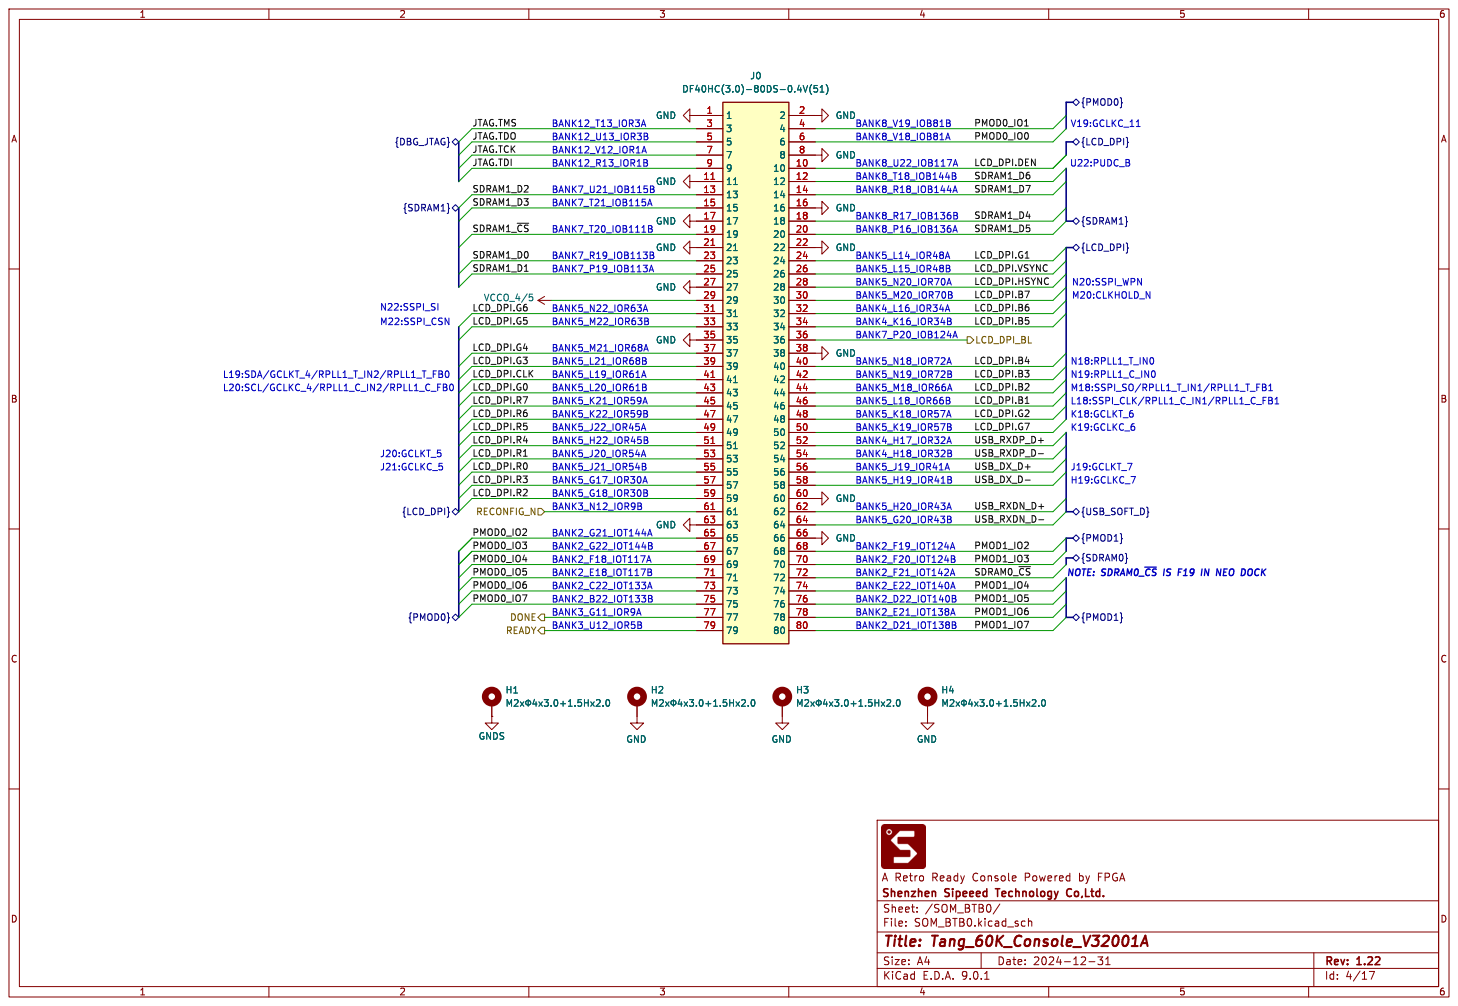
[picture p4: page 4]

þÿM2x¦4x3.0+1.5Hx2.0 GND GND GND GND GND

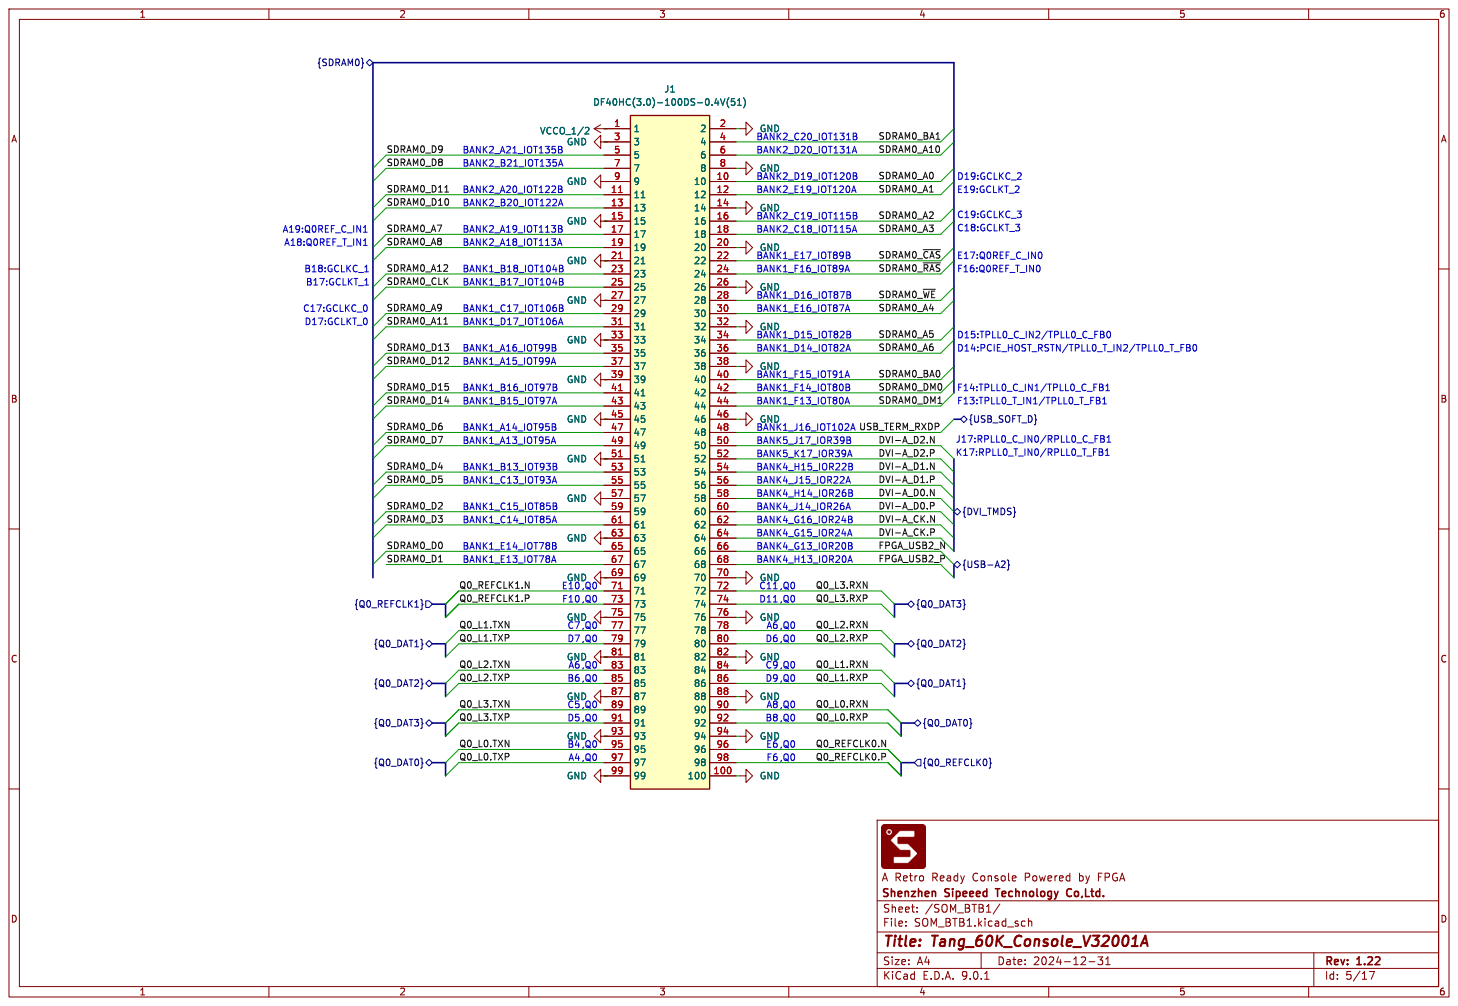
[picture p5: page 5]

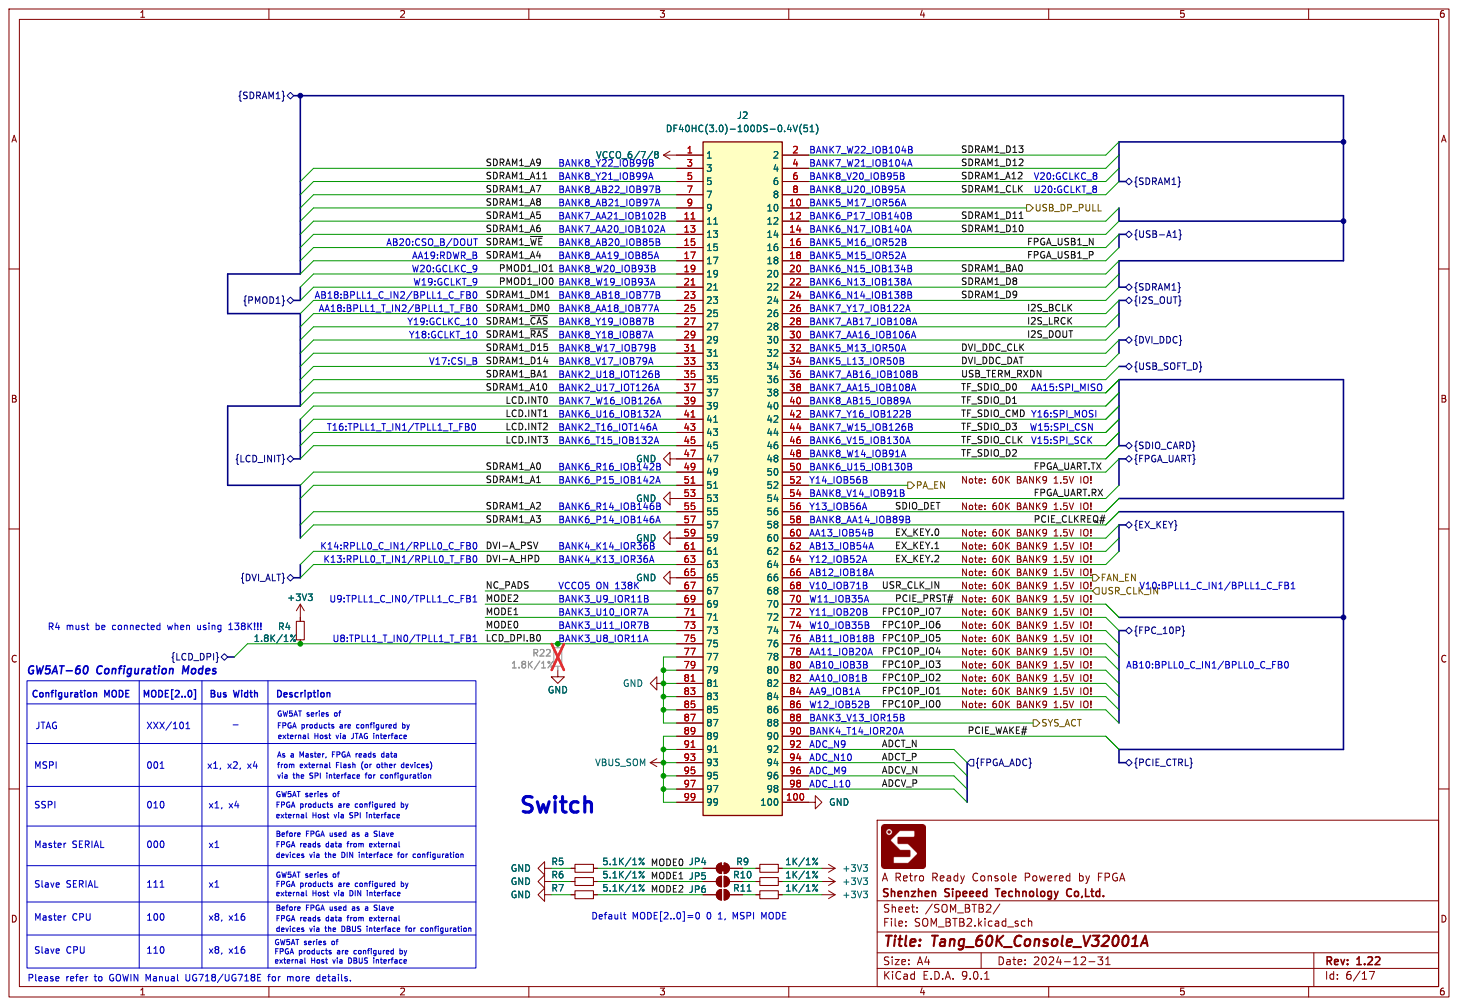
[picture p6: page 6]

Slave SERIAL Slave CPU

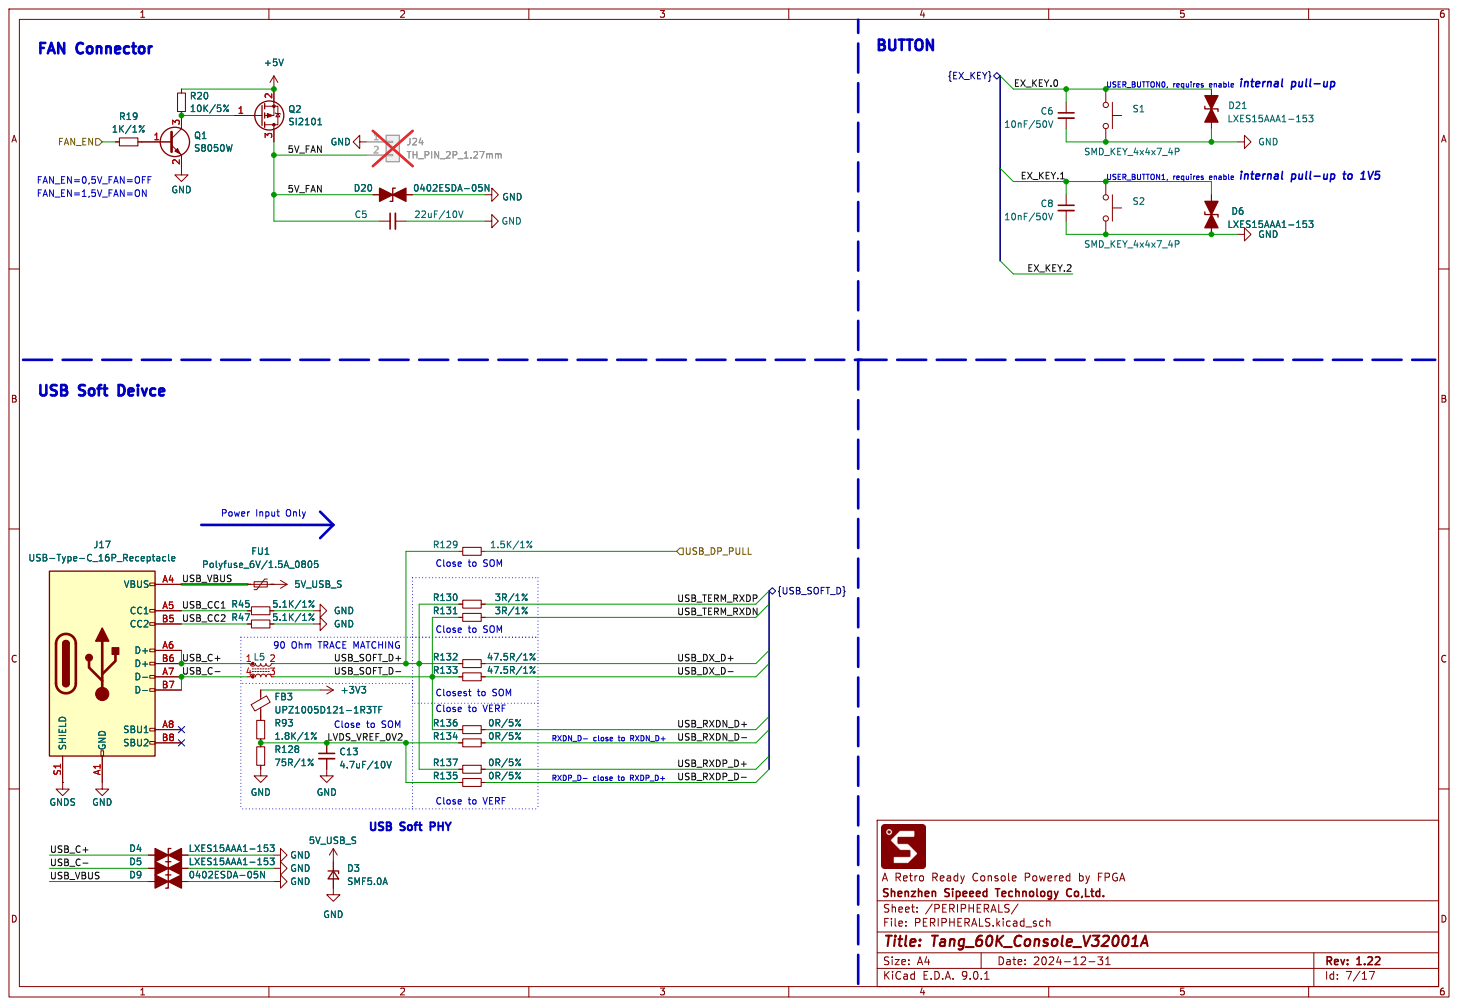
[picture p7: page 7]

Power Input Only
Close to VERF Close to SOM

RXDP_D- close to RXDP_D+ Close to VERF Closest to SOM

RXDN_D- close to RXDN_D+ USB Soft PHY

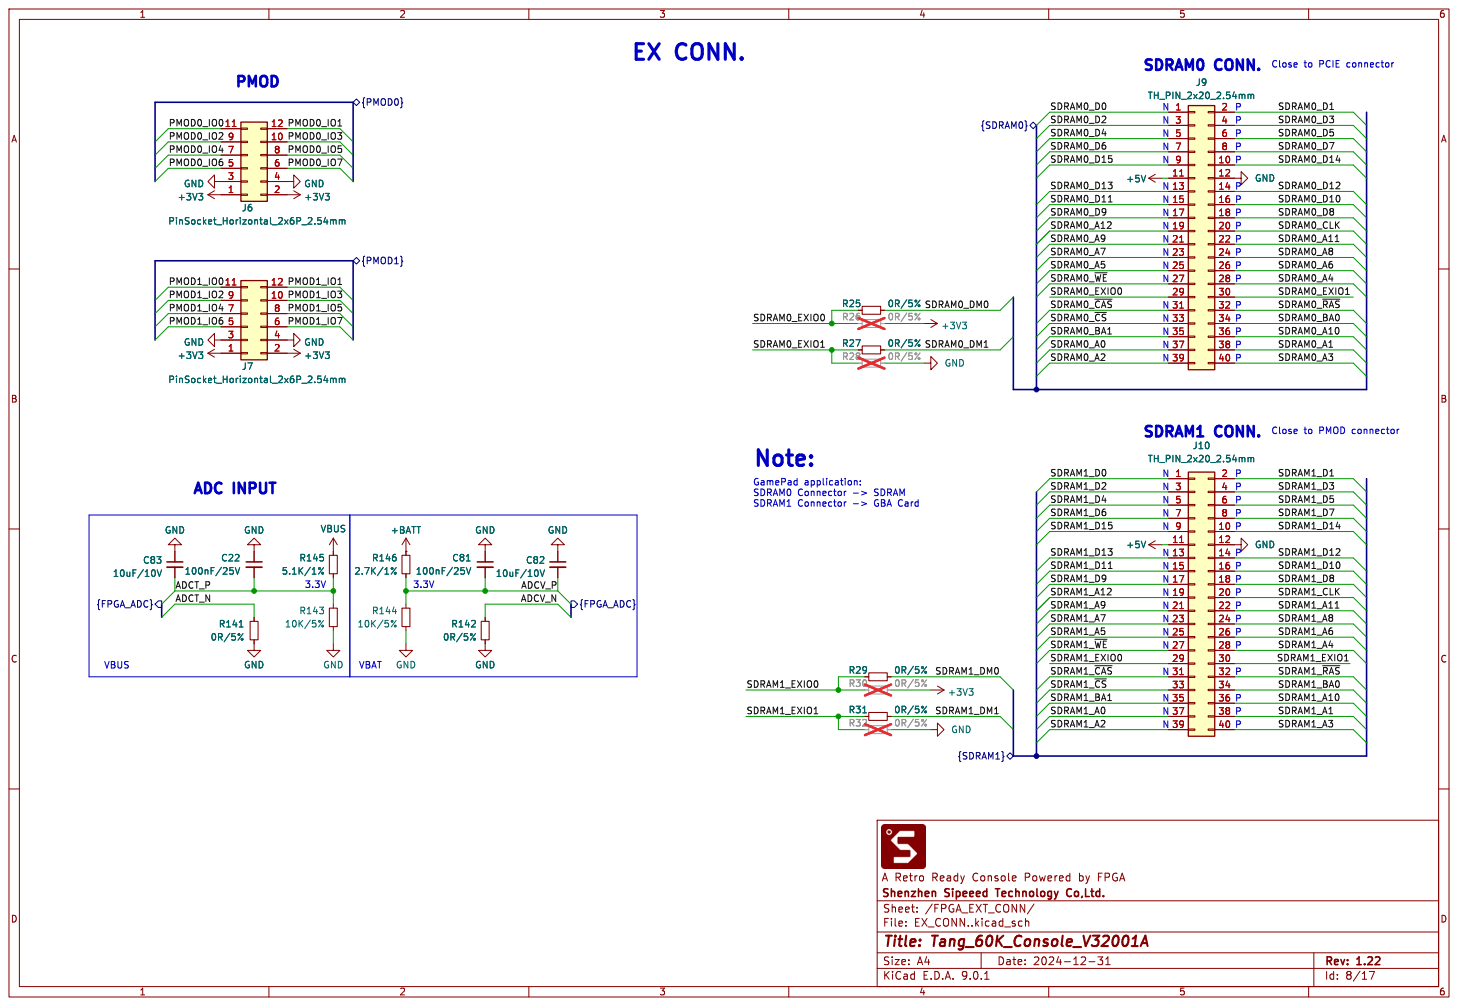
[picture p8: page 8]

Close to PCIE connector P

Close to PMOD connector P N SDRAM1 CONN. N ADC INPUT

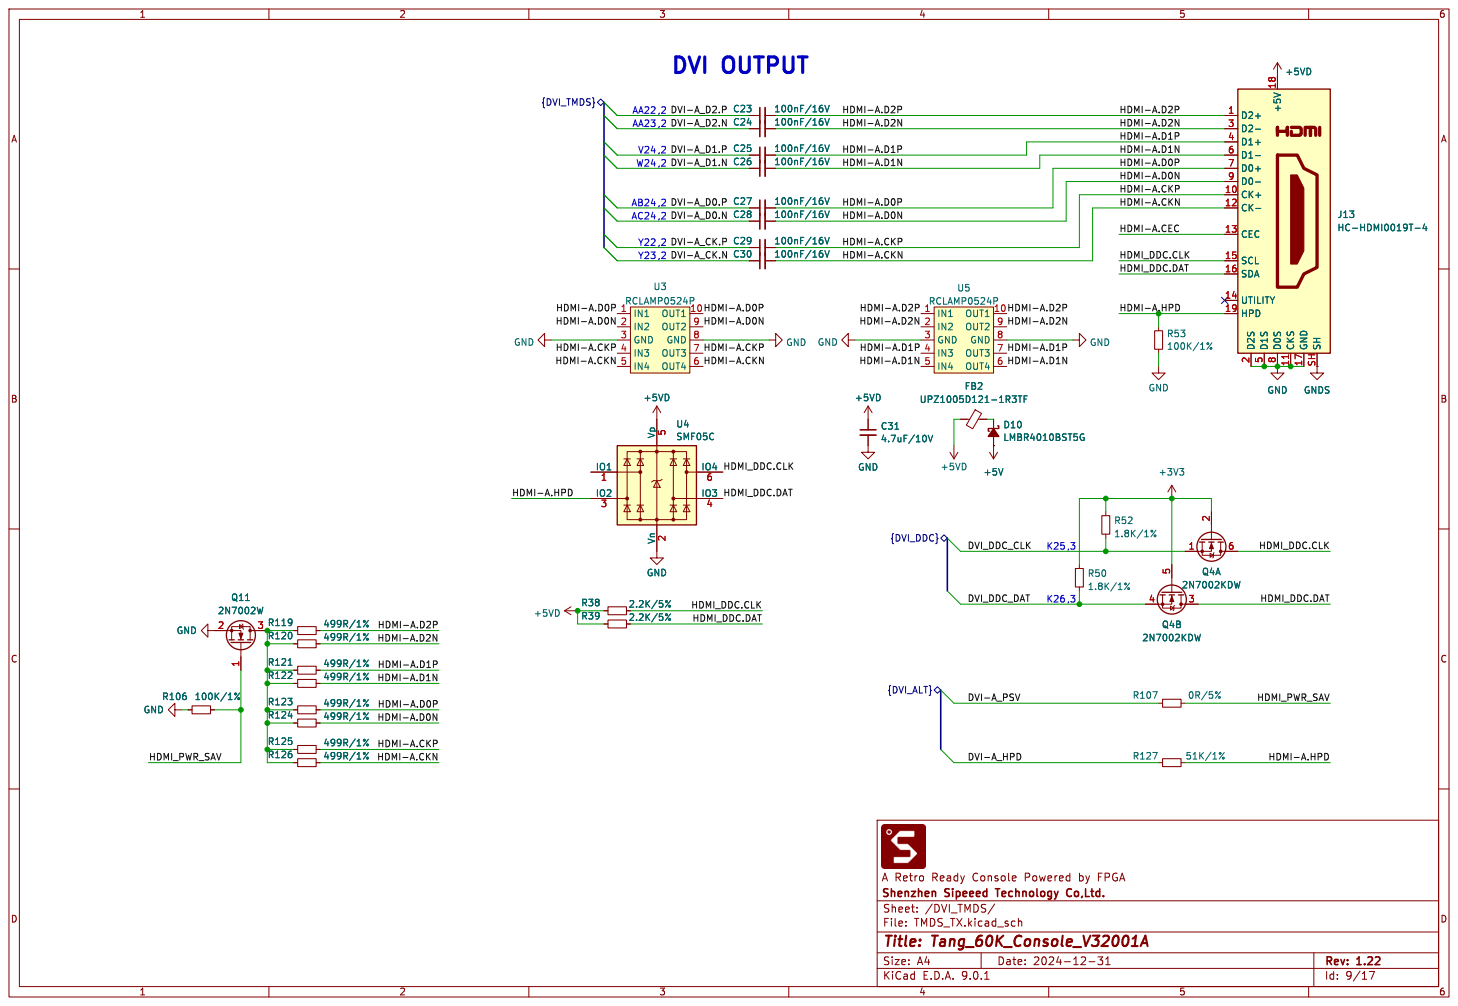
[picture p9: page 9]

8 CKS 11 GND 17 SH SH

HDMI-A.CKP HDMI-A.CKN

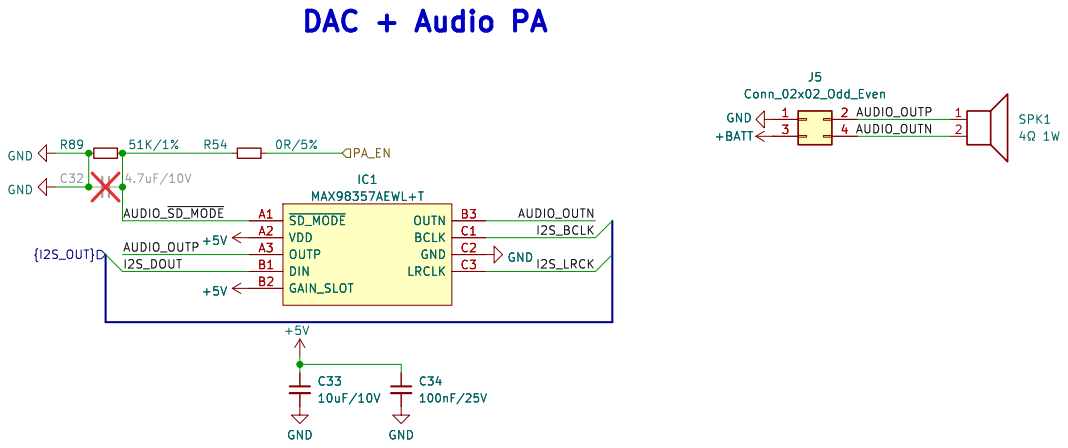
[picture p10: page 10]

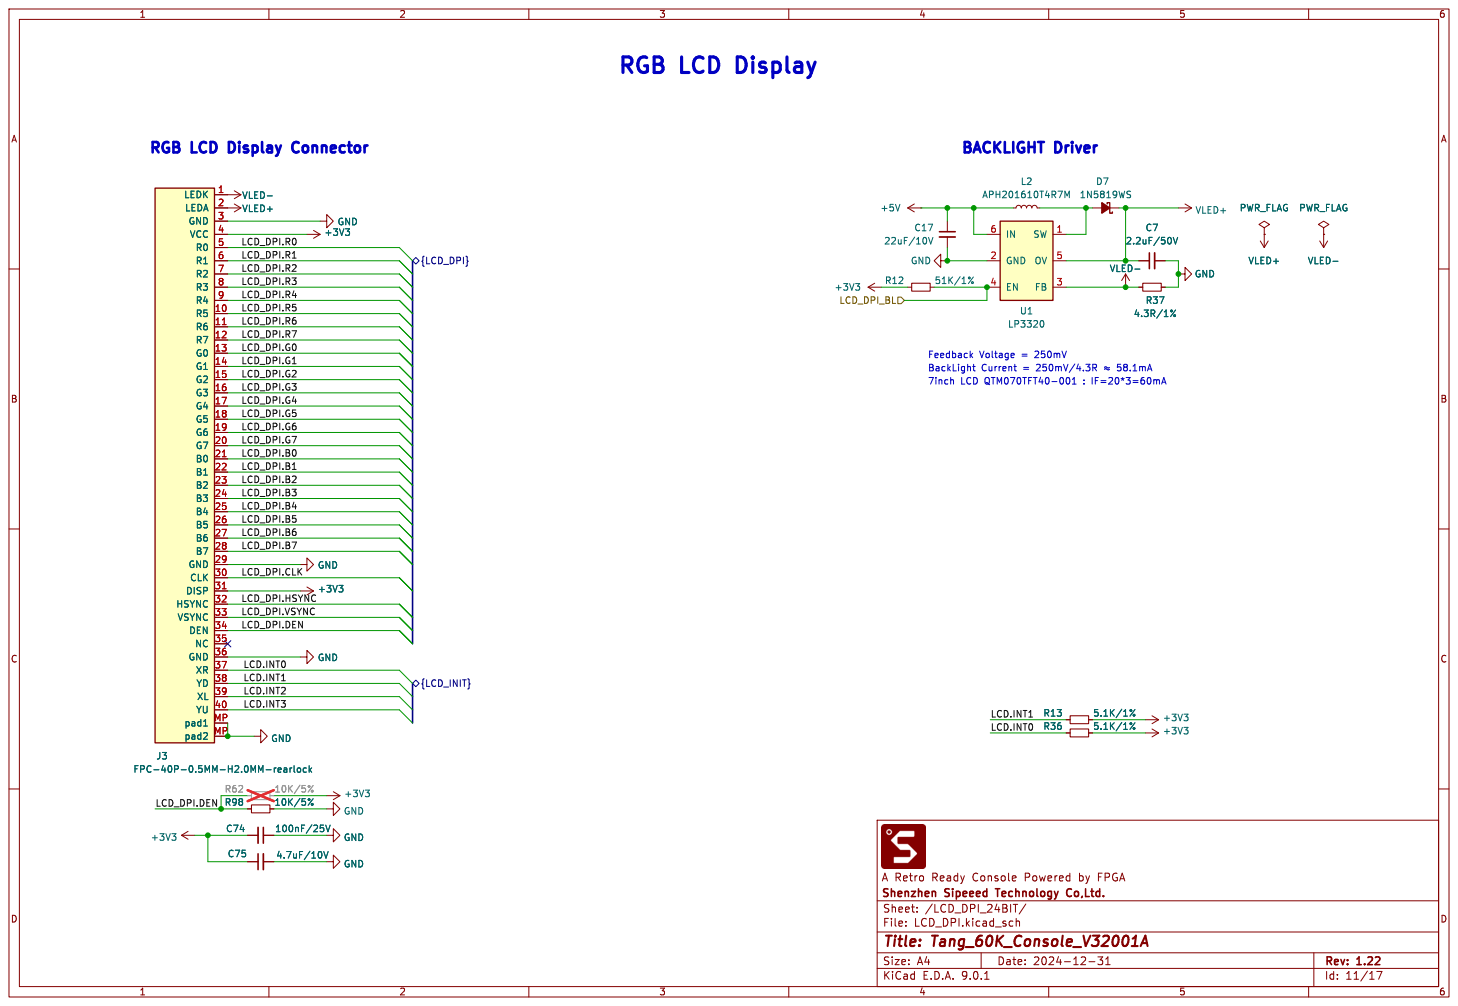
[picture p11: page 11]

LCD_DPI.DEN RGB LCD Display Connector

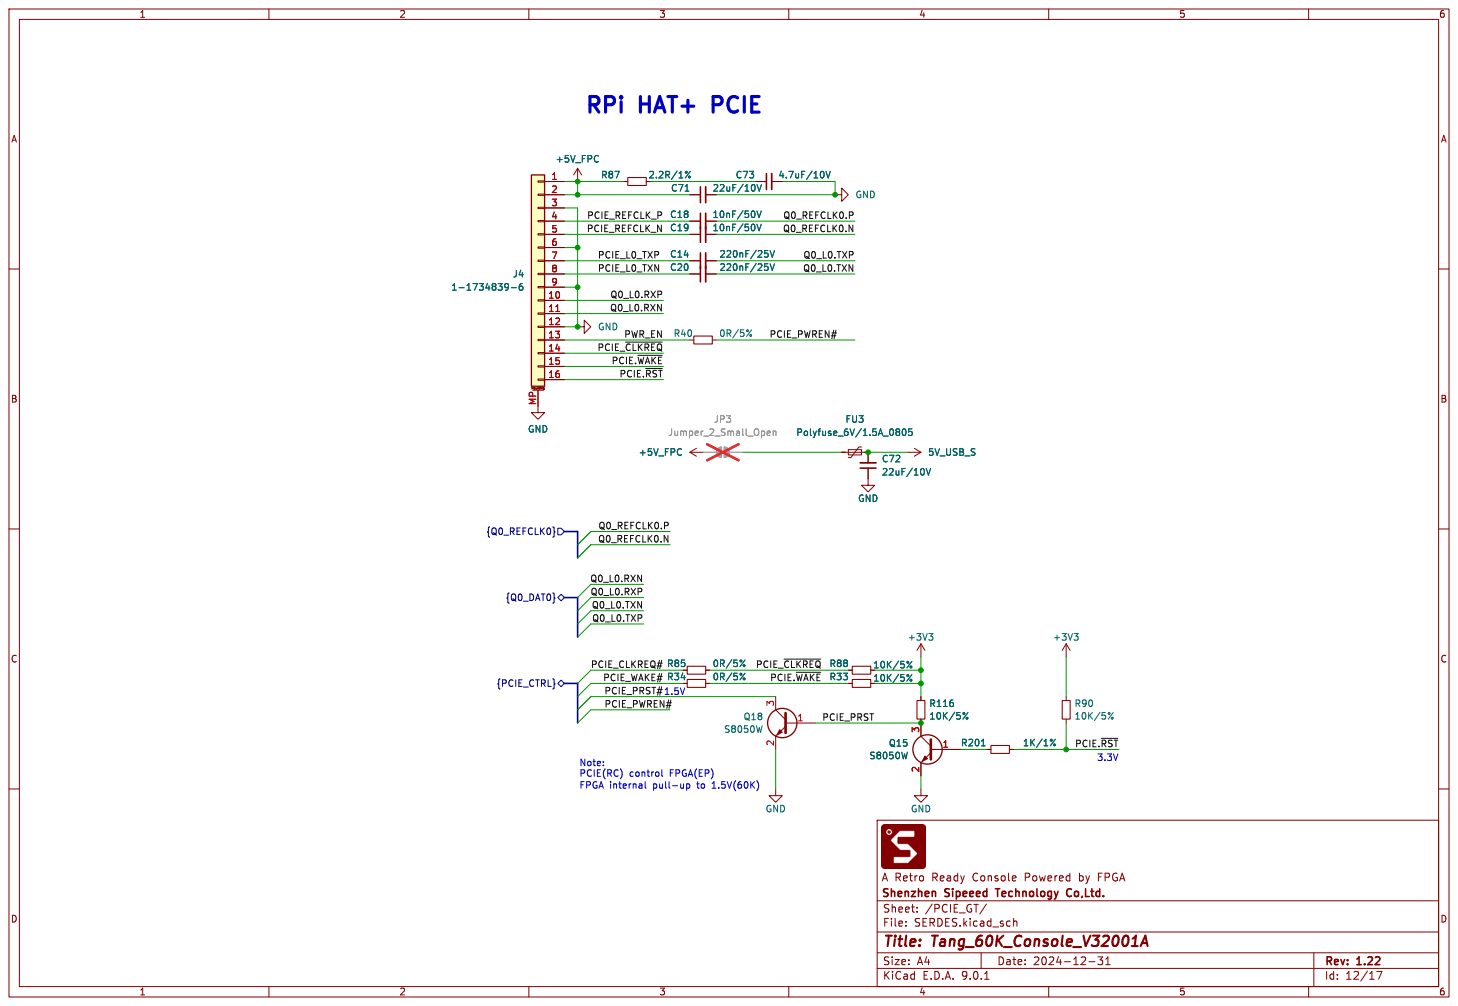
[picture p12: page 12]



4 VBUS 1 D- 2 D+ 3 SSRX- 5 SSRX+ 6 SSTX- 8 SSTX+ 9

4 VBUS 1 D- 2 D+ 3 SSRX- 5 SSRX+ 6 SSTX- 8 SSTX+ 9 R108 0R/5%

4 VBUS 1 D- 2 D+ 3 SSRX- 5 SSRX+ 6 SSTX- 8 SSTX+ 9 GNDS GND GNDS GND


Use other debugger BL616 SEL[0..1] SWITCH




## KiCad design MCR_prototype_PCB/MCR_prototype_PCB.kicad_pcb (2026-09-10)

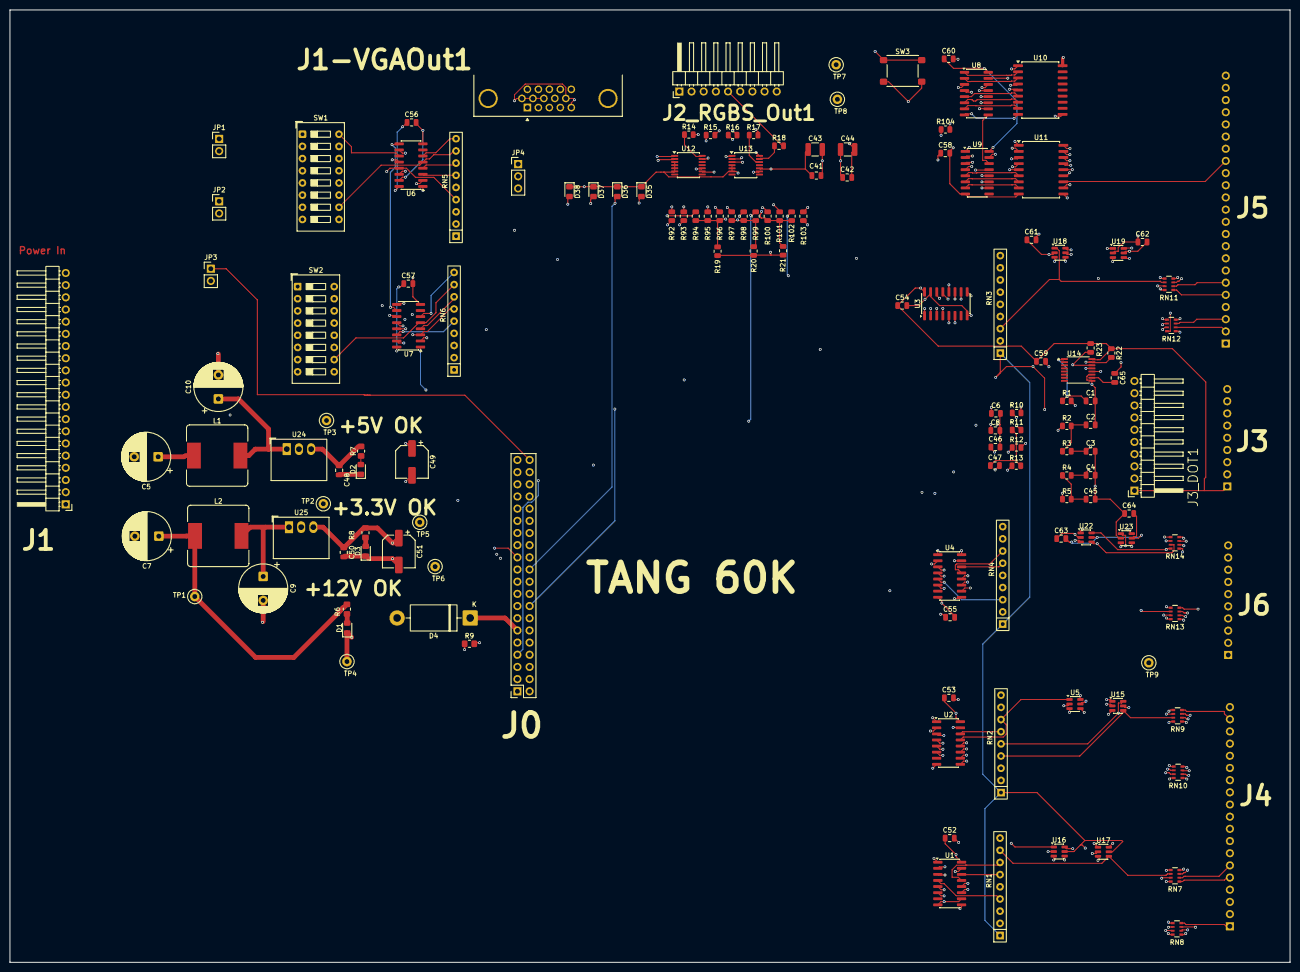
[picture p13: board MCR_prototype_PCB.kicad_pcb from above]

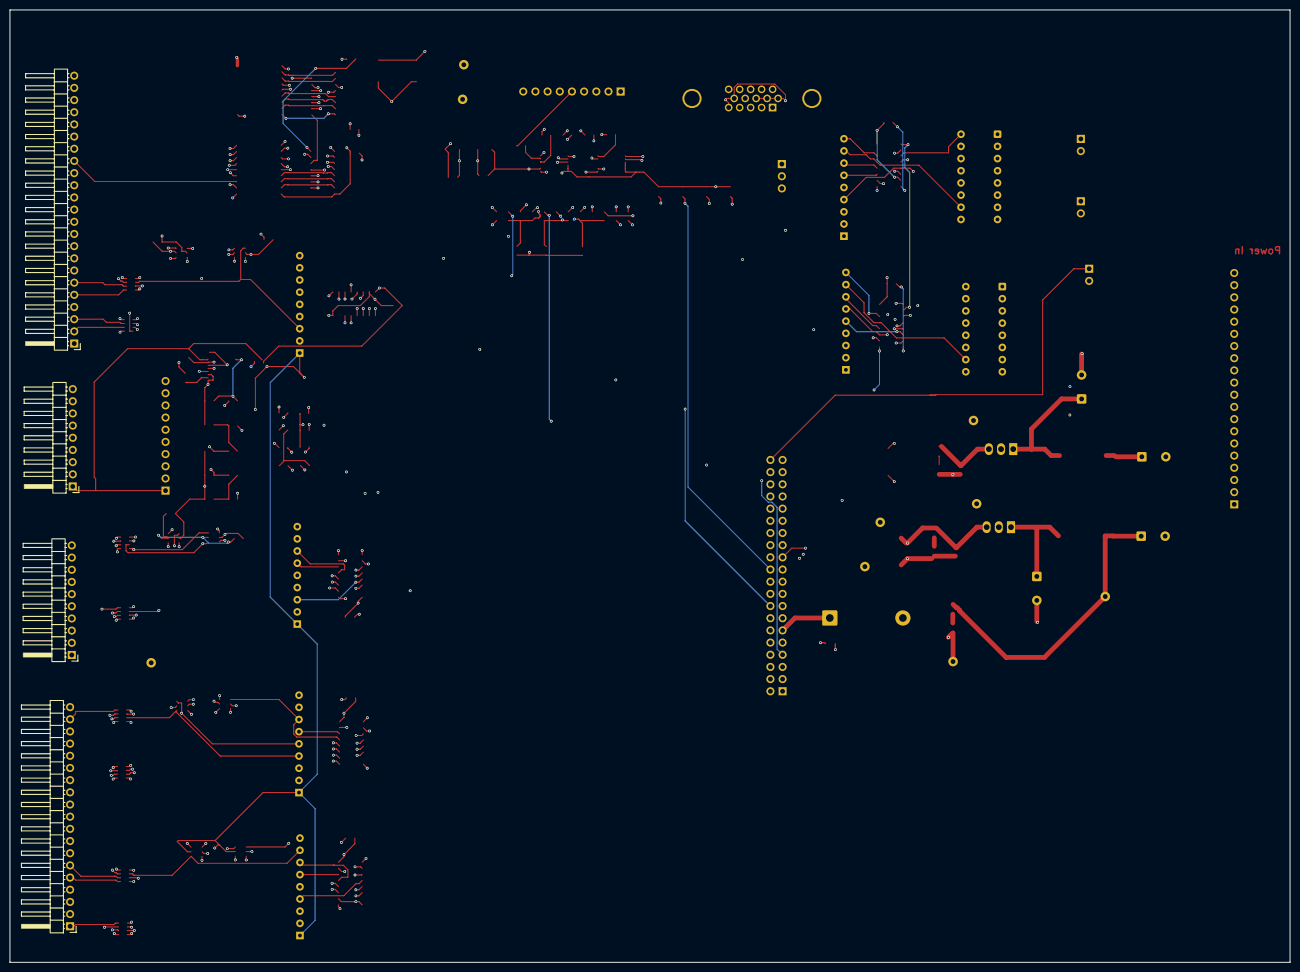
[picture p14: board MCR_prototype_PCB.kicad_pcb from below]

Board: 4 copper layers, 267.1 x 198.7 mm, 143 parts (4 on the bottom side), 183 nets.

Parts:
C1, C41, C42, C48, C50, C52, C53, C54, C55, C56, C57, C58, C59, C60, C61, C62, C63, C64, C65: 0.1 uF; C_0805_2012Metric
C2, C3, C4, C6, C8, C45, C46, C47: 0.01 uF; C_0805_2012Metric
C5, C7: 4.7 uF 50V; CP_Radial_D10.0mm_P5.00mm
C9, C10: 10 uF 50V; CP_Radial_D10.0mm_P5.00mm
C43, C44: 22 uF; C_1210_3225Metric
C49, C51: 100 uF; CP_Elec_6.3x5.4
D1, D2, D3, D35, D36, D37, D38: LED; LED_0805_2012Metric_Pad1.15x1.40mm_HandSolder
D4: 1N5822; D_DO-201AD_P15.24mm_Horizontal
J0: Conn_02x20_Odd_Even; PinSocket_2x20_P2.54mm_Vertical
J1: Conn_01x20_Pin; PinHeader_1x20_P2.54mm_Horizontal
J1-VGAOut1: DE15_Socket_HighDensity; DSUB-15-HD_Socket_Horizontal_P2.29x1.90mm_EdgePinOffset3.03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
J2_RGBS_Out1, J3: Conn_01x09_Pin; PinHeader_1x09_P2.54mm_Horizontal
J3_DOT1: Conn_01x10_Pin; PinHeader_1x10_P2.54mm_Horizontal_mirrored
J4: Conn_01x19_Pin; PinHeader_1x19_P2.54mm_Horizontal
J5: Conn_01x23_Pin; PinHeader_1x23_P2.54mm_Horizontal
J6: Conn_01x10_Pin; PinHeader_1x10_P2.54mm_Horizontal
JP1: 15 kHz Select; PinHeader_1x02_P2.54mm_Vertical
JP2: Composite Sync Select; PinHeader_1x02_P2.54mm_Vertical
JP3: Vertical Sync Inactive select; PinHeader_1x02_P2.54mm_Vertical
JP4: VGA Filter; PinHeader_1x03_P2.54mm_Vertical
L1, L2: FAUL1360-3R3MT; L_Bourns_SRR1260
R1, R2, R3, R4, R5, R10, R11, R12, R13, R22, R23, R95, R98, R101: 1k; R_0805_2012Metric
R6: 2k ohm; R_0805_2012Metric_Pad1.20x1.40mm_HandSolder
R7: 510 ohm; R_0805_2012Metric_Pad1.20x1.40mm_HandSolder
R8: 220 ohm; R_0805_2012Metric_Pad1.20x1.40mm_HandSolder
R9: 1k; R_0805_2012Metric_Pad1.20x1.40mm_HandSolder
R14, R15, R16, R17, R19, R20, R21: 75; R_0805_2012Metric
R18: 75; C_0805_2012Metric
R92, R93: 100; R_0805_2012Metric
R94, R97, R100: 510; R_0805_2012Metric
R96, R99, R102: 2k; R_0805_2012Metric
R103, R104: 10k; R_0805_2012Metric
RN1, RN2, RN3, RN4, RN5, RN6: 4.7k ohm; R_Array_SIP9
RN7, RN8, RN9, RN10, RN11, RN12, RN13, RN14: 1K Ohm; R_Array_Convex_4x0603
SW1, SW2: DSIC08LHGET; SW_DIP_SPSTx08_Slide_9.78x22.5mm_W7.62mm_P2.54mm
SW3: PTS645SM43SMTR92LFS; SW_SPST_PTS645Sx43SMTR92
TP1: +12V Input; TestPoint_Loop_D1.80mm_Drill1.0mm_Beaded
TP2: +3.3V Power; TestPoint_Loop_D1.80mm_Drill1.0mm_Beaded
TP3: +5V Power; TestPoint_Loop_D1.80mm_Drill1.0mm_Beaded
TP4: Gnd; TestPoint_Loop_D1.80mm_Drill1.0mm_Beaded
TP5: In_Clk; TestPoint_Loop_D1.80mm_Drill1.0mm_Beaded
TP6: IN_LOAD_N; TestPoint_Loop_D1.80mm_Drill1.0mm_Beaded
TP7: VID_HS; TestPoint_Loop_D1.80mm_Drill1.0mm_Beaded
TP8: VID_VS; TestPoint_Loop_D1.80mm_Drill1.0mm_Beaded
TP9: GND; TestPoint_Loop_D1.80mm_Drill1.0mm_Beaded
U1, U2, U3, U4, U6, U7: 74AHC165; SOIC-16_3.9x9.9mm_P1.27mm
U5, U15, U16, U17, U18, U19, U22, U23: SRV05-4; SOT-23-6
U8, U9: 74HC595; SOIC-16_3.9x9.9mm_P1.27mm
U10, U11: ULN2803CDWR; SOIC-18W_7.5x11.6mm_P1.27mm
U12, U13: THS7374; TSSOP-14_4.4x5mm_P0.65mm
U14: ADS7830; TSSOP-16_4.4x5mm_P0.65mm
U24: K7805-2000R3; Converter_DCDC_RECOM_R-78B-2.0_THT
U25: K7803-2000R3; Converter_DCDC_RECOM_R-78B-2.0_THT

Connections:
+3.3V: C50.1, C51.1, C52.1, C53.1, C54.1, C55.1, C56.1, C57.1, C59.1, J3.1, J3_DOT1.1, R8.1, R9.1, R22.1, R23.1, R103.1, R104.1, TP2.1 (1_1), U1.16 (VCC), U2.16 (VCC), U3.16 (VCC), U4.16 (VCC), U6.16 (VCC), U7.16 (VCC), U14.16 (VDD), U25.3 (OUT)
+5V: C41.1, C42.1, C43.1, C44.1, C48.1, C49.1, C58.1, C60.1, C61.2, C62.2, C63.2, C64.2, D4.2 (A), JP4.1 (A), R7.1, RN1.1 (common), RN2.1 (common), RN3.1 (common), RN4.1 (common), RN5.1 (common), RN6.1 (common), TP3.1 (1_1), U5.5 (VP), U8.16 (VCC), U9.16 (VCC), U12.10 (V_{S+}), U13.10 (V_{S+}), U15.5 (VP), U16.5 (VP), U17.5 (VP), U18.5 (VP), U19.5 (VP), U22.5 (VP), U23.5 (VP), U24.3 (OUT)
+12V: C5.1, C7.1, J1.18, J5.20, L1.1, L2.1, R6.1, TP1.1 (1_1), U10.10 (COM), U11.10 (COM)
/1 Plyr Move Down: J5.4, RN12.4 (R4.1)
/1 Plyr Move Left: J5.1, RN12.1 (R1.1)
/1 Plyr Move Right: J5.2, RN12.2 (R2.1)
/1 Plyr Move Up: J5.3, RN12.3 (R3.1)
ADC_A0: J0.30, U14.12 (A0)
ADC_A1: J0.29, U14.13 (A1)
ADC_SCL: J0.20, R23.2, U14.14 (SCL)
ADC_SDA: J0.19, R22.2, U14.15 (SDA)
ARD: J5.16, U11.12 (O7)
AUD_PWM_L1: J0.35, R2.1
AUD_PWM_L2: J0.1, R13.1
AUD_PWM_R1: J0.36, R5.1
AUD_PWM_R2: J0.5, R12.1
Coin_Meter: J5.21, U10.18 (O1)
GND: C1.2, C2.2, C3.2, C4.2, C5.2, C6.2, C7.2, C8.2, C9.2, C10.2, C41.2, C42.2, C43.2, C44.2, C45.2, C46.2, C47.2, C48.2, C49.2, C50.2, C51.2, C52.2, C53.2, C54.2, C55.2, C56.2, C57.2, C58.2, C59.2, C60.2, C61.1, C62.1, C63.1, C64.1, C65.1, D1.1 (K), D2.1 (K), D3.1 (K), D35.1 (K), D36.1 (K), D37.1 (K), D38.1 (K), J0.12, J1.6, J1.7, J1.10, J1.20, J1-VGAOut1.5, J1-VGAOut1.6, J1-VGAOut1.7, J1-VGAOut1.8, J1-VGAOut1.10, J2_RGBS_Out1.2, J2_RGBS_Out1.4, J2_RGBS_Out1.6, J3.3, J3.6, J3_DOT1.3, J3_DOT1.5, J3_DOT1.8, J4.9, J4.19, J5.9, J5.18, JP1.2 (B), JP2.2 (B), JP3.2 (B), JP4.3 (B), R19.2, R20.2, R21.2, SW1.1, SW1.2, SW1.3, SW1.4, SW1.5, SW1.6, SW1.7, SW1.8, SW2.1, SW2.2, SW2.3, SW2.4, SW2.5, SW2.6, SW2.7, SW2.8, SW3.1, TP4.1 (1_1), TP9.1 (1_1), U1.8 (GND), U1.10 (DS), U1.15 (~CE), U2.8 (GND), U2.15 (~CE), U3.8 (GND), U3.15 (~CE), U4.8 (GND), U4.15 (~CE), U5.2 (VN), U6.8 (GND), U6.15 (~CE), U7.8 (GND), U7.15 (~CE), U8.8 (GND), U9.8 (GND), U10.9 (GND), U11.9 (GND), U12.3 (CH3_IN), U12.4 (CH4_IN), U12.5 (GND), U12.6 (DISABLE), U13.4 (CH4_IN), U13.5 (GND), U13.6 (DISABLE), U14.9 (GND), U14.11 (COM), U15.2 (VN), U16.2 (VN), U17.2 (VN), U18.2 (VN), U19.2 (VN), U22.2 (VN), U23.2 (VN), U24.2 (GND), U25.2 (GND)
IN_CLK: J0.25, TP5.1 (1_1), U1.2 (CP), U2.2 (CP), U3.2 (CP), U4.2 (CP), U6.2 (CP), U7.2 (CP)
IN_DATA: J0.27, U7.9 (Q7)
IN_LOAD_N: J0.26, TP6.1 (1_1), U1.1 (~PL), U2.1 (~PL), U3.1 (~PL), U4.1 (~PL), U6.1 (~PL), U7.1 (~PL)
J4_Input_Stream: U2.9 (Q7), U3.10 (DS)
J5_Input_Stream: U3.9 (Q7), U4.10 (DS)
J6_Input_Stream: U4.9 (Q7), U6.10 (DS)
LED_27M: D37.2 (A), J0.23
LED_CALIB: D35.2 (A), J0.21
LED_DDR_RST: D38.2 (A), J0.24
LED_PIX: D36.2 (A), J0.22
MD0: J5.10, U11.18 (O1)
MD1: J5.11, U11.17 (O2)
MD2: J5.12, U11.16 (O3)
MD3: J5.13, U11.15 (O4)
MODE_15N: J0.37, JP1.1 (A)
unnamed: C2.1, R2.2, R3.1
unnamed: C45.1, R4.1, R5.2
unnamed: C46.1, R10.1, R12.2
unnamed: C47.1, R11.1, R13.2
unnamed: D1.2 (A), R6.2
unnamed: D2.2 (A), R7.2
unnamed: D3.2 (A), R8.2
unnamed: D4.1 (K), J0.11
unnamed: J1-VGAOut1.1, J2_RGBS_Out1.1, R16.2
unnamed: J1-VGAOut1.2, J2_RGBS_Out1.3, R17.2
unnamed: J1-VGAOut1.3, J2_RGBS_Out1.5, R18.2
unnamed: J1-VGAOut1.13, J2_RGBS_Out1.8, R14.2, TP7.1 (1_1)
unnamed: J1-VGAOut1.14, J2_RGBS_Out1.9, R15.2, TP8.1 (1_1)
unnamed: J3.2, J3_DOT1.2, R1.2
unnamed: C4.1, J3.7, J3_DOT1.6, R4.2
unnamed: C3.1, J3.9, J3_DOT1.7, R3.2
unnamed: C6.1, J3_DOT1.9, R10.2
unnamed: C8.1, J3_DOT1.10, R11.2
unnamed: J4.1, RN8.4 (R4.1)
unnamed: J4.2, RN8.3 (R3.1)
unnamed: J4.3, RN8.2 (R2.1)
unnamed: J4.4, RN8.1 (R1.1)
unnamed: J4.5, RN7.1 (R1.1)
unnamed: J4.6, RN7.2 (R2.1)
unnamed: J4.7, RN7.3 (R3.1)
unnamed: J4.8, RN7.4 (R4.1)
unnamed: J4.10, RN10.1 (R1.1)
unnamed: J4.11, RN10.2 (R2.1)
unnamed: J4.12, RN10.3 (R3.1)
unnamed: J4.13, RN10.4 (R4.1)
unnamed: J4.15, RN9.1 (R1.1)
unnamed: J4.16, RN9.2 (R2.1)
unnamed: J4.17, RN9.3 (R3.1)
unnamed: J4.18, RN9.4 (R4.1)
unnamed: J5.5, RN11.1 (R1.1)
unnamed: J5.6, RN11.2 (R2.1)
unnamed: J5.7, RN11.3 (R3.1)
unnamed: J5.8, RN11.4 (R4.1)
unnamed: J6.1, RN13.1 (R1.1)
unnamed: J6.2, RN13.2 (R2.1)
unnamed: J6.3, RN13.3 (R3.1)
unnamed: J6.4, RN13.4 (R4.1)
unnamed: J6.5, RN14.1 (R1.1)
unnamed: J6.6, RN14.2 (R2.1)
unnamed: J6.7, RN14.3 (R3.1)
unnamed: J6.9, RN14.4 (R4.1)
unnamed: JP4.2 (C), U12.9 (BYPASS), U13.9 (BYPASS)
unnamed: RN1.2 (R1), RN8.5 (R4.2), U1.6 (D7), U16.3 (IO2)
unnamed: RN1.3 (R2), RN8.6 (R3.2), U1.5 (D6), U16.1 (IO1)
unnamed: RN1.4 (R3), RN8.7 (R2.2), U1.4 (D5), U16.4 (IO3)
unnamed: RN1.5 (R4), RN8.8 (R1.2), U1.3 (D4), U16.6 (IO4)
unnamed: RN1.6 (R5), RN7.8 (R1.2), U1.14 (D3), U17.3 (IO2)
unnamed: RN1.7 (R6), RN7.7 (R2.2), U1.13 (D2), U17.1 (IO1)
unnamed: RN1.8 (R7), RN7.6 (R3.2), U1.12 (D1), U17.4 (IO3)
unnamed: RN1.9 (R8), RN7.5 (R4.2), U1.11 (D0), U17.6 (IO4)
unnamed: RN2.2 (R1), RN9.5 (R4.2), U2.6 (D7), U15.3 (IO2)
unnamed: RN2.3 (R2), RN9.6 (R3.2), U2.5 (D6), U15.1 (IO1)
unnamed: RN2.4 (R3), RN9.7 (R2.2), U2.4 (D5), U15.4 (IO3)
unnamed: RN2.5 (R4), RN9.8 (R1.2), U2.3 (D4), U15.6 (IO4)
unnamed: RN5.2 (R1), SW1.16, U6.11 (D0)
unnamed: RN5.3 (R2), SW1.15, U6.12 (D1)
unnamed: RN5.4 (R3), SW1.14, U6.13 (D2)
unnamed: RN5.5 (R4), SW1.13, U6.14 (D3)
unnamed: RN5.6 (R5), SW1.12, U6.3 (D4)
unnamed: RN5.7 (R6), SW1.11, U6.4 (D5)
unnamed: RN5.8 (R7), SW1.10, U6.5 (D6)
unnamed: RN5.9 (R8), SW1.9, U6.6 (D7)
unnamed: RN6.2 (R1), SW2.16, U7.11 (D0)
unnamed: RN6.3 (R2), SW2.15, U7.12 (D1)
unnamed: RN6.4 (R3), SW2.14, U7.13 (D2)
unnamed: RN6.5 (R4), SW2.13, U7.14 (D3)
unnamed: RN6.6 (R5), SW2.12, U7.3 (D4)
unnamed: RN6.7 (R6), SW2.11, U7.4 (D5)
unnamed: RN6.8 (R7), SW2.10, U7.5 (D6)
unnamed: RN6.9 (R8), SW2.9, U7.6 (D7)
unnamed: RN2.9 (R8), RN10.8 (R1.2), U2.11 (D0), U5.6 (IO4)
unnamed: RN2.8 (R7), RN10.7 (R2.2), U2.12 (D1), U5.4 (IO3)
unnamed: RN2.7 (R6), RN10.6 (R3.2), U2.13 (D2), U5.1 (IO1)
unnamed: RN2.6 (R5), RN10.5 (R4.2), U2.14 (D3), U5.3 (IO2)
unnamed: RN3.5 (R4), RN11.8 (R1.2), U3.3 (D4), U18.6 (IO4)
unnamed: RN3.4 (R3), RN11.7 (R2.2), U3.4 (D5), U18.4 (IO3)
unnamed: RN3.3 (R2), RN11.6 (R3.2), U3.5 (D6), U18.1 (IO1)
unnamed: RN3.2 (R1), RN11.5 (R4.2), U3.6 (D7), U18.3 (IO2)
unnamed: RN3.9 (R8), RN12.8 (R1.2), U3.11 (D0), U19.6 (IO4)
unnamed: RN3.8 (R7), RN12.7 (R2.2), U3.12 (D1), U19.4 (IO3)
unnamed: RN3.7 (R6), RN12.6 (R3.2), U3.13 (D2), U19.1 (IO1)
unnamed: RN3.6 (R5), RN12.5 (R4.2), U3.14 (D3), U19.3 (IO2)
unnamed: RN4.9 (R8), RN13.8 (R1.2), U4.11 (D0), U23.6 (IO4)
unnamed: RN4.8 (R7), RN13.7 (R2.2), U4.12 (D1), U23.4 (IO3)
unnamed: RN4.7 (R6), RN13.6 (R3.2), U4.13 (D2), U23.1 (IO1)
unnamed: RN4.6 (R5), RN13.5 (R4.2), U4.14 (D3), U23.3 (IO2)
unnamed: RN4.5 (R4), RN14.8 (R1.2), U4.3 (D4), U22.6 (IO4)
unnamed: RN4.4 (R3), RN14.7 (R2.2), U4.4 (D5), U22.4 (IO3)
unnamed: RN4.3 (R2), RN14.6 (R3.2), U4.5 (D6), U22.1 (IO1)
unnamed: RN4.2 (R1), RN14.5 (R4.2), U4.6 (D7), U22.3 (IO2)
unnamed: U1.9 (Q7), U2.10 (DS)
unnamed: U8.9 (QH'), U9.14 (SER)
unnamed: U8.15 (QA), U10.1 (I1)
unnamed: U8.1 (QB), U10.2 (I2)
unnamed: U8.2 (QC), U10.3 (I3)
unnamed: U8.3 (QD), U10.4 (I4)
unnamed: U8.4 (QE), U10.5 (I5)
unnamed: U8.5 (QF), U10.6 (I6)
unnamed: U8.6 (QG), U10.7 (I7)
unnamed: U8.7 (QH), U10.8 (I8)
unnamed: U9.15 (QA), U11.1 (I1)
unnamed: U9.1 (QB), U11.2 (I2)
unnamed: U9.2 (QC), U11.3 (I3)
unnamed: U9.3 (QD), U11.4 (I4)
unnamed: U9.4 (QE), U11.5 (I5)
unnamed: U9.5 (QF), U11.6 (I6)
unnamed: U9.6 (QG), U11.7 (I7)
unnamed: U9.7 (QH), U11.8 (I8)
unnamed: R92.2, U12.1 (CH1_IN)
unnamed: R14.1, U12.14 (CH1_OUT)
unnamed: R93.2, U12.2 (CH2_IN)
unnamed: R15.1, U12.13 (CH2_OUT)
unnamed: R19.1, R94.1, R95.1, R96.1, U13.1 (CH1_IN)
unnamed: R16.1, U13.14 (CH1_OUT)
unnamed: R20.1, R97.1, R98.1, R99.1, U13.2 (CH2_IN)
unnamed: R18.1, U13.13 (CH2_OUT)
unnamed: R21.1, R100.1, R101.1, R102.1, U13.3 (CH3_IN)
unnamed: R17.1, U13.12 (CH3_OUT)
unnamed: C1.1, R1.1, U14.1 (CH0)
unnamed: C65.2, U14.10 (REFin/REFout)
unnamed: C10.1, L1.2, U24.1 (IN)
unnamed: C9.1, L2.2, U25.1 (IN)
Out_Clear: J0.33, R104.2, U8.10 (~SRCLR), U9.10 (~SRCLR)
Out_Clock: J0.28, U8.11 (SRCLK), U9.11 (SRCLK)
Out_Data: J0.31, U8.14 (SER)
Out_En_N: J0.34, R103.2, U8.13 (~OE), U9.13 (~OE)
Out_Latch: J0.32, U8.12 (RCLK), U9.12 (RCLK)
SEL: J5.17, U11.11 (O8)
ST0: J5.14, U11.14 (O5)
ST1: J5.15, U11.13 (O6)
SW1_Input_Stream: U6.9 (Q7), U7.10 (DS)
SYNC_CSYNC_N: J0.39, JP2.1 (A)
SYNC_VSOFF_N: J0.40, JP3.1 (A)
Service Switch: J0.9, R9.2, SW3.2
VID_B1: J0.6, R99.2
VID_B2: J0.7, R98.2
VID_B3: J0.8, R97.2
VID_G1: J0.14, R102.2
VID_G2: J0.15, R101.2
VID_G3: J0.16, R100.2
VID_HS: J0.17, R92.1
VID_R1: J0.2, R96.2
VID_R2: J0.3, R95.2
VID_R3: J0.4, R94.2
VID_VS: J0.18, R93.1

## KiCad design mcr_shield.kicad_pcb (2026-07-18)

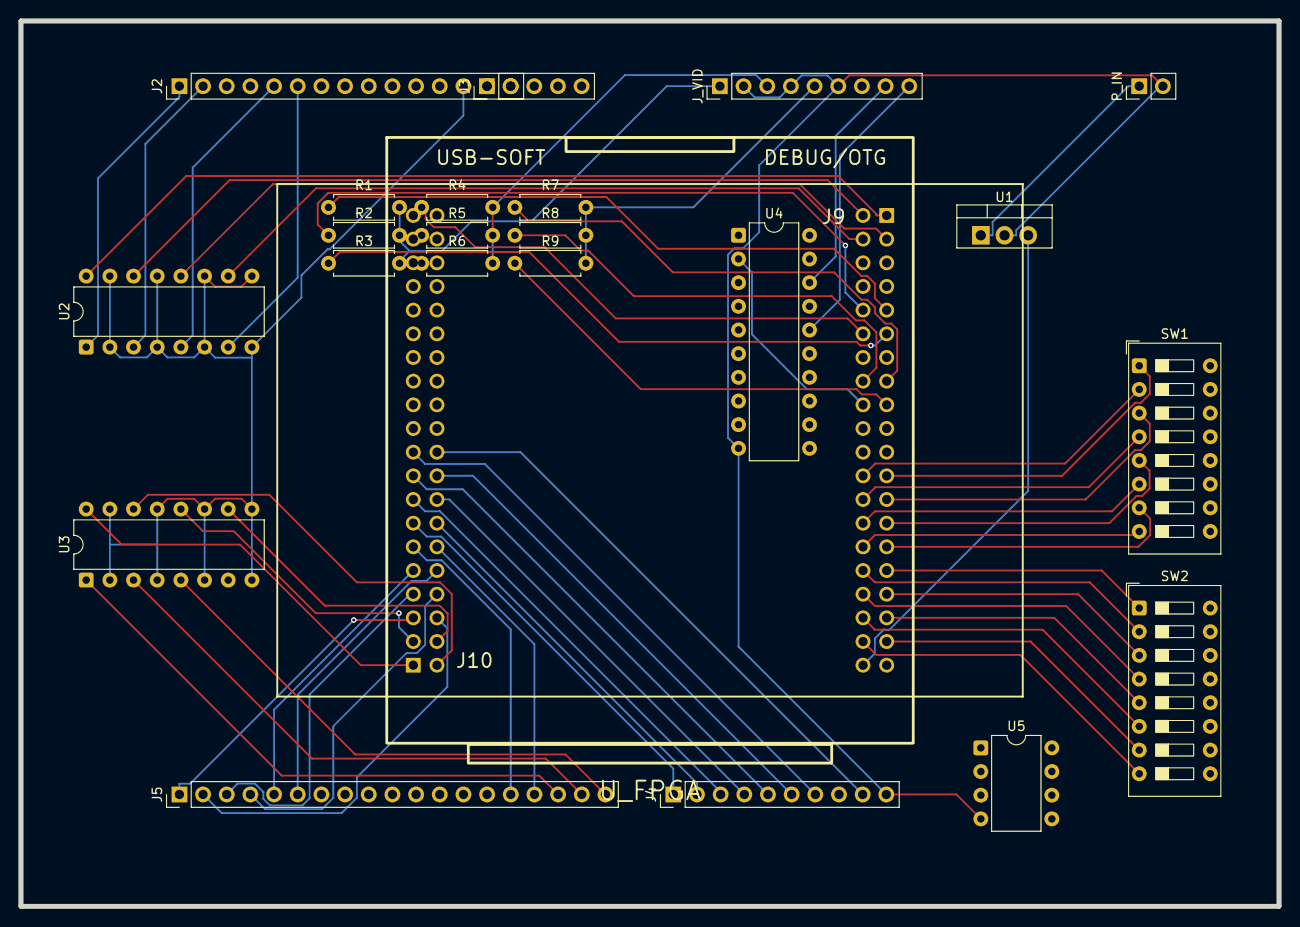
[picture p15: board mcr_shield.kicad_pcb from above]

Board: 2 copper layers, 135.0 x 95.0 mm, 23 parts (0 on the bottom side), 66 nets.

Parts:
J2: MCR_P1_Controls; PinHeader_1x15_P2.54mm_Vertical
J3: MCR_System_Coin; PinHeader_1x05_P2.54mm_Vertical
J4: MCR_Opt_X_Dial; PinHeader_1x10_P2.54mm_Vertical
J5: MCR_P2_Controls; PinHeader_1x19_P2.54mm_Vertical
J_VID: MCR_Video_Out; PinHeader_1x09_P2.54mm_Vertical
P_IN: Power_+12V_GND; PinHeader_1x02_P2.54mm_Vertical
R1: 3.9k_Red_LSB; R_Axial_DIN0207_L6.3mm_D2.5mm_P7.62mm_Horizontal
R2: 2.0k_Red_Mid; R_Axial_DIN0207_L6.3mm_D2.5mm_P7.62mm_Horizontal
R3: 1.0k_Red_MSB; R_Axial_DIN0207_L6.3mm_D2.5mm_P7.62mm_Horizontal
R4: 3.9k_Green_LSB; R_Axial_DIN0207_L6.3mm_D2.5mm_P7.62mm_Horizontal
R5: 2.0k_Green_Mid; R_Axial_DIN0207_L6.3mm_D2.5mm_P7.62mm_Horizontal
R6: 1.0k_Green_MSB; R_Axial_DIN0207_L6.3mm_D2.5mm_P7.62mm_Horizontal
R7: 3.9k_Blue_LSB; R_Axial_DIN0207_L6.3mm_D2.5mm_P7.62mm_Horizontal
R8: 2.0k_Blue_Mid; R_Axial_DIN0207_L6.3mm_D2.5mm_P7.62mm_Horizontal
R9: 1.0k_Blue_MSB; R_Axial_DIN0207_L6.3mm_D2.5mm_P7.62mm_Horizontal
SW1: Game_Selector; SW_DIP_SPSTx08_Slide_9.78x22.5mm_W7.62mm_P2.54mm
SW2: Cabinet_Options; SW_DIP_SPSTx08_Slide_9.78x22.5mm_W7.62mm_P2.54mm
U1: Buck_Regulator; TO-220-3_Vertical
U2: Optocoupler_P1; DIP-16_W7.62mm
U3: Optocoupler_Sys; DIP-16_W7.62mm
U4: Sync_Buffer; DIP-20_W7.62mm
U5: Audio_Amplifier; DIP-8_W7.62mm
U_FPGA: TangMega138K_Console

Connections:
5V_REGULATED: U1.3, U_FPGA.J9_40
12V_POWER: P_IN.1, U1.1
BTN_FIRE: U2.12, U_FPGA.J9_3
BTN_LEFT: U2.16, U_FPGA.J9_1
BTN_RIGHT: U2.14, U_FPGA.J9_2
BTN_SHIELD: U2.10, U_FPGA.J9_4
CAB_BLUE: J_VID.5, R7.2, R8.2, R9.2
CAB_BTN_FIRE: J2.5, U2.5
CAB_BTN_LEFT: J2.1, U2.1
CAB_BTN_RIGHT: J2.2, U2.3
CAB_BTN_SHIELD: J2.6, U2.7
CAB_GREEN: J_VID.3, R4.2, R5.2, R6.2
CAB_HSYNC: J_VID.8, U4.18
CAB_P2_FIRE: J5.19, U3.5
CAB_P2_LEFT: J5.17, U3.1
CAB_P2_RIGHT: J5.18, U3.3
CAB_RED: J_VID.1, R1.2, R2.2, R3.2
CAB_VSYNC: J_VID.9, U4.16
FPGA_B0: R7.1, U_FPGA.J9_15
FPGA_B1: R8.1, U_FPGA.J9_16
FPGA_B2: R9.1, U_FPGA.J9_17
FPGA_G0: R4.1, U_FPGA.J9_12
FPGA_G1: R5.1, U_FPGA.J9_13
FPGA_G2: R6.1, U_FPGA.J9_14
FPGA_HSYNC: U4.2, U_FPGA.J9_18
FPGA_R0: R1.1, U_FPGA.J9_9
FPGA_R1: R2.1, U_FPGA.J9_10
FPGA_R2: R3.1, U_FPGA.J9_11
FPGA_VSYNC: U4.4, U_FPGA.J9_19
GAME_OPT0: SW2.1, U_FPGA.J9_31
GAME_OPT1: SW2.2, U_FPGA.J9_32
GAME_OPT2: SW2.3, U_FPGA.J9_33
GAME_OPT3: SW2.4, U_FPGA.J9_34
GAME_OPT4: SW2.5, U_FPGA.J9_35
GAME_OPT5: SW2.6, U_FPGA.J9_36
GAME_OPT6: SW2.7, U_FPGA.J9_37
GAME_OPT7: SW2.8, U_FPGA.J9_38
GAME_SEL0: SW1.1, U_FPGA.J9_23
GAME_SEL1: SW1.2, U_FPGA.J9_24
GAME_SEL2: SW1.3, U_FPGA.J9_25
GAME_SEL3: SW1.4, U_FPGA.J9_26
GAME_SEL4: SW1.5, U_FPGA.J9_27
GAME_SEL5: SW1.6, U_FPGA.J9_28
GAME_SEL6: SW1.7, U_FPGA.J9_29
GAME_SEL7: SW1.8, U_FPGA.J9_30
GND: J2.13, J4.10, J_VID.2, J_VID.4, J_VID.6, P_IN.2, U1.2, U2.2, U2.4, U2.6, U2.8, U2.9, U2.11, U2.13, U2.15, U3.2, U3.4, U3.6, U3.8, U3.9, U3.11, U3.13, U3.15, U4.10, U5.4
P2_FIRE: U3.12, U_FPGA.J10_3
P2_LEFT: U3.16, U_FPGA.J10_1
P2_RIGHT: U3.14, U_FPGA.J10_2
P2_SHIELD: U3.10, U_FPGA.J10_4
P2_TRACK_D0: J5.1, U_FPGA.J10_5
P2_TRACK_D1: J5.2, U_FPGA.J10_6
P2_TRACK_D2: J5.3, U_FPGA.J10_7
P2_TRACK_D3: J5.4, U_FPGA.J10_8
P2_TRACK_D4: J5.5, U_FPGA.J10_9
P2_TRACK_D5: J5.6, U_FPGA.J10_10
P2_TRACK_D6: J5.15, U_FPGA.J10_11
P2_TRACK_D7: J5.16, U_FPGA.J10_12
SPINNER_D0: J4.1, U_FPGA.J10_13
SPINNER_D1: J4.2, U_FPGA.J10_14
SPINNER_D2: J4.3, U_FPGA.J10_15
SPINNER_D3: J4.4, U_FPGA.J10_16
SPINNER_D4: J4.5, U_FPGA.J10_17
SPINNER_D5: J4.6, U_FPGA.J10_18
SPINNER_D6: J4.7, U_FPGA.J10_19
SPINNER_D7: J4.9, U_FPGA.J10_20

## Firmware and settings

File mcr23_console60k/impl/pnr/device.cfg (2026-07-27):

set JTAG regular_io = false
set SSPI regular_io = true
set MSPI regular_io = true
set READY regular_io = true
set DONE regular_io = true
set I2C regular_io = true
set CPU regular_io = true
set CRC_check = true
set compress = false
set encryption = false
set security_bit_enable = true
set bsram_init_fuse_print = true
set background_programming = off
set secure_mode = false
set program_done_bypass = false
set wake_up = 0
set format = binary
set power_on_reset_monitor = true
set multiboot_spi_flash_address = 0x000000
set multiboot_address_width = 24
set multiboot_mode = single
set seu_handler = false
set ext_cclk = false
set vccx = 3.3
set vcc = 0.9
set unused_pin = default

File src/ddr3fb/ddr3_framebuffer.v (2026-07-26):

// DDR3-backed framebuffer for Tang Mega 60K and Tang Console 60K
// nand2mario, March 2025
//
// - A framebuffer of any size smaller than 1280x720, backed by a single 16-bit 
//   DDR3 chip. The image is automatically upscaled to 1280x720 and displayed on HDMI.
// - Color depth supported: 12, 15, 18, and 24 bits.
// - Dynamic change of framebuffer size is supported. After change the upscaling
//   logic will adapt to the new size.
// - Image is updated by vsync (`fb_vsync`) and then streaming every pixel (`fb_data` 
//   and `fb_we`).
// - Resource usage: 16 BRAMs, ~3000 LUTs, ~3000 REGs, including DDR3 and HDMI IPs.
//
// Internals,
// - Gowin DDR3 controller IP is used to access DDR3. Accesses are done in 4 pixel 
//   chunks (8x 16-bit words). Each pixel is max 32 bits.
// - 720p timings: 
//      1650=1280 + 110(front porch) + 40(sync) + 220(back porch)
//      750 =720  +   5(front porch) +  5(sync)  + 20(back porch)
//   https://projectf.io/posts/video-timings-vga-720p-1080p/#hd-1280x720-60-hz
// - Pixels are read from DDR3 32 pixels in advance, as DDR3 controller's read latency 
//   is about 22 cycles.
//   x                                0  4  8   ...   WIDTH-36 ... WIDTH
//   prefetch  0  4  8 12 16 20 24 28 32 36 40        WIDTH-4
// - Writes are handled in 4 pixel chunks too. Whenever we have 4 pixels
//   accumulated, we write them to DDR3. Reading takes precedence over writing.
// LOCAL MODIFICATIONS (not upstream gbatang):
//   * DVI_MODE parameter - 1 strips HDMI audio/infoframe packets and sends
//     plain DVI, for displays that refuse our packet layer.
//   * hclk_dbg output - the HDMI pixel clock (pll_hdmi clkout1). This is the
//     clock that actually drives the TMDS pins; clk_out/clk_x1 comes from the
//     DDR3 controller instead, so watching clk_x1 does NOT prove the HDMI
//     clock chain is alive.
module ddr3_framebuffer #(
    parameter WIDTH = 640,           // multiples of 4
    parameter HEIGHT = 480, 
    parameter COLOR_BITS = 18,       // RGB666
    parameter PREFETCH_DELAY = 40,   // buffer is 16 pixels, so 40 accommodates any delay between 24-40 cycles
    parameter DVI_MODE = 0           // 1 = plain DVI (no audio / infoframes)
)(
    output              hclk_dbg,    // HDMI pixel clock (pll_hdmi ODIV1)
    output              hclk5_dbg,   // HDMI 5x serial clock (pll_hdmi ODIV0)
    input               clk_27,      // 27Mhz input clock
    input               clk_g,       // 50Mhz crystal
    input               pll_lock_27,
    input               rst_n,
    output              clk_out,     // 74.25Mhz pixel clock. could be used by user logic
    output              ddr_rst,     // output reset signal for clk_out
    output              init_calib_complete,

    // Framebuffer interface
    input               clk,         // any clock <= 74.25Mhz (or `clk_out`)
    input [10:0]        fb_width,    // actual width of the framebuffer
    input [9:0]         fb_height,   // actual height of the framebuffer
    input [10:0]        disp_width,  // display width to upscale to (e.g. 960 for 4:3 aspect ratio, 1080 for 3:2 aspect ratio)
    input               fb_vsync,    // vertical sync signal
    input               fb_we,       // update a pixel and move to next pixel
    input [COLOR_BITS-1:0] fb_data,  // pixel data
    input [5:0]         ddr_prefetch_delay,    // dynamic DDR3 prefetch delay (1-63, default PREFETCH_DELAY), larger if memory pressure is higher 

    input [15:0]        sound_left,
    input [15:0]        sound_right,

    // DDR3 interface
    output [14:0]       ddr_addr,   
    output [3-1:0]      ddr_bank,       
    output              ddr_cs,
    output              ddr_ras,
    output              ddr_cas,
    output              ddr_we,
    output              ddr_ck,
    output              ddr_ck_n,
    output              ddr_cke,
    output              ddr_odt,
    output              ddr_reset_n,
    output [2-1:0]      ddr_dm,
    inout  [16-1:0]     ddr_dq,
    inout  [2-1:0]      ddr_dqs,     
    inout  [2-1:0]      ddr_dqs_n, 

    // HDMI output
	output              tmds_clk_n,
	output              tmds_clk_p,
	output [2:0]        tmds_d_n,
	output [2:0]        tmds_d_p
);

/////////////////////////////////////////////////////////////////////
// Clocks
wire hclk, hclk5;
assign hclk_dbg = hclk;
assign hclk5_dbg = hclk5;
wire memory_clk;
wire clk_x1 /* synthesis syn_keep=1 */;
assign clk_out = clk_x1;
wire pll_lock;

// dynamic reconfiguration port from DDR controller to framebuffer PLL
reg wr;     // for mDRP
wire mdrp_inc;
wire [1:0] mdrp_op;
wire [7:0] mdrp_wdata;
wire [7:0] mdrp_rdata;
wire pll_stop;
reg pll_stop_r;

// 74.25   pixel clock
// 371.25  5x pixel clock
// 297     DDR3 clock
pll_ddr3 pll_ddr3_inst(
    .lock(pll_lock), 
    .clkout0(), 
//    .clkout1(), 
    .clkout2(memory_clk), 
    .clkin(clk_27), 
    .reset(~pll_lock_27),
    .mdclk(clk_g), 
    .mdopc(mdrp_op),        // 0: nop, 1: write, 2: read
    .mdainc(mdrp_inc),      // increment register address
    .mdwdi(mdrp_wdata),     // data to be written
    .mdrdo(mdrp_rdata)      // data read from register
);

// LOCAL MODIFICATION: HDMI clocks are now a single chain, NESTang-style:
// 27MHz -> gowin_pll_hdmi -> hclk5 (371.25) -> CLKDIV/5 -> hclk (74.25).
// The upstream arrangement (pixel clock = clk_x1 from the DDR3 controller,
// serial clock = a second PLL fed from clk_x1) leaves the OSER10 PCLK/FCLK
// phase relationship to routing luck; it produced no usable TMDS on our
// board even in a minimal design, while this chain displays (see
// diag/nes_video_selftest). The scanout still runs on clk_x1; pixels cross
// into hclk through a shadow-raster + async FIFO below - safe because both
// clocks descend from the same 27MHz reference and cannot drift.
gowin_pll_hdmi pll_hdmi27_inst(
    .clkin(clk_27),
    .clkout(hclk5),
    .lock()
);
CLKDIV #(.DIV_MODE(5)) hclk_div (
    .CLKOUT(hclk), .HCLKIN(hclk5), .RESETN(rst_n), .CALIB(1'b0)
);

reg mdrp_wr;
reg [7:0] pll_stop_count;
pll_mDRP_intf u_pll_mDRP_intf(
    .clk(clk_g),
    .rst_n(1'b1),
    .pll_lock(pll_lock),
    .wr(mdrp_wr),
    .mdrp_inc(mdrp_inc),
    .mdrp_op(mdrp_op),
    .mdrp_wdata(mdrp_wdata),
    .mdrp_rdata(mdrp_rdata)
);    

always@(posedge clk_g) begin
    pll_stop_r <= pll_stop;
    mdrp_wr <= pll_stop ^ pll_stop_r;
    if (pll_stop_r && !pll_stop && pll_stop_count != 8'hff) begin
        pll_stop_count <= pll_stop_count + 1;
    end
end

/////////////////////////////////////////////////////////////////////
// DDR3 controller

// A single 16-bit 4Gb DDR3 memory chip
wire           app_rdy;             // command and data
reg            app_en;
reg    [2:0]   app_cmd;
reg   [27:0]   app_addr;        

wire           app_wdf_rdy;         // write data
reg            app_wdf_wren;
wire  [15:0]   app_wdf_mask = 0;
wire           app_wdf_end = 1; 
reg  [127:0]   app_wdf_data;
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

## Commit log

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2026-07-11 Fix ROM hex file copying paths, add debug LEDs to CST, and verify clean compilation without sweeps
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2026-07-11 Fix TMDS encoder bug where sync control symbols were routed to q_out instead of dout during blanking
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2026-07-18 Tang Console 60K bring-up: USB gamepad, multi-game configs, VGA out, DDR3 framebuffer (WIP)
    Backport the working Primer 25K design to the Console 60K and grow it:
    - Console 60K port verified on hardware: pins cross-checked against
    nand2mario nestang/snestang/gbatang and the Sipeed 32001A/C schematics
    (J10 header ball map extracted; docs/pinrefs/ carries the references).
    - USB HID gamepad on USB port 1 (vendored nand2mario usb_hid_host + 12MHz
    PLLA); board keys act as reset/coin.
    - Per-game build configs via merge_roms.py-generated game_config.vh:
    Domino Man, Tron (spinner via MiSTer spinner.sv on pad X/Y), Satan's
    Hollow - input/DIP maps verified against MAME mcr.cpp (incl. the Do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
    [mcr_shield.kicad_pcb]
2026-07-18 merge_roms: fail loudly when a ROM zip is missing
    Previously a missing roms/<game>.zip printed an error but still wrote
    game_config.vh, so the build would pair one game's input/DIP map with
    whatever hex files happened to be left over. Now the merge helpers report
    success and main exits 1 without touching game_config.vh.
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2026-07-19 Phase A part 1: SD card reader, ROM loader, pack builder (simulated)
    Gateware for loading a game's ROMs from SD at boot instead of baking them
    into BRAM at synthesis:
    - sd_spi_phy.sv byte-level SPI master (mode 0), runtime clock divider so
    init runs at ~250kHz and transfers at ~10MHz
    - sd_reader.sv CMD0/CMD8/ACMD41/CMD58 init (handles SDHC block vs SDSC
    byte addressing), CMD17 block streaming, timeouts on every poll
    - rom_loader.sv checks the pack header, streams a 128KB slot onto the
    core's ROM download bus, raises `error` on a missing/foreign card so the
    product can show a status code instead of a black screen
    All of it verified under Verilator against a behavioural SD card mo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
2026-07-19 Phase A part 2: wire the SD ROM loader into the 60K top
    The SD path is now in the bitstream, with the baked-in ROMs kept as a
    fallback so debugging never loses a picture:
    - dpram ROM mode becomes an initialised dual-port RAM: INIT_FILE is the
    power-on default and port B takes downloads. Verified no regression -
    the Tron build is still BSRAM 83/118 with the loader absent.
    - mcr2.vhd download decode extended for the background planes and tightened
    so sprites no longer claim the sound region:
    0x00000 CPU | 0x10000 sound | 0x14000 sprites | 0x1C000/0x1E000 bg
    - top instantiates sd_reader + rom_loader, holds the core in reset until
    the load finishes OR the loader gives up (no card /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
2026-07-19 Record cocktail-mode pin impact: DIP is free, but J6/IP4 is unpinned
    Checked the pin map against what cocktail actually needs:
    - the cocktail DIP costs no pins (SW2-3 already allocated; the 74HC165
    chain is a fixed 3 pins for up to 16 switches)
    - cocktail P2 controls for Tron/Domino arrive on IP2 = J5 1-8, and all 11
    J5 lines are already allocated in section 4b
    - the real gap is IP4 / J6, which is not pinned at all: Wacko's cocktail
    joystick, Two Tigers' P2 dial and - crucially - Kozmik Kroozr's analogue
    stick Y axis, which is needed in UPRIGHT play too. The 8 reserved J10
    pins can cover it but J6's cabinet wiring is undocumented in the master
    pinout PDF.
    - IP3 is not purely DIP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
2026-07-19 Fix HDMI losing sync: never gate video on ROM loading
    The DDR3 framebuffer took its reset from core_reset, and core_reset was
    changed to wait for rom_ready when the SD loader went in. So all HDMI output
    was held in reset until the loader finished - and with a card present that
    stalls anywhere, video never starts and the monitor never syncs. This is why
    HDMI worked before the loader and not after.
    Wrong in principle too: video must come up independently of ROM loading, or
    a load problem leaves nothing to diagnose from - the exact rule the shield
    spec states and this violated.
    - framebuffer now resets from the power-on counter only (core_reset_raw)
    - rom_loader gains a ~1.7s watchdog so no c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
2026-07-20 Rebuild all six games with the analog sync fix
    Every game now carries the three hardware-driven fixes: analog sync/blank
    aligned to the core's RGB pipeline lag (left-edge cleanup), framebuffer
    reset decoupled from ROM loading (HDMI no longer depends on the SD card),
    and the loader watchdog.
    All clean, BSRAM 91/118, setup slack: domino +1.03, shollow +2.87,
    wacko +2.43, kroozr +0.33, twotiger +2.87, tron +1.13 ns. Satan's Hollow
    gets a flashable bitstream for the first time - all six MCR-2 games are now
    prebuilt in bitstreams/.
    cap_delay still defaults to 13; the tuned value from hardware will be
    hardcoded as CAP_DELAY_DEFAULT once known.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
2026-07-20 Default 15 kHz to separate H/V sync; rebuild all six games
    Confirmed on hardware: the LCD that was dropping its entire green channel at
    15 kHz was mis-detecting the sync format, not losing a signal. Separate H and
    V sync fixes it - and that is also what a real MCR cabinet expects (Video
    connector pins 8 and 9), so the authentic format and the working one are the
    same. Composite sync stays available on the J10-39 strap for an OSSC /
    RetroTink or an SOG-wired monitor.
    Two findings recorded in the docs and code comments:
    - a mis-detected sync format looks exactly like a dead colour channel
    (greys go magenta, red and blue unaffected), which sends you hunting for a
    broken wire that does not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
2026-07-20 Drive the dock's HDMI enable (hpd_en, K13) instead of leaving it floating
    TangCore displays over HDMI on the same cable, input and monitor while our
    bitstreams do not, and every stage inside the FPGA checks out: pll_hdmi
    locked at exactly 74.25MHz (confirmed by the beacon heartbeat), hclk5 routed
    on HCLK to BANK3/4/5 where the TMDS pins live, three OSER10 serializers
    present, pins placed as LVCMOS33D differential pairs with correct polarity,
    HDMI reset released, and plain DVI mode making no difference.
    That leaves board-level differences. Sipeed's own NEO_DOCK example drives
    K13 (hpd_en) as an output at DRIVE=12; we left it unassigned, i.e. an input
    tri-stated with a weak internal pull-up.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
2026-07-20 Constrain the 371MHz TMDS serial clock (hclk5)
    The HDMI self-test was decisive: our own dvi_tx encoder driving 640x480
    colour bars works on the same pins, cable and monitor, while the gbatang
    framebuffer's 720p output shows nothing. So the board, the connector and our
    gateware are all fine - the fault is specific to that stack at 371.25MHz.
    Our SDC constrained clk4x and clk1x but said nothing about hclk5, inherited
    from gbatang where those lines ship commented out. The tool therefore never
    knew the OSER10 TMDS serializers run at 371.25MHz and placed those paths
    with no timing requirement at all. That fits every observation: PLL locked,
    clock frequency measured correct, serializers present,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
2026-07-20 Add nes_video_selftest: NESTang's clock topology + our HDMI stack, 720p bars
    fb_selftest (gbatang framebuffer alone) is black on this board, while
    hdmi_selftest (our dvi_tx encoder at 640x480) displays - so the fault is in
    the gbatang stack, and the architectural difference is now identified from
    NESTang's source:
    NESTang: 27MHz -> PLL -> hclk5 371.25 -> CLKDIV/5 -> hclk 74.25
    (one chain: OSER10 PCLK/FCLK phase-locked by construction)
    gbatang: pixel clock = clk_x1 from the DDR3 controller,
    serial clock = separate PLL fed from clk_x1
    (cross-PLL pair: phase at the serializer is whatever routing
    delivers - works on the author's builds, fail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
2026-07-20 Fix the synced-black HDMI: declarations must precede use on Gowin
    The pixel bridge declared rgb_out and hdmi_active BELOW their first use.
    Gowin turns use-before-declaration into an implicit 1-bit wire with only a
    warning: the hdmi encoder's 24-bit rgb input became one floating bit
    (constant black), hdmi_active was left driverless, and the pixel FIFO was
    swept as dead logic. Result: perfect sync, pure black, zero build errors -
    with the synthesis log announcing it in "Undeclared symbol" warnings the
    whole time.
    Declarations reordered (rgb_out up with cx/cy before the hdmi instance;
    hdmi_active/hdmi_border before the FIFO that reads them), the top's benign
    vblank forward-reference cleaned to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
    [ddr3_framebuffer.v]
2026-07-20 HDMI confirmed working on hardware; strip diagnostics, rebuild games
    White border + game verified on screen: 720p over the restructured
    single-chain-clocked DDR3 framebuffer, frame store intact, HDMI audio
    carried. The border overlay is removed and a FIFO underrun now paints the
    pillar grey (invisible degradation) instead of magenta.
    TODO.md closes the HDMI saga with all four stacked root causes - reset
    gated on ROM loading, IDE Place_Option, gbatang's cross-PLL serializer
    clocking, and Gowin's implicit-1-bit-wire handling of use-before-declaration
    - every one invisible to the error log. CLAUDE.md records the two structural
    rules (PLL-sourced clk_g; single-chain TMDS clocks) and the diag/ s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
    [ddr3_framebuffer.v]
2026-07-20 Register core_reset; all six games rebuilt with real timing margin
    Satan's Hollow failed setup by a deterministic -0.349ns (identical on a
    fresh placement, so not seed luck). The path started at reset_cnt:
    core_reset was a combinational expression (reset_cnt != 0 || !rom_ready)
    fanning out to every synchronous reset in the Z80 core, and each addition
    over the sessions (the framebuffer gate, then the SD loader's rom_ready)
    grew the cone until one game's placement tipped it negative. It was
    near-critical in every build.
    core_reset is now a registered flop - one extra cycle of reset latency at
    power-on, in exchange for turning the fanout cone into a clean
    flop-to-flop stage.
    All six games reb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
2026-07-21 Fix USB dead on flash boot; rewrite README (flash + SD card + play)
    USB host reset was released 21 us after configuration and enumeration ran
    exactly once. A JTAG load starts the design on a long-powered board (pad
    already enumerated and idle) so it always worked; an SPI-flash boot starts
    ~200 ms after power-on while the pad's MCU is still booting, so the single
    enumeration hit a dead device and USB stayed down - the same bitstream
    working over JTAG and failing from flash. Now: reset held ~87 ms at
    power-on, and a sustained (~1.4 s) conerr from the host pulses reset and
    re-enumerates; with no pad plugged this is a harmless slow retry loop, and
    hot-plugged pads get picked up. usb_typ is surfa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
2026-07-21 SD prefs: the cabinet boots back into the owner's last-selected game
    sd_reader gains a CMD24 single-block write path (token, 512 streamed
    bytes, data-response check, busy wait with a 0.8 s cap). A failed write
    raises wr_err but still completes and returns to READY - a bad prefs
    write must never take down the reader or the running game.
    rom_loader: at power-on it first reads sector PACK_BASE-1 (2047); a valid
    "MCRPREF1" record overrides the baked-in default slot. On save_req (from
    the OSD, pulsed after every successful menu selection) it writes the
    record back. The prefs sector sits outside the pack image, so rewriting
    the pack keeps the preference. done stays high through a save, and the
    lo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
2026-07-21 Porting plan v2: grounded in the vendored MiSTer MCR cores (refs/)
    Survey of refs/Arcade-MCR{1,2,3,3Mono,3Scroll}_MiSTer replaces the
    speculative roadmap with verified facts: every core is our mcr2.vhd's
    sibling (same clock_40, same external ROM ports, same dl_ download bus
    the SD loader already drives), so the 60K platform carries over whole.
    Confirmed per family: MCR1 (Kick/Solar Fox) is all-BRAM and needs zero
    new hardware; all three MCR3 variants need the J9 SDRAM module (sprites
    128-256 KB; MiSTer's multi-port sdram.sv is in the refs, purpose-built);
    DoT speech was never implemented upstream (Squawk & Talk absent - Journey
    music is wave_sound.sv samples from a separate sample pack).
    Pl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
2026-07-22 Phase D: vendor + adapt the MCR3Scroll core; settle its design
    src/rtl/mcr3scroll.vhd (Spy Hunter, Crater Raider, Turbo Tag) vendored and
    patched like the others: the three gfx dprams (char + two bg) get INIT_FILE
    + we_a/we_b/d/q tie-offs, palette gets we_b/d_b, and hcnt_out is added (this
    core didn't expose the raster counter, unlike mcr3.vhd; its scanner is the
    same 633-wrap). Uses only vendorable entities, no Altera constructs.
    Verified the FX68K sound stack is Gowin-portable ahead of the board build:
    FX68K (fx68k.sv/fx68kAlu.sv/uaddrPla.sv + microrom/nanorom.mem) is generic
    SystemVerilog with $readmemb microcode - its only "altera" strings are
    message_off comment pragmas - and Cheap Squ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
2026-07-22 Shield pinout: review against the now-vendored full MCR family
    Checked the header against the real MCR-3/Scroll/Mono cores instead of the
    earlier guesses. The 40-pin header, AHC-direct input stage and chain
    architecture all hold up; three allocation/width fixes were needed:
    - Allocate the '165 input chain by SSIO input PORT (IP0-IP4, one device
    each), not by MCR-2 function. Verified in mcr3.cpp that the mono/scroll
    boards route IP ports to different cabinet connectors than the SSIO board
    (mono: IP0/IP1->J2, IP2->J3, IP4->J4). Port-based allocation serves every
    family and is simpler than the old 7-device hybrid (which split P1 and
    left P2 a bit short). The old device tables are rel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
2026-07-22 shield_wiring: correct connector pitches + J-numbering (authoritative source)
    Vendor docs/MCR Series Pinouts.html (John Sanford's archived MCR reference)
    and rebuild §1 from it. Two corrections to what I had wrong:
    - PITCH: only J1 (power) is .156" MTA; EVERY signal connector - J2 video,
    J3 audio, J4/J5/J6 inputs - is .100" MTA (2.54mm). I had said .156 for
    the whole harness; that was backwards.
    - J-NUMBERING: use the real board numbering, which matches MAME's ssio:IP*
    comments (J4=IP0+IP1 19-pin, J5=IP2 23-pin, J6=IP4 10-pin, J2=video,
    J1=power, J3=audio+volume). The "Master Pinout Matrix" PDF used a
    normalized cabinet-function numbering (its J2=P1, J4=OptX) that conflicts
    wit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
2026-07-22 SDRAM verified on hardware — Phase B done, MCR-3 unblocked
    The Tang SDRAM module memtest PASSED on hardware (2026-07-22): PASS LED on
    J10-21 steady high (mt_done & mt_pass = completed + all words matched),
    beacon c1. The only fix was the SDRAM_CLK phase - initial 180 deg failed
    (module responded but returned wrong data), 0 deg (sdram_gw ODDR D0=1/D1=0)
    made all reads correct. Roadmap Phase B -> DONE, TODO + handoff hardware
    table updated. MCR-3 board builds are now on a proven memory foundation;
    Tapper is the next target.
2026-07-23 MCR-3 sprites: disprove the v6 refresh-starvation root cause
    The v6 conclusion ("AUTO_REFRESH at ~2,325/s instead of ~133,000/s") was a
    measurement artifact, not a fault. dbg_refresh is 16-bit and the beacon's
    E1 slot only appears every ~1.9 s, so at 133k/s the counter wraps ~4x
    between samples and the delta is noise. Proof: re-scaling the counter by
    256 left the observed rate unchanged at ~2,451/s -- a real measurement must
    fall 256x.
    Re-measured with a windowed counter (refreshes latched per fixed 2^23-cycle
    window, so it cannot wrap): ~146,000 refresh/s = all 8192 rows every
    55.9 ms, inside the 64 ms JEDEC limit. Refresh is healthy.
    Also measured, and trustworthy because a true zero can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
2026-07-24 MCR-3 boot bug SOLVED + HALT watchdog; sprite corruption isolated
    Boot bug (cold power-on -> black screen until late reset):
    - Root cause: the Z80 CRASHES during early init on cold boots - wild jump
    into the sprite data table at ~AF40, executes junk, hits the 0x76 byte at
    AF7B and HALTs (bus parks at AF7C - measured via rom_addr snapshots; page
    trail shows it comes from page 00, i.e. IM2 vector dispatch territory).
    The raster free-runs fine at exactly 60.0 Hz throughout - every earlier
    "wrong vblank rate" reading (69.5/80.8/316/...) was an analysis artifact:
    the serial buffer flushes stale early-boot lines stamped t=0 and the
    endpoint average divided a boot-age counter jump by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
2026-07-24 SDRAM module EXONERATED: nand2mario controller retains perfectly (0 errors)
    Retention experiment (user's call - and they were right): vendored
    snestang's sdram_cl2_2ch.v unmodified, snestang clocking arrangement
    including the 225-degree phase-shifted pin clock (assign O_sdram_clk =
    fclk_p, a plain PLL output - no ODDR), 65MHz, write-once-verify-every-30s
    harness on the same module/socket/board:
    pass 2: 0/4096 errors pass 3: 0/4096 errors (~100s data age)
    Under sdram_gw the identical age reads 100% FF. The module is fine; the
    attribution in ca191ef ("module fails row-retention semantics") is
    RETRACTED - its measurements stand, the conclusion was wrong. The prime
    suspect is now sdram_gw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
2026-07-24 MCR-3 TAPPER SPRITES WORKING - fix was the SDRAM pin-clock phase (225 deg)
    The screen shows the full attract mode: bartender, patrons, mugs, the
    Budweiser sign - every sprite correct. Verified via HDMI capture and the
    sweep monitor (allff_lo = 47 vs the 51 all-FF words a perfect image
    contains; previously 16384 = all dead).
    Root cause of the entire white-sprites saga: sdram_gw forwarded SDRAM_CLK
    at 0 degrees (ODDR D0=1/D1=0), putting the chip's command sampling on the
    same instant commands change - a margin that drifts with temperature and
    activity. Every nand2mario design drives this module's clock pin from a
    ~225-degree-shifted PLL output (snestang: assign O_sdram_clk = fclk_p).
    Proven i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
2026-07-24 HDMI audio at 32kHz: 48k was a lie that made receivers resync
    74.25MHz/48000/2 truncates to 773 -> true sample rate 48027Hz against ACR
    constants declaring exactly 48000; receivers' regenerated audio clock
    drifts until they blink (the periodic cutouts, much rarer with islands
    off). 32000 divides ~5x more exactly. nand2mario hit the identical issue:
    nes2hdmi.sv comments 'weird only 32K sampling rate works'. Audio (DVI_MODE
    0) restored; flash updated and verified.
    [ddr3_framebuffer.v]
2026-07-25 Revert "HDMI audio at 32kHz: 48k was a lie that made receivers resync"
    This reverts commit 2bee7ea5fa60b82b38fddc044a7bd32923c40fc9.
    [ddr3_framebuffer.v]
2026-07-25 TODO: product roadmap - HDMI fix, all-from-SD, full MCR series, multiboot core switching, persisted selection, universal cabinet-button menu chord
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2026-07-25 Pack format v2: one SD card serves all families (roadmap item 2, part 1)
    rom_loader auto-detects "MCRPACK1"/"MCRPACK2" at sector 2048. v2: 16-byte
    mini-entries in the superblock {family,type,slot,start_lba,sector_count},
    18-bit dl_addr, variable payload sizes, FAMILY parameter per top
    (mcr1=0, mcr2=1, mcr3=2). v1 path untouched - verified on hardware: the
    v2-capable MCR-3 build runs the existing v1 card identically (attract
    demo, sprites, colors all correct). Flash updated (verified).
    MCR-3 goes full-from-SD on a v2 card: dl regions route CPU 64K -> BSRAM,
    snd 16K -> BSRAM, bg 2x16K -> core dl bus, sprites 128K -> SDRAM (offset
    0x1C000); on v1 cards everything still streams to SDRAM as befo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
2026-07-25 Add Timber (roadmap item 3, first new title on the working MCR-3 core)
    Timber (1984, mcr_91490 = the Tapper board, ROT0), everything from MAME
    0.265 mcr.cpp: ROM load order (NOTE: gfx1 planes load timbg1-then-timbg0,
    REVERSED vs tapper - per-game MAME order is the law, a fixed bg0-first
    convention caused the tapper color bug), input map (4-way stick + two chop
    buttons on IP1/IP2, DIP 0xFB = upright/demo-sounds-on), OSD entry (slot 1),
    pack roster (fam2 slot1, 480 sectors).
    Not yet hardware-tested: Timber's ROMs live only in the v2 pack, so first
    play happens after the v2 card is written on the Mac
    (tools/make_pack_v2.py -> tools/write_pack_v2.py). Tapper remains the
    baked-in card-less defau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
2026-07-26 v2 card path: fix bg plane routing (card-loaded games showed swapped colors)
    Root cause of the first v2-card session's "sprites don't seem quite
    right": the core's bg dprams have CROSSED wiring upstream - the dpram
    INIT'd from rom_gfx1_1.hex is written by dl range "01" and vice versa.
    Our v2 region router sent blob plane 1 to range "00", so CARD-loaded
    games had their bg planes swapped (the old orange-wall colors) while
    BAKED boots were correct - which is why the color fix looked done when
    verified on the baked path. Selector flipped to dl_bg1_rng.
    Verified on hardware via the capture card, card-loaded boot: wall
    (0,0,115) blue, Budweiser sign red, floor gray, bars brown - reference-
    correc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
2026-07-26 HDMI dropouts: fix the 48k-vs-32k audio rate lie - 3-5x fewer dropouts
    The framebuffer generated its audio sample clock at 48 kHz (localparam
    AUDIO_RATE) while telling the HDMI stack's ACR/channel-status 32 kHz
    (AUDIO_OUT_RATE) - a 50% rate mismatch that kept receivers' audio buffers
    in permanent distress and caused the periodic resyncs. Both now 32 kHz.
    Measured with the capture card (150-frame standardized runs):
    baseline (rate lie): 14% content frames
    consistent 32 kHz: 41-69% content frames
    A fractional-exact divider was tried and REVERTED: clk_audio is used as a
    real clock downstream and the accumulator's 13.5 ns edge jitter made
    dropouts worse (47%/22%); the intege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
    [device.cfg]
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2026-07-27 Merged MCR-2 + MCR-3 core: one bitstream, nine games
    mcr23_console60k builds and RUNS. 114/118 BSRAM, ~19.9k of 60k LUT, TNS
    0.000, no undeclared symbols, only the accepted gowin_pll_hdmi PA1019.
    Verified on hardware: it booted straight into Two Tigers, an MCR-2 game,
    because the SD prefs named family 1 slot 4 - i.e. the whole cross-family
    path worked end to end. All three region checksums match twotiger exactly
    (cpu 3D1B, bg1 63EA, bg2 8B58), so the MCR-2 payload layout was decoded
    correctly inside a top derived from the MCR-3 board, and the roster
    translation put it at index 7 (3 + slot 4). Screen shows Two Tigers running.
    Architecture:
    - flat OSD roster index <-> (family, slot) transla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
    [device.cfg]
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2026-07-29 Fix HDMI PLL VCO; add working ascal_v scaler + drop-in ascal_fb
    Two independent faults closed, plus a second usable scaler.
    HDMI PLL VCO was out of spec (fixes sync loss on EVERY core)
    ------------------------------------------------------------
    gowin_pll_hdmi27.v ran MDIV=55 / ODIV0=4 -> VCO 1485 MHz, outside the
    GW5A 700-1400 MHz range. This was recorded in CLAUDE.md for months as an
    "accepted PA1019 warning" because NESTang ships it. It was not benign: it
    was the long-standing HDMI dropout. Sync held for minutes after
    configuration, then went marginal, and recovered on every reconfig -
    which is why measurements taken just after flashing always looked clean.
    Analog VGA never dropped becau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
    [device.cfg]
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
